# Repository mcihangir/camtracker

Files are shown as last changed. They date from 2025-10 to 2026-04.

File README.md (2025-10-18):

# SmartNFC

## Description
**SmartNFC** is an Android Virtual POS Application designed to operate on Android 13/14.

## Project Information
- **Project Name**: SmartNFC
- **Description**: Android Virtual POS Application
- **Start Date**: 2024-06-17
- **Firmware/SDK Version**: Android 13/14
- **Hardware Version**: v1.0

## Folder Structure
The project follows the directory structure outlined below:

```
SmartNFC/
│-- Block Diagrams/        # Product Block Diagram, PCB Connector Position
│-- Product Tree/          # Product Tree
│-- Documents/             # Design Documents, User Manuals, etc.
│-- Hardware/              # PCB Design Sources and libraries
│-- Software/              # Firmware and Applications
│-- Tools/                 # Software Tools
│-- Data/                  # Manufacturing data (PCB Gerber, Firmware Images, etc.)
```

## Folder Descriptions
- **Block Diagrams/**: Contains product-level block diagrams and PCB connector positioning.
- **Product Tree/**: Hierarchical structure of the product components.
- **Documents/**: Includes all necessary datasheets related to the hardware components and design documents.
- **Hardware/**: Contains PCB design source files and libraries.
- **Software/**: Includes firmware and application source code.
- **Tools/**: Collection of software tools required for development and debugging.
- **Data/**: Stores manufacturing data, including PCB Gerber files and firmware images.

## License
TBD

## Contact
For more details, reach out to the development team.

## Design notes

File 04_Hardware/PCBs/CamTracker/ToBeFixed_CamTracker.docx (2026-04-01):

1. D8 and D4 diodes should be replaced with a MOSFET-based solution or a proper power OR-ing design.

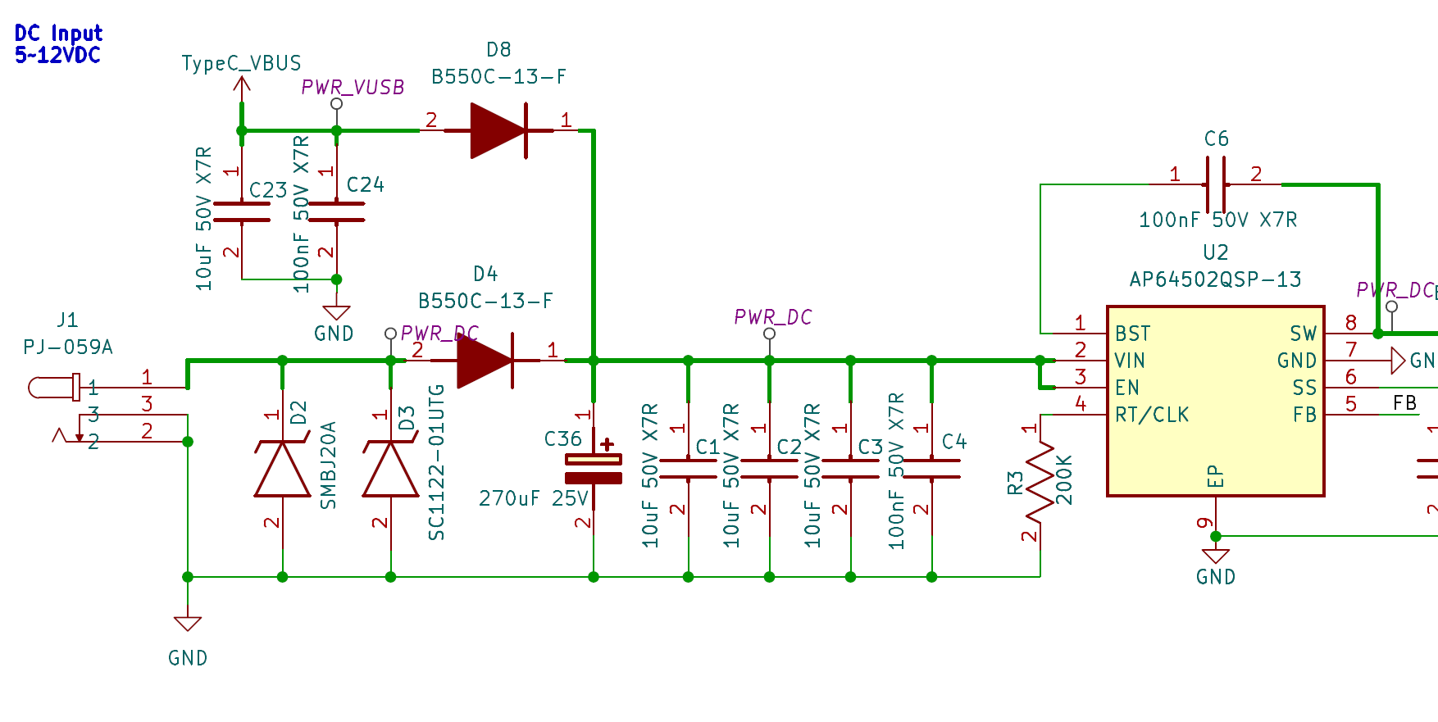
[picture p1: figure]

2. The R112 resistor should be set to 10K.

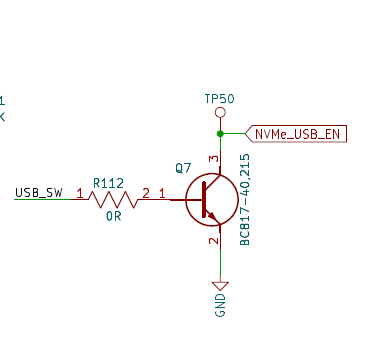
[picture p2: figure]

3. The D1 diode should be replaced with a MOSFET-based switching circuit.

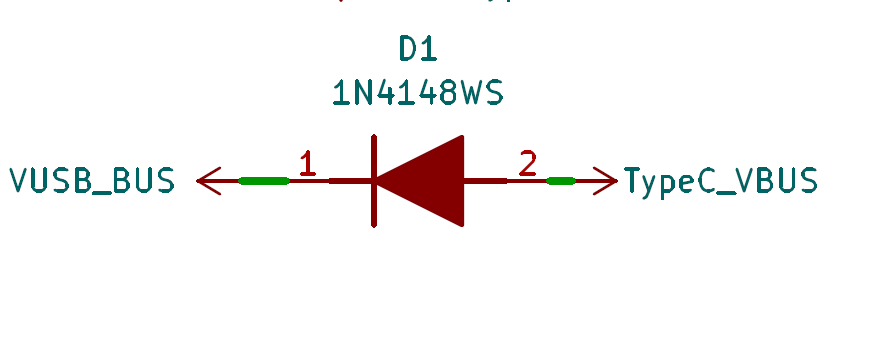
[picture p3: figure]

4. C149 should be used as 2.2 µF.

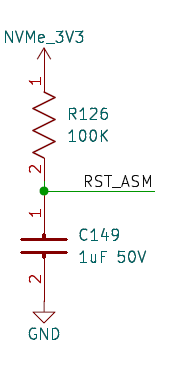
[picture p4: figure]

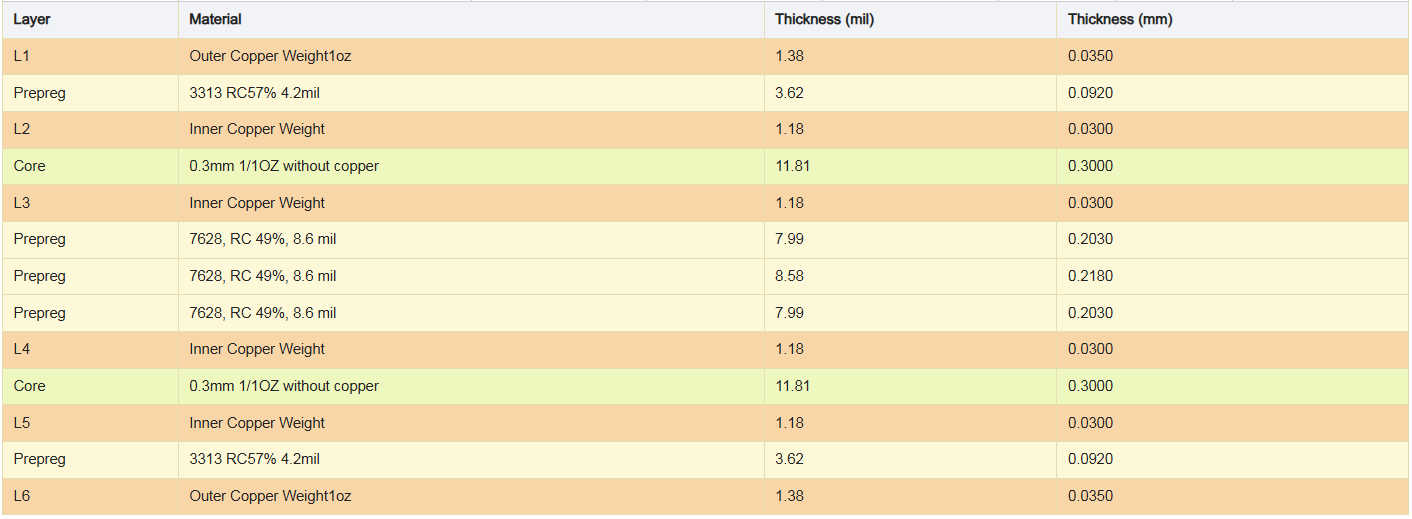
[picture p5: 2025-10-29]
04_Hardware/PCBs/CamTracker/Stackup.png

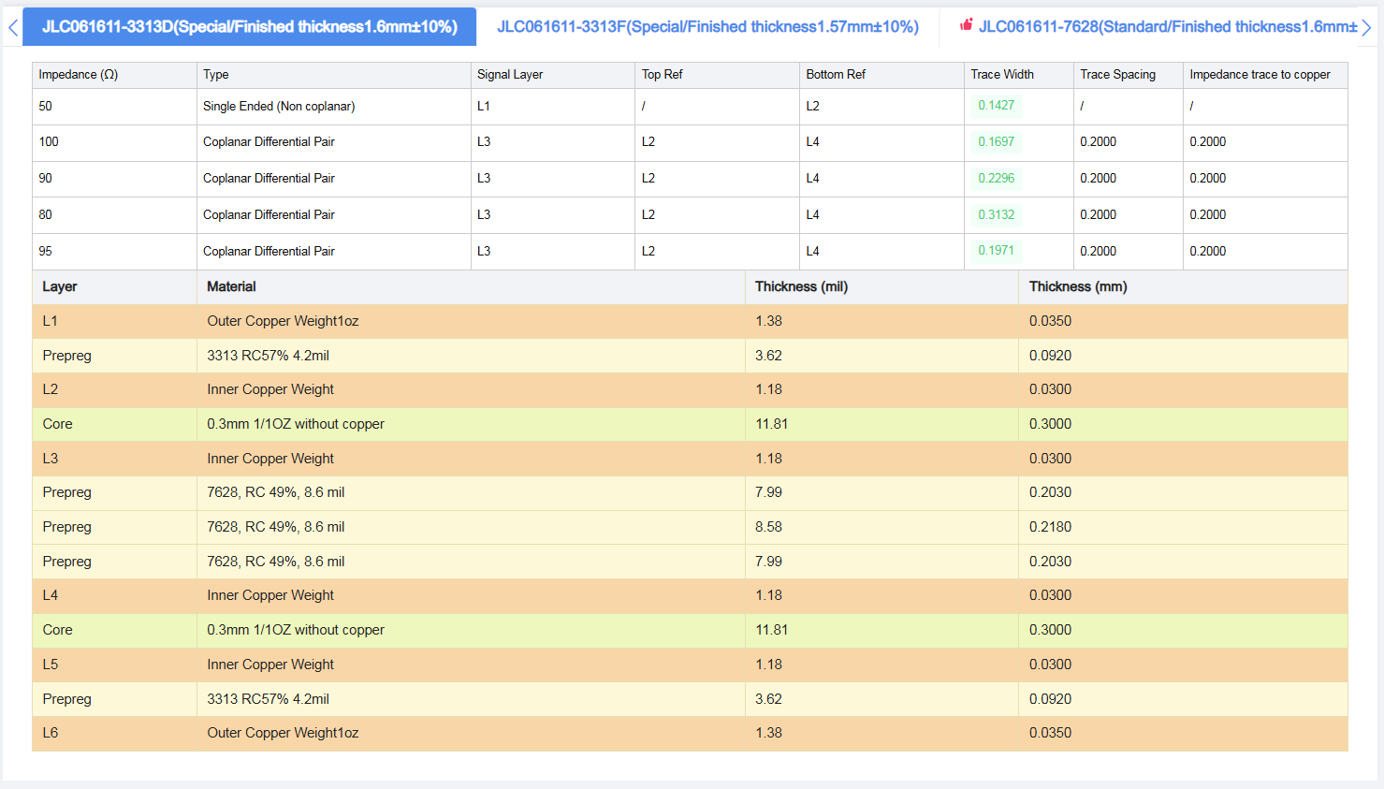
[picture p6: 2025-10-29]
04_Hardware/PCBs/CamTracker/Impedance.png

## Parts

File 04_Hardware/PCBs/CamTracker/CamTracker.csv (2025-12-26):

'#' | 'Reference' | 'Value' | 'Manufacturer' | 'Part Number' | 'Qty'
'1' | 'C1,C2,C3,C23,C25,C26,C27,C33,C34,C43,C122,C123,C124' | '10uF 50V X7R' | 'SAMSUNG' | 'CL31B106KBK6PJE' | '13'
'2' | 'C4,C6,C24' | '100nF 50V X7R' | 'TAIYO YUDEN' | 'UMK105B7104KVHF' | '3'
'3' | 'C5,C105' | '22uF 6.3V' | 'Murata Electronics' | 'GRM158R60J226ME01D' | '2'
'4' | 'C7,C11,C21,C29,C31,C35,C41,C45,C52,C57,C59,C73,C86,C87,C112,C113,C149' | '1uF 50V' | 'Murata Electronics' | 'GRM155R61H105KE05D' | '17'
'5' | 'C8,C10,C61,C68,C100,C106,C108,C109,C110' | '33pF 50V' | 'Murata Electronics' | 'GRM1555C1H330JA01D' | '9'
'6' | 'C9,C38' | '10nF 50V' | 'Murata Electronics' | 'GRM155R71H103KA88D' | '2'
'7' | 'C12,C13,C14,C22,C30,C32,C40,C46,C51,C53,C55,C65,C75,C84,C85,C88,C89,C90,C91,C92,C93,C94,C95,C101,C102,C104,C111,C125,C126,C127,C128,C129,C130,C131,C132,C133,C134,C135,C139,C140,C141,C142,C147' | '100nF 10V' | 'Murata Electronics' | 'GRM155R71A104KA01D' | '43'
'8' | 'C15' | '4.7uF 50V' | 'TAIYO YUDEN' | 'UMK325BJ475MM-T' | '1'
'9' | 'C16' | '100uF 10V' | 'KEMET' | 'T495D107K010ATE080' | '1'
'10' | 'C17,C18,C19,C20,C28,C66' | '47uF 10V X7S' | 'TDK' | 'CGA6P1X7S1A476M250AC' | '6'
'11' | 'C36' | '270uF 25V' | 'Panasonic' | '25SVPG270M' | '1'
'12' | 'C37,C103,C148' | '10pF 50V' | 'Murata Electronics' | 'GRM1555C1H100JA01D' | '3'
'13' | 'C42' | '4.7uF 10V' | 'TAIYO YUDEN' | 'LMK107BJ475KA-T' | '1'
'14' | 'C44,C98,C99' | '10uF 6.3V' | 'Murata Electronics' | 'GRM155R60J106ME15D' | '3'
'15' | 'C62,C63,C64,C67,C69,C70' | '22pF 50V' | 'Murata Electronics' | 'GRM1555C1H220JA01D' | '6'
'16' | 'C80,C107' | '100pF 50V' | 'Murata Electronics' | 'GRM1555C1H101JA01J' | '2'
'17' | 'C82,C83' | '15pF 50V' | 'Murata Electronics' | 'GRM1555C1H150JA01D' | '2'
'18' | 'C96,C97' | '1nF 50V' | 'Murata Electronics' | 'GRM1555C1H102JA01D' | '2'
'19' | 'C118,C119,C120,C121,C143,C144,C145,C146' | '220nF 10V' | 'Murata Electronics' | 'GRM155R61A224JE19D' | '8'
'20' | 'C136,C138' | '2.2uF 10V' | 'TAIYO YUDEN' | 'LMK107BJ225KA-T' | '2'
'21' | 'C137' | '22uF 25V' | 'Murata Electronics' | 'GRM21BR61E226ME44L' | '1'
'22' | 'D1' | '1N4148WS' | 'Onsemi' | '1N4148WS' | '1'
'23' | 'D2' | 'SMBJ20A' | 'Bourns' | 'SMBJ20A' | '1'
'24' | 'D3' | 'SC1122-01UTG' | 'LITTELFUSE' | 'SC1122-01UTG' | '1'
'25' | 'D4,D8' | 'B550C-13-F' | 'Diodes Incorporated' | 'B550C-13-F' | '2'
'26' | 'D5' | 'RB751S40' | 'ON Semiconductor' | 'RB751S40' | '1'
'27' | 'D6,D12' | 'SC1105-01UTG' | 'LITTELFUSE' | 'SC1105-01UTG' | '2'
'28' | 'D7' | 'ESD9B5.0ST5G' | 'ON Semiconductor' | 'ESD9B5.0ST5G' | '1'
'29' | 'D9,D19,D20,D21,D22,D23,D25,D26,D27,D28,D29,D30' | 'SC1205-01ETG' | 'Littelfuse' | 'SC1205-01ETG' | '12'
'30' | 'D11,D18' | 'SP0402U-ULC-02ETG' | 'LITTELFUSE' | 'SP0402U-ULC-02ETG' | '2'
'31' | 'D24' | 'SRV05-4.TCT' | 'SEMTECH' | 'SRV05-4.TCT' | '1'
'32' | 'FB1,FB2,FB3' | '110Ohm 1200mA' | 'Wurth Elektronik' | '74269242111' | '3'
'33' | 'FL1,FL2,FL3,FL4,FL5,FL6' | 'LCFE121002A900TG' | 'LITTELFUSE' | 'LCFE121002A900TG' | '6'
'34' | 'IC1' | 'W25Q128JVSIM' | 'Winbond' | 'W25Q128JVSIM' | '1'
'35' | 'IC2,IC3' | 'AP7361E-33FGE-7' | 'Diodes Incorporated' | 'AP7361E-33FGE-7' | '2'
'36' | 'J1' | 'PJ-059A' | 'CUI Devices' | 'PJ-059A' | '1'
'37' | 'J2,J3,J21' | '67996-100HLF' | 'Amphenol Communications Solutions' | '67996-100HLF' | '3'
'38' | 'J4' | '~' | 'SHOU HAN(首韩)' | '1.25-4P LT' | '1'
'39' | 'J5' | '22-28-4034' | 'Molex' | '22-28-4034' | '1'
'40' | 'J6' | '2345986-1' | 'TE Connectivity' | '2345986-1' | '1'
'41' | 'J8,J9' | 'HX JN1.27-2X10 TP H4.9' | 'hanxia(韩下)' | 'HX JN1.27-2x10 TP H4.9' | '2'
'42' | 'J10,J15,J16,J17' | '1909763-1' | 'TE Connectivity' | '1909763-1' | '4'
'43' | 'J13' | '2336582-1' | 'TE Connectivity' | '2336582-1' | '1'
'44' | 'J18' | '2201778-1' | 'TE Connectivity' | '2201778-1' | '1'
'45' | 'J19' | '2174507-2' | 'TE Connectivity' | '2174507-2' | '1'
'46' | 'J27' | '53047-0210' | 'Molex' | '53047-0210' | '1'
'47' | 'J28' | 'Bus_M.2_Socket_M' | 'TE Connectivity' | '1-2199230-4' | '1'
'48' | 'L1' | 'ETQ-P4M6R8KVC 6.8uH 6.9A' | 'Panasonic' | 'ETQ-P4M6R8KVC' | '1'
'49' | 'L2' | '1uH 4.2A' | 'TAIYO YUDEN' | 'LSEUC3225HKT1R0M' | '1'
'50' | 'L4,L6' | '600ohm 100MHz' | 'Wurth Elektronik' | '7427927291' | '2'
'51' | 'L8' | '56nH' | 'Wurth Elektronik' | '744784156A' | '1'
'52' | 'L10' | '1uH 2.2A' | 'Wurth Elektronik' | '74404024010' | '1'
'53' | 'LED1' | 'SML-P11YTT86R' | 'ROHM Semiconductor' | 'SML-P11YTT86R' | '1'
'54' | 'LED2,LED4,LED5' | 'SML-P11VTT86R' | 'ROHM Semiconductor' | 'SML-P11VTT86R' | '3'
'55' | 'LED3' | 'LTPL-C0676WPGB' | 'Lite-On Inc.' | 'LTPL-C0676WPGB' | '1'
'56' | 'LS1' | 'SPKM.15.8.A' | 'Taoglas' | 'SPKM.15.8.A' | '1'
'57' | 'MK1' | 'CMM-3729AT-42316-TR' | 'Same Sky' | 'CMM-3729AT-42316-TR' | '1'
'58' | 'Q1,Q2,Q3,Q4,Q5,Q6,Q7,Q8,Q9,Q10,Q11' | 'BC817-40,215' | 'Nexperia' | 'BC817-40,215' | '11'
'59' | 'R2,R10' | '47K' | 'YAGEO' | 'RC0402JR-0747KL' | '2'
'60' | 'R3,R107,R127' | '200K' | 'YAGEO' | 'RC0402FR-07200KL' | '3'
'61' | 'R4' | '38K3' | 'YAGEO' | 'AF0402FR-0738K3L' | '1'
'62' | 'R5,R7,R15,R17,R21,R24,R28,R29,R30,R40,R41,R42,R43,R44,R45,R46,R47,R48,R49,R52,R54,R74,R84,R97,R98,R100,R101,R103,R105,R114,R115,R116,R120,R121' | '10K' | 'YAGEO' | 'RC0402JR-0710KL' | '34'
'63' | 'R6,R12,R13,R31,R50,R55,R56,R57,R58,R87,R112' | '0R' | 'Vishay' | 'CRCW08050000Z0EA' | '11'
'64' | 'R9' | '147K' | 'YAGEO' | 'RC0402FR-07147KL' | '1'
'65' | 'R11,R25,R33,R96,R99' | '4K7' | 'YAGEO' | 'RC0402JR-074K7L' | '5'
'66' | 'R18,R51,R53,R85,R86,R88,R89,R90,R102,R106,R110,R111' | '0R' | 'YAGEO' | 'RC0402JR-070RL' | '12'
'67' | 'R22,R64,R75,R126' | '100K' | 'YAGEO' | 'RC0402JR-07100KL' | '4'
'68' | 'R27' | '270K' | 'YAGEO' | 'RC0402FR-07270KL' | '1'
'69' | 'R32,R36,R37,R38,R39,R63,R91,R95' | '1K' | 'YAGEO' | 'RC0402JR-071KL' | '8'
'70' | 'R34' | '20K' | 'YAGEO' | 'RC0402JR-0720KL' | '1'
'71' | 'R35' | '27K' | 'YAGEO' | 'RC0402JR-0727KL' | '1'
'72' | 'R59,R60,R61,R62' | '2K2' | 'YAGEO' | 'RC0402JR-072K2L' | '4'
'73' | 'R65,R66,R67,R81,R82,R83' | '22R' | 'YAGEO' | 'RC0402JR-0722RL' | '6'
'74' | 'R68,R69,R70,R71,R72,R73' | '33R' | 'YAGEO' | 'RC0402JR-0733RL' | '6'
'75' | 'R76,R77,R78,R79,R80' | '51K' | 'YAGEO' | 'RC0402JR-0751KL' | '5'
'76' | 'R93,R94' | '27.4R' | 'YAGEO' | 'RC0402FR-0727R4P' | '2'
'77' | 'R104' | '56K' | 'YAGEO' | 'RC0402JR-0756KL' | '1'
'78' | 'R108' | '44K2' | 'YAGEO' | 'RC0402FR-0744K2L' | '1'
'79' | 'R109' | '5K1' | 'YAGEO' | 'RC0402JR-075K1L' | '1'
'80' | 'R125' | '12K1' | 'YAGEO' | 'RC0402FR-0712K1P ' | '1'
'81' | 'S1,S2,S3' | '436333033816' | 'Wurth Elektronik' | '436333033816' | '3'
'82' | 'S4' | 'JS102011JCQN' | 'CK COMPONENTS' | 'JS102011JCQN' | '1'
83' | 'U1' | 'SC206EEMDA-G51-UGNDA' | 'Quectel' | 'SC200EEMNA-E53-UGNDA' | '1'
84' | 'U2' | 'AP64502QSP-13' | 'Diodes Incorporated' | 'AP64502QSP-13' | '1'
85' | 'U3' | 'AP7335-WG-7' | 'Diodes Incorporated' | 'AP7335-WG-7' | '1'
86' | 'U6,U15' | 'AP61100Z6-7,AP61300Z6-7' | 'Diodes Incorporated' | 'AP61100Z6-7' | '2'
87' | 'U7,U9' | 'PI3USB4000DZUAEX' | 'Diodes Incorporated' | 'PI3USB4000DZUAEX' | '2'
88' | 'U10' | 'SGM804' | 'SGMICRO(圣邦微)' | 'SGM804-2.93YN5G/TR' | '1'
89' | 'U12' | 'RP2040' | 'RASPBERRY-PI' | 'SC0914(7)' | '1'
90' | 'U13' | 'PAM8302AASCR' | 'Diodes Incorporated' | 'PAM8302AASCR' | '1'
91' | 'U14' | 'ASM2362' | 'ASMedia' | 'ASM2362' | '1'
92' | 'Y1' | 'ABM8-272-T3' | 'ABRACON' | 'ABM8-272-T3' | '1'
93' | 'Y2' | '25MHz' | 'Diodes Incorporated' | 'FL2500188' | '1'

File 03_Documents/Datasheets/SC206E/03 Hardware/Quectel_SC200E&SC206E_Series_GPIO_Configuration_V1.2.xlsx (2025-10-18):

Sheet: Title Page
SC200E&SC206E Series
GPIO Configuration
Smart Module Series
Version: 1.2
Date: 2023-01-17
Status: Released

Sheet: Foreword
At Quectel, our aim is to provide timely and comprehensive services to our customers. If you require any assistance, please contact our headquarters:
Quectel Wireless Solutions Co., Ltd.
Building 5, Shanghai Business Park Phase III (Area B), No.1016 Tianlin Road, Minhang District, Shanghai 200233, China
Tel: +86 21 5108 6236
Email: info@quectel.com
Or our local office. For more information, please visit:
http://www.quectel.com/support/sales.htm
For technical support, or to report documentation errors, please visit:
http://www.quectel.com/support/technical.htm
Or email to: support@quectel.com
Legal Notices
We offer information as a service to you. The provided information is based on your requirements and we make every effort to ensure its quality. You agree that you are responsible for using independent analysis and evaluation in designing intended products, and we provide reference designs for illustrative purposes only. Before using any hardware, software or service guided by this document, please read this notice carefully. Even though we employ commercially reasonable efforts to provide the best possible experience, you hereby acknowledge and agree that this document and related services hereunder are provided to you on an “as available” basis. We may revise or restate this document from time to time at our sole discretion without any prior notice to you.
Use and Disclosure Restrictions
License Agreements
Documents and information provided by us shall be kept confidential, unless specific permission is granted. They shall not be accessed or used for any purpose except as expressly provided herein.
Copyright
Our and third-party products hereunder may contain copyrighted material. Such copyrighted material shall not be copied, reproduced, distributed, merged, published, translated, or modified without prior written consent. We and the third party have exclusive rights over copyrighted material. No license shall be granted or conveyed under any patents, copyrights, trademarks, or service mark rights. To avoid ambiguities, purchasing in any form cannot be deemed as granting a license other than the normal non-exclusive, royalty-free license to use the material. We reserve the right to take legal action for noncompliance with abovementioned requirements, unauthorized use, or other illegal or malicious use of the material.
Trademarks
Except as otherwise set forth herein, nothing in this document shall be construed as conferring any rights to use any trademark, trade name or name, abbreviation, or counterfeit product thereof owned by Quectel or any third party in advertising, publicity, or other aspects.
Third-Party Rights
This document may refer to hardware, software and/or documentation owned by one or more third parties (“third-party materials”). Use of such third-party materials shall be governed by all restrictions and obligations applicable thereto.
We make no warranty or representation, either express or implied, regarding the third-party materials, including but not limited to any implied or statutory, warranties of merchantability or fitness for a particular purpose, quiet enjoyment, system integration, information accuracy, and non-infringement of any third-party intellectual property rights with regard to the licensed technology or use thereof. Nothing herein constitutes a representation or warranty by us to either develop, enhance, modify, distribute, market, sell, offer for sale, or otherwise maintain production of any our products or any other hardware, software, device, tool, information, or product. We moreover disclaim any and all warranties arising from the course of dealing or usage of trade.
Privacy Policy
To implement module functionality, certain device data are uploaded to Quectel’s or third-party’s servers, including carriers, chipset suppliers or customer-designated servers. Quectel, strictly abiding by the relevant laws and regulations, shall retain, use, disclose or otherwise process relevant data for the purpose of performing the service only or as permitted by applicable laws. Before data interaction with third parties, please be informed of their privacy and data security policy.
Disclaimer
a) We acknowledge no liability for any injury or damage arising from the reliance upon the information
b) We shall bear no liability resulting from any inaccuracies or omissions, or from the use of the information contained herein.
c) While we have made every effort to ensure that the functions and features under development are free from errors, it is possible that they could contain errors, inaccuracies, and omissions. Unless otherwise provided by valid agreement, we make no warranties of any kind, either implied or express, and exclude all liability for any loss or damage suffered in connection with the use of features and functions under development, to the maximum extent permitted by law, regardless of whether such loss or damage may have been foreseeable.
d) We are not responsible for the accessibility, safety, accuracy, availability, legality, or completeness of information, advertising, commercial offers, products, services, and materials on third-party websites and third-party resources.
Copyright © Quectel Wireless Solutions Co., Ltd. 2023. All rights reserved.

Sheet: Revision History
Version | Date | Author | Description
- | 2021-08-05 | Dorian MENG | Creation of the document
1.0 | 2022-01-19 | Dorian MENG | First official release
1.1 | 2022-07-19 | Dorian MENG | Added applicable module: SC206E series.
1.2 | 2023-01-17 | Dorian MENG | Deleted the VBAT power domain of PMU_GPIO03 and PMU_GPIO04.

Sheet: GPIO Configuration
Interface | Pin No. | Pin Name | Pin Description (Default Function) | Power Domain | Wakeup | Status After Reset | Alternate Function 0 (GPIO No.) | Alternate Function 1 | Alternate Function 2 | Alternate Function 3 | Alternate Function 4 | Comment
GPIO | 33 | GPIO_28 | General-purpose input/output | 1.8 V | √ | B-PD:nppukp | GPIO_28 | CAM_MCLK3 | CCI_TIMER2 | - | -
 | 97 | GPIO_31 | General-purpose input/output | 1.8 V | √ | B-PD:nppukp | GPIO_31 | - | - | - | -
 | 99 | GPIO_32 | General-purpose input/output | 1.8 V | √ | B-PD:nppukp | GPIO_32 | - | CCI_TIMER3 | - | -
 | 107 | GPIO_35 | General-purpose input/output | 1.8 V | √ | B-PD:nppukp | GPIO_35 | ALPS_INT | - | - | -
 | 108 | GPIO_33 | General-purpose input/output | 1.8 V | √ | B-PD:nppukp | GPIO_33 | GYRO_INT | - | - | -
 | 109 | GPIO_34 | General-purpose input/output | 1.8 V | √ | B-PD:nppukp | GPIO_34 | MAG_INT | - | - | -
 | 110 | GPIO_36 | General-purpose input/output | 1.8 V | √ | B-PD:nppukp | GPIO_36 | ACCL_INT | - | - | -
 | 100 | GPIO_55 | General-purpose input/output | 1.8 V | - | B-PD:nppukp | GPIO_55 | - | - | - | -
 | 106 | GPIO_56 | General-purpose input/output | 1.8 V | - | B-PD:nppukp | GPIO_56 | - | - | - | -
 | 112 | GPIO_57 | General-purpose input/output | 1.8 V | - | B-PD:nppukp | GPIO_57 | - | - | - | - | Cannot be pulled up during startup.
 | 113 | GPIO_58 | General-purpose input/output | 1.8 V | - | B-PD:nppukp | GPIO_58 | - | - | - | -
 | 123 | GPIO_60 | General-purpose input/output | 1.8 V | - | B-PD:nppukp | GPIO_60 | - | - | - | -
 | 182 | GPIO_86 | General-purpose input/output | 1.8 V | √ | B-PD:nppukp | GPIO_86 | NFC_CLK_REQ | - | - | -
 | 177 | GPIO_112 | General-purpose input/output | 1.8 V | √ | B-PD:nppukp | GPIO_112 | - | LPI_I2C5_SCL | LPI_UART5_RX | -
 | 267 | GPIO_111 | General-purpose input/output | 1.8 V | - | B-PD:nppukp | GPIO_111 | - | LPI_I2C5_SDA | LPI_UART5_TX | -
 | 265 | GPIO_98 | General-purpose input/output | 1.8 V | - | B-PD:nppukp | GPIO_98 | LPI_MI2S0_CLK | LPI_DMIC1_CLK | - | -
 | 105 | GPIO_99 | General-purpose input/output | 1.8 V | √ | B-PD:nppukp | GPIO_99 | LPI_MI2S0_WS | LPI_DMIC1_DATA | - | -
 | 264 | GPIO_100 | General-purpose input/output | 1.8 V | - | B-PD:nppukp | GPIO_100 | LPI_MI2S0_DATA0 | LPI_DMIC2_CLK | - | -
 | 239 | GPIO_101 | General-purpose input/output | 1.8 V | √ | B-PD:nppukp | GPIO_101 | LPI_MI2S0_DATA1 | LPI_DMIC2_DATA | - | -
 | 104 | GPIO_102 | General-purpose input/output | 1.8 V | √ | B-PD:nppukp | GPIO_102 | LPI_MI2S1_CLK | - | - | -
 | 103 | GPIO_103 | General-purpose input/output | 1.8 V | √ | B-PD:nppukp | GPIO_103 | LPI_MI2S1_WS | - | - | -
 | 101 | GPIO_104 | General-purpose input/output | 1.8 V | √ | B-PD:nppukp | GPIO_104 | LPI_MI2S1_DATA0 | - | - | -
 | 102 | GPIO_105 | General-purpose input/output | 1.8 V | √ | B-PD:nppukp | GPIO_105 | LPI_MI2S1_DATA1 | - | - | -
 | 90 | GPIO_106 | General-purpose input/output | 1.8 V | √ | B-PD:nppukp | GPIO_106 | - | - | - | -
 | 98 | GPIO_107 | General-purpose input/output | 1.8 V | √ | B-PD:nppukp | GPIO_107 | - | - | - | -
 | 118 | GPIO_14 | General-purpose input/output | 1.8 V | √ | B-PD:nppukp | GPIO_14 | SPI_MISO | UART_CTS | I2C_SDA | - | QUP SE5.
 | 119 | GPIO_15 | General-purpose input/output | 1.8 V | - | B-PD:nppukp | GPIO_15 | SPI_MOSI | UART_RTS | I2C_SCL | -
 | 116 | GPIO_16 | General-purpose input/output | 1.8 V | - | B-PD:nppukp | GPIO_16 | SPI_SCLK | UART_TX | - | -
 | 117 | GPIO_17 | General-purpose input/output | 1.8 V | √ | B-PD:nppukp | GPIO_17 | SPI_CS_N | UART_RX | - | -
 | 124 | PMU_GPIO03 | General-purpose input/output | 1.8 V | - | IN/PD | PMU_GPIO03 | - | - | - | -
 | 115 | PMU_GPIO04 | General-purpose input/output | 1.8 V | - | IN/PD | PMU_GPIO04 | - | - | - | -
 | 127 | PMU_GPIO08 | General-purpose input/output | 1.8 V | - | IN/PD | PMU_GPIO08 | - | - | - | -
 | 201 | PMU_GPIO07 | General-purpose input/output | 1.8 V | - | IN/PD | PMU_GPIO07 | - | - | - | -
SD Card | 45 | SD_DET | SD card hot-plug detect | 1.8 V | √ | B-PD:nppukp | GPIO_88 | - | - | - | -
(U)SIM | 22 | USIM1_DET | (U)SIM1 card hot-plug detect | 1.8 V | √ | B-PD:nppukp | GPIO_79 | - | - | - | -
 | 17 | USIM2_DET | (U)SIM2 card hot-plug detect | 1.8 V | √ | B-PD:nppukp | GPIO_75 | - | - | - | -
TP | 30 | TP_INT | TP interrupt | 1.8 V | √ | B-PD:nppukp | GPIO_80 | SPI_CS_N | UART_RX | - | - | QUP SE2.
 | 31 | TP_RST | TP reset | 1.8 V | - | B-PD:nppukp | GPIO_71 | SPI_SCLK | UART_TX | - | -
 | 47 | TP_I2C_SCL | TP I2C clock | 1.8 V | - | B-PD:nppukp | GPIO_7 | SPI_MOSI | UART_RTS | I2C_SCL | - | 1. Need to be pulled up to 1.8 V externally. 2. Can be used for other I2C devices. 3. QUP SE2.
 | 48 | TP_I2C_SDA | TP I2C data | 1.8 V | √ | B-PD:nppukp | GPIO_6 | SPI_MISO | UART_CTS | I2C_SDA | -
LCM | 49 | LCD_RST | LCD reset | 1.8 V | - | B-PD:nppukp | GPIO_82 | - | - | - | -
 | 50 | LCD_TE | LCD tearing effect | 1.8 V | √ | B-PD:nppukp | GPIO_81 | - | - | - | -
Camera | 74 | CAM0_MCLK | Master clock of camera 0 | 1.8 V | - | B-PD:nppukp | GPIO_20 | - | - | - | -
 | 75 | CAM1_MCLK | Master clock of camera 1 | 1.8 V | - | B-PD:nppukp | GPIO_21 | - | - | - | -
 | 165 | CAM2_MCLK | Master clock of camera 2 | 1.8 V | √ | B-PD:nppukp | GPIO_27 | - | - | - | -
 | 79 | CAM0_RST | Reset of camera 0 | 1.8 V | √ | B-PD:nppukp | GPIO_18 | - | - | - | -
 | 81 | CAM1_RST | Reset of camera 1 | 1.8 V | √ | B-PD:nppukp | GPIO_19 | - | - | - | -
 | 164 | CAM2_RST | Reset of camera 2 | 1.8 V | √ | B-PD:nppukp | GPIO_24 | CCI_TIMER1 | - | - | -
 | 80 | CAM0_PWDN | Power down of camera 0 | 1.8 V | √ | B-PD:nppukp | GPIO_4 | SPI_MISO | UART_CTS | I2C_SDA | - | QUP SE1.
 | 82 | CAM1_PWDN | Power down of camera 1 | 1.8 V | - | B-PD:nppukp | GPIO_5 | SPI_MOSI | UART_RTS | I2C_SCL | -
 | 163 | CAM2_PWDN | Power down of camera 2 | 1.8 V | - | B-PD:nppukp | GPIO_108 | - | - | - | -
 | 83 | CAM0_I2C_SCL | I2C clock of camera 0 | 1.8 V | - | B-PD:nppukp | GPIO_23 | CCI_I2C_SCL0 | - | - | - | 1. Need to be pulled up to 1.8 V externally. 2. For I2C application, these pins can only be used for camera I2C and can not be connected to other I2C devices.
 | 84 | CAM0_I2C_SDA | I2C data of camera 0 | 1.8 V | - | B-PD:nppukp | GPIO_22 | CCI_I2C_SDA0 | - | - | -
 | 166 | CAM1_I2C_SCL | I2C clock of camera 1 | 1.8 V | - | B-PD:nppukp | GPIO_30 | CCI_I2C_SCL1 | - | - | -
 | 205 | CAM1_I2C_SDA | I2C data of camera 1 | 1.8 V | - | B-PD:nppukp | GPIO_29 | CCI_I2C_SDA1 | - | - | -
Keypad | 95 | VOL_UP | Volume up | 1.8 V | √ | B-PD:nppukp | GPIO_96 | SPI_MISO | UART_CTS | I2C_SDA | - | QUP SE4.
 | 96 | VOL_DOWN | Volume down | 1.8 V | √ | B-PD:nppukp | GPIO_97 | SPI_MOSI | UART_RTS | I2C_SCL | -
UART | 93 | DBG_RXD | Debug UART receive | 1.8 V | √ | B-PD:nppukp | GPIO_13 | SPI_CS_N | UART_RX | - | - | QUP SE4.
 | 94 | DBG_TXD | Debug UART transmit | 1.8 V | - | B-PD:nppukp | GPIO_12 | SPI_SCLK | UART_TX | - | -
 | 34 | UART0_TXD | UART0 transmit | 1.8 V | - | B-PD:nppukp | GPIO_2 | SPI_SCLK | UART_TX | - | - | QUP SE0.
 | 35 | UART0_RXD | UART0 receive | 1.8 V | √ | B-PD:nppukp | GPIO_3 | SPI_CS_N | UART_RX | - | -
 | 36 | UART0_CTS | DCE clear to send signal from DTE | 1.8 V | √ | B-PD:nppukp | GPIO_0 | SPI_MISO | UART_CTS | I2C_SDA | I3C_SDA
 | 37 | UART0_RTS | DCE request to send signal to DTE | 1.8 V | - | B-PD:nppukp | GPIO_1 | SPI_MOSI | UART_RTS | I2C_SCL | I3C_SCL
 | 154 | UART1_TXD | UART1 transmit | 1.8 V | √ | B-PU:nppukp | GPIO_69 | SPI_SCLK | UART_TX | - | - | QUP SE1.
 | 153 | UART1_RXD | UART1 receive | 1.8 V | √ | B-PD:nppukp | GPIO_70 | SPI_CS_N | UART_RX | - | -
Sensor | 91 | SENSOR_I2C_SCL | I2C clock for external sensor | 1.8 V | - | B-PD:nppukp | GPIO_110 | LPI_I3C0_SCL | - | - | - | 1. Need to be pulled up to 1.8 V externally. 2. For I2C application, these pins can only be used for sensor I2C and can not be connected to other I2C devices.
 | 92 | SENSOR_I2C_SDA | I2C data for external sensor | 1.8 V | √ | B-PD:nppukp | GPIO_109 | LPI_I3C0_SDA | - | - | -
ADC | 128 | ADC | General-purpose ADC interface | 1.8 V | - | IN/PD | PMU_GPIO06 | - | - | - | -
PWM | 29 | PWM | PWM output | 1.8 V | - | IN/PD | PMU_GPIO02 | - | - | - | -
NOTE: |  |  | 1 | Functional description of pins marked with "√": general-purpose interrupt, support wakeup function.
 |  |  | 2 | For more details about QUP SE, see sheet QUP Ports.
 |  |  | 3 | “B”: bidirectional digital with CMOS input.
 |  |  | 4 | "PD": pull-down.
 |  |  | 5 | "PU": pull-up.
 |  |  | 6 | "PD:nppukp": default pulldown with programmable options following the colon (:)
 |  |  | 7 | "PU:nppdkp": default pullup with programmable options following the colon (:)
 |  |  | 8 | "IN": input.
 |  |  | 9 | Example:"IN/PD" represents input and pull-down.
 |  |  | 10 | Please note that pins not shown in the table above cannot be multiplexed into GPIOs.

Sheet: QUP Ports
QUP Serial Engine | Lane | Pin No. | Pin Name | Alternate Function (GPIO No.) | Alternate Functions |  |  |  | Comment
QUP SE0 | Lane0 | 36 | UART0_CTS | GPIO_0 | SPI_MISO | UART_CTS | I2C_SDA | I3C_SDA | The QUP is flexible and programmable to support a wide range of serial interfaces (I2C, I3C, SPI, and UART). Please note that only one protocol can be selected in one QUP engine at a time. For example, function of UART and I2C can not be supported simultaneously. If the interface defined by one protocol occupies only part of lanes of one QUP engine, the spare lanes can only be used for GPIOs. For example, for QUP SE0, when pin 36 and pin 37 are used for I2C function, pin 34 and pin 35 can only be used as GPIOs. For I3C, IBI (In Band Interrupt) is not supported and separate interrupt line needs to be provisioned for I3C. For details, please contact Quectel technical support.
 | Lane1 | 37 | UART0_RTS | GPIO_1 | SPI_MOSI | UART_RTS | I2C_SCL | I3C_SCL
 | Lane2 | 34 | UART0_TXD | GPIO_2 | SPI_SCLK | UART_TX | - | -
 | Lane3 | 35 | UART0_RXD | GPIO_3 | SPI_CS_N | UART_RX | - | -
QUP SE1 | Lane0 | 80 | CAM0_PWDN | GPIO_4 | SPI_MISO | UART_CTS | I2C_SDA | -
 | Lane1 | 82 | CAM1_PWDN | GPIO_5 | SPI_MOSI | UART_RTS | I2C_SCL | -
 | Lane2 | 154 | UART1_TXD | GPIO_69 | SPI_SCLK | UART_TX | - | -
 | Lane3 | 153 | UART1_RXD | GPIO_70 | SPI_CS_N | UART_RX | - | -
QUP SE2 | Lane0 | 48 | TP_I2C_SDA | GPIO_6 | SPI_MISO | UART_CTS | I2C_SDA | -
 | Lane1 | 47 | TP_I2C_SCL | GPIO_7 | SPI_MOSI | UART_RTS | I2C_SCL | -
 | Lane2 | 31 | TP_RST | GPIO_71 | SPI_SCLK | UART_TX | - | -
 | Lane3 | 30 | TP_INT | GPIO_80 | SPI_CS_N | UART_RX | - | -
QUP SE4 | Lane0 | 95 | VOL_UP | GPIO_96 | SPI_MISO | UART_CTS | I2C_SDA | -
 | Lane1 | 96 | VOL_DOWN | GPIO_97 | SPI_MOSI | UART_RTS | I2C_SCL | -
 | Lane2 | 94 | DBG_TXD | GPIO_12 | SPI_SCLK | UART_TX | - | -
 | Lane3 | 93 | DBG_RXD | GPIO_13 | SPI_CS_N | UART_RX | - | -
QUP SE5 | Lane0 | 118 | GPIO_14 | GPIO_14 | SPI_MISO | UART_CTS | I2C_SDA | -
 | Lane1 | 119 | GPIO_15 | GPIO_15 | SPI_MOSI | UART_RTS | I2C_SCL | -
 | Lane2 | 116 | GPIO_16 | GPIO_16 | SPI_SCLK | UART_TX | - | -
 | Lane3 | 117 | GPIO_17 | GPIO_17 | SPI_CS_N | UART_RX | - | -

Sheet: I2S Application
No | Pin No. | Pin Name | Pin Multiplexing | Comment
1 | 265 | GPIO_98 | LPI_MI2S0_CLK
 | 105 | GPIO_99 | LPI_MI2S0_WS
 | 264 | GPIO_100 | LPI_MI2S0_DATA0
 | 239 | GPIO_101 | LPI_MI2S0_DATA1
2 | 104 | GPIO_102 | LPI_MI2S1_CLK
 | 103 | GPIO_103 | LPI_MI2S1_WS
 | 101 | GPIO_104 | LPI_MI2S1_DATA0
 | 102 | GPIO_105 | LPI_MI2S1_DATA1

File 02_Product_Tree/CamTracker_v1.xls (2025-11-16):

No | Ref | Component | Manufacturer | Manufacturer Part Number | Description | Qty | e
 |  | SOM
1 |  | Smart Module | Quectel | SC206E |  | 1
 |  | Power |  |  |  | 1
 |  | PMIC Switching Voltage Regulators 5A, 500kHz Step-Down Converter | Diodes Incorporated | AP64502QSP-13 | 3.8V for VBAT | 1
 |  | PMIC LDO 3.3V 1A | Diodes Incorporated | AP7361E-33FGE-7 | 3V3 For Cams
 |  | PMIC Switching Voltage Regulators 3A, DCDC | Diodes Incorporated | AP61300Z6-7 | 3V3 for NVMe
 |  | PMIC Switching Voltage Regulators 1A, DCDC | Diodes Incorporated | AP61100Z6-7 | 1.05V for NVMe | 1
 |  | PMIC LDO 300mA REG 35uA 2 to 6 Vin | Diodes Incorporated | AP7335-WG-7 | 3V3 for MCU | 1
 |  | MOSFET, Pch, -30V(Vdss), -10.0A(Id), (4.5V, 6.0V Drive) | ROHM Semiconductor | RQ7E100ATTCR
 |  | Connector Pluggable Terminal Blocks 2 Pos 5mm pitch Through Hole Header | Phoenix Contact | 1754436
 |  | MCU |  |  |  | 1
 |  | LDO 3A | Raspberry Pi | SC0914(7)
 |  | IC NOR Flash spiFlash, 3V, 128M-bit, 4Kb | Winbond | W25Q128JVSIM
 |  | Crystal 12MHz Ultra Miniature Ceramic SMD | ABRACON | ABM8-272-T3
 |  | Transistors BJT 0.2A 40V 1.5W NPN | onsemi | PZT3904T1G |  | 2
 |  | NVMe |  |  |  | 1
 |  | IC PCI Express(downstream port) to USB3.1(UFP) Bridge | AS Media | ASM2362
 |  | IC Power Distribution USB Power Switch EN Avtive Low | Diodes Incorporated | AP22654QWU-7
 |  | IC USB2 Switch | Diodes Incorporated | PI3USB4000DZUAEX
 |  | Crystal Ceramic 25Mhz 16pF | Diodes Incorporated | FL2500188
 |  | CON PCI Express/PCI Connectors M.2 0.5PITCH 4.2H KEY M 10U AU | TE Connectivity | 1-2199230-4
 |  | Standoffs & Spacers WA-SMSI SMT Steel M2 Intrnl NonStop | Wurth Elektronik | 9774050243R
 |  | Camera |  |  |  | 1
 |  | Connector 16P 2x8 1.27mm, Surface Mount | Amphenol ICC (FCI) | 20021521-00016T1LF
 |  | Auido |  |  |  | 1
 |  | IC Audio Amplifiers 2.5W MONO FILTERLESS | Diodes Incorporated | PAM8302AASCR |  | 1
 |  | Miniature Speaker, 8 Ohm, 1W, 0Hz to 20kHz, 89dB | MULTICOMP PRO | MP000291
 |  | Speakers 15mm Mini 8 Ohm | Taoglas | SPKM.15.8.A |  | 1
 |  | SIM & SD |  |  |  | 1
 |  | Nano SIM Conn 1.44mm w/Peg and Switch | GCT (https://www.mouser.com.tr/manufacturer/gct/) | SIM8066-6-1-14-01-A |  | 1
 |  | ESD Suppressors / TVS Diodes | Nexperia (https://www.mouser.com.tr/manufacturer/nexperia/) | PESD3V3L5UF,115 |  | 1
 |  | IC eSIM V-QFN8 MFF2 | ST | ST4SI2M0020TPIFW |  | 1
 |  | Memory Card Connectors Micro SD Hinged, SMT | GCT (https://www.mouser.com.tr/manufacturer/gct/) | MEM2061-01-188-00-A |  | 1
 |  | Connectors
 |  | CON Type-C USB | GCT | USB4080-03-A |  | 1
 |  | CON Micro-B USB | GCT | USB3076-30-A |  | 1
 |  | CON uFL RF | Wurth Elektronik | 636101112001 | u.FL/IPEX-1/MHF1 | 3
 |  |  |  | 1.25-4PLTDK
 |  | CON Headers & Wire Housings 2P WTB VERT | Molex | 78171-0002 | 2P For NFC Antenna | 1
 |  | CON DIP PIN HEADER 1x2PIN 2.54mm, 3A | Amphenol FCI (https://www.mouser.com.tr/manufacturer/fci/) | 67996-100HLF | Jumper | 1
 |  | CON DC Power Jack | CUI Devices | PJ-059A | Main Power Jack | 1
 |  | CON 3P 1.25mm Male | Molex | 53047-0310 | For Battery | 1
 |  | CON 2P 1.25mm Male | Molex | 53047-0210 | Audio | 1
 |  | CON 3P 2.54mm Male Header | Molex | 22-28-4034 | UARTs | 3
 |  | CON 12P 2.54mm Headers 2X11P | Molex | 10-89-7121 | GPIO+I2C+SPI | 1
 |  | Passive Components
 |  | Tact Switch Push | Wurth Elektronik | 436333033816 |  | 3
 |  | Diodes & TVS
 |  | TVS ESD Protection Diodes / TVS Diodes 20volts 5uA 18.6 Amps | Bourns | SMBJ20A |  | 2
 |  | TVS ESD Suppressors 12V 80A | Littelfuse | SC1122-01UTG | For VBAT & Jack | 2
 |  | TVS ESD Suppressors 5V 80A | Littelfuse | SC1105-01UTG | For VBAT & Jack | 2
 |  | TVS ESD Suppressors 5V 7A 7pF | Littelfuse | SC1205-01ETG | For Swtiches | 3
 |  | TVS ESD Suppressors RAILCLAMP 4-LINE 5V | Semtech (https://www.mouser.com.tr/manufacturer/semtech/) | SRV05-4.TCT | For TP 4 Channel | 1
 |  | TVS ESD Suppressors / TVS Diodes 5V .2pF 20kV 2CH | Littelfuse (https://www.mouser.com.tr/manufacturer/littelfuse/) | SP0402U-ULC-02ETG | For USB | 1
 |  | TVS Bi Vrwm=12V 100pF SOD-323 RO | Semtech (https://www.mouser.com.tr/manufacturer/semtech/) | SD12C.TCT | For DC Jack | 1
 |  | TVS Bi Vrwm=24V 100pF SOD-323 RO | Semtech (https://www.mouser.com.tr/manufacturer/semtech/) | SD24C.TCT | For DC Jack | 1
 |  | TVS Diodes ESD BiDirectional Vrwm=5V | Onsemi | ESD9B5.0ST5G | For battery | 1
 |  | Diode Schottky 20V 5A | Diodes Incorporated (https://www.mouser.com.tr/manufacturer/diodes-inc/) | B520C-13-F
 |  | Diode Schottky 50V 5A | Diodes Incorporated (https://www.mouser.com.tr/manufacturer/diodes-inc/) | B550C-13-F | For Jack | 1
 |  | Diode Schottky 40V 1A | Diodes Incorporated (https://www.mouser.com.tr/manufacturer/diodes-inc/) | B140WS-7 |  | 3
 |  | Diode Schottky 150mA | Nexperia | RB751S40,115 | For CTP | 1
 |  | Diode Small Signal Switching | Onsemi | 1N4148WS |  | 1
 |  | Driver
 |  | Ideal Diode Controller | TI | LM74700QDBVRQ1 | DCDC | 1
 |  | Transistors & MOSFETs
 |  | MOSFET 30V N-Channel | Alpha & Omega | AO3400A | DCDC | 1
 |  | Transistors - BJT 100 mA NPN /SOT23/TO-236AB | Nexperia | BC847C,215 | LED driver | 5
 |  | Transistors - BJT 500 mA NPN /SOT23/TO-236AB | Nexperia | BC817-40,215
 |  | LEDs
 |  | LED Red SMD Vf=1.8V If=1mA 0402 | ROHM Semiconductor | SML-P11VTT86R | IN/OUT | 2
 |  | LED Orange SMD Vf=1.8V If=1mA 0402 | ROHM Semiconductor | SML-P11DTT86R | IN/OUT | 1
 |  | LED Yellow SMD Vf=1.8V If=1mA 0402 | ROHM Semiconductor | SML-P11YTT86R | IN/OUT | 2
 |  | LED Yellow-Green SMD Vf=1.9V If=5mA 0603 | Lite-On | LTST-C193KGKT-5A | Charging LED | 1
 |  | LED RGB 2.2V 3.3V 3.3V | Wurth Elektronik (https://www.mouser.com.tr/manufacturer/wurth-elektronik/) | 150141M173100 | 4 Pin | NA
 |  | LED High Power White Vf=3.7V | Lite-On Inc. (https://www.mouser.com.tr/manufacturer/cree/) | LTPL-C034UVH405 | For Camera Flashing | 1
 |  | LED High Power White Vf=3.3V | Lite-On Inc. (https://www.mouser.com.tr/manufacturer/cree/) | LTPL-C0676WPGB | For Camera Flashing
 |  | Inductors & Ferrite Beads
 |  | IND Power Inductors - 6.8uH 20.35mOhms 6.9A | Panasonic (https://www.mouser.com.tr/manufacturer/panasonicec/) | ETQ-P4M6R8KVK
 |  | IND Power Inductors - 1uH 20.35mOhms 5A | TAIYO YUDEN | LSEUC3225HKT1R0M
 |  | IND 56nH 1.6ohm 200mA | Wurth Elektronik | 744784156A | For GNSS | 1
 |  | IND 160nH 100mohm 1A | Murata | LQW18CNR16J00D
 |  | IND Power Inductors -1uH 2.2A DCR=37mOhms | Wurth Elektronik (https://www.mouser.com.tr/manufacturer/wurth-elektronik/) | 74404024010 | For Camera 1V1 | 1
 |  | IND Power Inductors - 15uH 34.1mOhms 20% 3650mA | TAIYO YUDEN (https://www.mouser.com.tr/manufacturer/taiyo-yuden/) | NS10155T150MNA | For RT8279GSP | 1
 |  | IND 22uH 1.364ohm 0.46A 2.5x2.0mm | TDK | VLS252010CX-220M-1 | For LCD Backlight | 1
 |  | Ferrite Bead 600Ohm 100MHz 300mA DCR=0.6ohm 0402 | Wurth Elektronik (https://www.mouser.com.tr/manufacturer/wurth-elektronik/) | 7427927291 | For LCD | 3
 |  | Ferrite Bead 70Ohm 100MHz 1200mA 0402 | Wurth Elektronik (https://www.mouser.com.tr/manufacturer/wurth-elektronik/) | 7427927370 | For Camera | 1
 |  | Ferrite Bead 110Ohm 1200mA DCR=0.09Ohms 0402 | Wurth Elektronik (https://www.mouser.com.tr/manufacturer/wurth-elektronik/) | 74269242111 | Audio | 1
 |  | Common Mode Chokes / Filters 90ohms | Littelfuse (https://www.mouser.com.tr/manufacturer/littelfuse/) | LCFE121002A900TG | For LCD and Cam | 8
 |  | Capacitors
 |  | CAP C0G 0.3pF +/-5% 50V CH0402 H0.55mm RO | Murata Electronics | GCM1555C1HR30BA16D
 |  | CAP C0G 10pF +/-5% 50V CH0402 H0.55mm RO | Murata Electronics | GRM1555C1H100JA01D
 |  | CAP C0G 15pF +/-5% 50V CH0402 H0.55mm RO | Murata Electronics | GRM1555C1H150JA01D
 |  | CAP C0G 22pF +/-5% 50V CH0402 H0.55mm RO | Murata Electronics | GRM1555C1H220JA01D
 |  | CAP C0G 33pF +/-5% 50V CH0402 H0.55mm RO | Murata Electronics | GRM1555C1H330JA01D
 |  | CAP C0G 39pF +/-5% 50V 0603 | Samsung Electro-Mechanics | CL10C390FB81PNC
 |  | CAP C0G 47pF +/-5% 50V 0603 | KYOCERA AVX | 06035A470FAT2A
 |  | CAP C0G 68pF +/-5% 50V 0603 | KYOCERA AVX | 06035A560FAT2A
 |  | CAP C0G 68pF +/-5% 50V 0603 | KYOCERA AVX | 06035A680FAT2A
 |  | CAP C0G 82pF +/-5% 50V CH0402 H0.55mm RO | Murata Electronics | GRM1555C1H820JA01D
 |  | CAP C0G 100pF +/-5% 50V CH0402 H0.55mm RO | Murata Electronics | GRM1555C1H101JA01D
 |  | CAP C0G 120pF +/-5% 50V CH0402 H0.55mm RO | Murata Electronics | GRM1555C1H121JA01D
 |  | CAP 200pF +/-5% 50V 0603 | KEMET | C0603C201F5GACTU
 |  | CAP 750pF +/-5% 50V 0603 | KEMET | C0603C751F5GACTU
 |  | CAP C0G 1000pF +/-5% 50V CH0402 H0.55mm RO | Murata Electronics | GRM1555C1H102JA01D
 |  | CAP 1000pF +/-5% 50V 0603 | TDK | C1608C0G1H102F080AA
 |  | CAP 10nF 50V CH0402 | Murata Electronics | GRM155R71H103KA88D
 |  | CAP X7R 100nF +/-10% 10V CH0402 H0.55mm RO | Murata Electronics | GRM155R71A104KA01D
 |  | CAP X7R 100nF +/-10% 50V CH0402 | TAIYO YUDEN (https://www.mouser.com.tr/manufacturer/taiyo-yuden/) | UMK105B7104KVHF | For Jack | 1
 |  | CAP 220nF +/-10% 10V CH0402 | Murata Electronics | GRM155R61A224JE19D | For USB
 |  | CAP 330nF +/-10% 10V CH0402 | Murata Electronics | GRM155R61A334KE15D | For USB
 |  | CAP X5R 1uF +/-20% 50V CH0402 | Murata Electronics | GRM155R61H105KE05D
 |  | CAP 2.2uF +/-10% 10V CH0402 | Murata Electronics | GRT155R61A225KE01D
 |  | CAP X5R 4.7uF 6.3V CH0402 +/-20% | Murata Electronics | GRM155R60J475ME47D
 |  | CAP X5R 4.7uF 10V CH0603 +/-10% | TAIYO YUDEN (https://www.mouser.com.tr/manufacturer/taiyo-yuden/) | LMK107BJ475KA-T | For VBAT
 |  | CAP X5R 4.7uF 50V Multilayer Ceramic Capacitors MLCC 20% | TAIYO YUDEN (https://www.mouser.com.tr/manufacturer/taiyo-yuden/) | UMK325BJ475MM-T | For Jack | 1
 |  | CAP 10uF 50V X7R 1206/3216 | Samsung Electro-Mechanics (https://www.mouser.com.tr/manufacturer/samsung-electro-mechanics/) | CL31B106KBK6PJE
 |  | CAP X5R 10uF 6.3V MLCC 20% 0402 | Murata Electronics | GRM155R60J106ME15D
 |  | CAP X5R 22uF 6.3V MLCC 20% 0402 | Murata Electronics | GRM158R60J226ME01D
 |  | CAP X5R 47uF 6.3V Multilayer Ceramic Capacitors MLCC 20% | Murata Electronics | GRM31CR60J476ME19L | For Jack | 1
 |  | CAP 47uF 10V MLCC X7S | TDK (https://www.mouser.com.tr/manufacturer/tdk/) | CGA6P1X7S1A476M250AC
 |  | CAP 100uF 10V Tantalum Capacitors ESR=80mOhms 10% | KEMET (https://www.mouser.com.tr/manufacturer/kemet-electronics/) | T495D107K010ATE080 | For VBAT and Jack
 |  | CAP 100uF 16V Tantalum Capacitors ESR=100mOhms +/-20% | KEMET (https://www.mouser.com.tr/manufacturer/kemet-electronics/) | T495X107M016ATE1007280 | For Jack | 1
 |  | Resistors
 |  | RES MF 0R +/-5% 1/16W CH0402 RO | YAGEO (https://www.mouser.com.tr/manufacturer/yageo/) | RC0402JR-070RL
 |  | RES MF 0R 1/18W 0805 | Vishay / Dale | CRCW08050000Z0EA
 |  | RES 0.02R 1/2W 2010 Current Sense Resistors | Vishay / Dale | WSL2010R0200FEA
 |  | RES 0.02R 1/4W 0805 Current Sense Resistors | Vishay / Dale | RCWE080520L0FMEA
 |  | RES MF 2.4R +/-5% 1/16W CH0402 RO | YAGEO (https://www.mouser.com.tr/manufacturer/yageo/) | RC0402JR-072R4L
 |  | RES MF 2.7R 1/18W 0805 | Vishay / Dale | CRCW08052R70FKEA
 |  | RES MF 10R +/-5% 1/16W CH0402 RO | YAGEO (https://www.mouser.com.tr/manufacturer/yageo/) | RC0402JR-0710RL
 |  | RES MF 22R +/-5% 1/16W CH0402 RO | YAGEO (https://www.mouser.com.tr/manufacturer/yageo/) | RC0402JR-0722RL
 |  | RES MF 27.4R +/-5% 1/16W CH0402 RO | YAGEO (https://www.mouser.com.tr/manufacturer/yageo/) | RC0402FR-0727R4P |  | 2
 |  | RES MF 33R +/-5% 1/16W CH0402 RO | YAGEO (https://www.mouser.com.tr/manufacturer/yageo/) | RC0402JR-0733RL
 |  | RES MF 1K +/-5% 1/16W CH0402 RO | YAGEO (https://www.mouser.com.tr/manufacturer/yageo/) | RC0402JR-071KL
 |  | RES MF 2.2K +/-5% 1/16W CH0402 RO | YAGEO (https://www.mouser.com.tr/manufacturer/yageo/) | RC0402JR-072K2L
 |  | RES MF 2.2K +/-5% 0603 | Panasonic | ERJ-3GEYJ222V
 |  | RES MF 4.7K +/-5% 1/16W CH0402 RO | YAGEO (https://www.mouser.com.tr/manufacturer/yageo/) | RC0402JR-074K7L
 |  | RES MF 10K +/-5% 1/16W CH0402 RO | YAGEO | RC0402JR-0710KL
 |  | RES MF 20K +/-5% 1/16W CH0402 RO | YAGEO (https://www.mouser.com.tr/manufacturer/yageo/) | RC0402JR-0720KL
 |  | RES MF 27K +/-5% 1/16W CH0402 RO | YAGEO (https://www.mouser.com.tr/manufacturer/yageo/) | RC0402JR-0727KL
 |  | RES MF 37.4K +/-5% 1/16W CH0402 RO | YAGEO (https://www.mouser.com.tr/manufacturer/yageo/) | RT1206FRE0737K4L
 |  | RES MF 38.3K +/-5% 1/16W CH0402 RO | YAGEO (https://www.mouser.com.tr/manufacturer/yageo/) | AF0402FR-0738K3L
 |  | RES MF 43K +/-5% 1/16W CH0402 RO | YAGEO (https://www.mouser.com.tr/manufacturer/yageo/) | RC0402JR-0743KL
 |  | RES MF 44K2 +/-5% 1/16W CH0402 RO | YAGEO (https://www.mouser.com.tr/manufacturer/yageo/) | RC0402FR-0744K2L
 |  | RES MF 47K +/-5% 1/16W CH0402 RO | YAGEO (https://www.mouser.com.tr/manufacturer/yageo/) | RC0402JR-0747KL
 |  | RES MF 51K +/-5% 1/16W CH0402 RO | YAGEO (https://www.mouser.com.tr/manufacturer/yageo/) | RC0402JR-0751KL
 |  | RES MF 52.3K +/-5% 1/16W CH0402 RO | YAGEO (https://www.mouser.com.tr/manufacturer/yageo/) | RT0402BRD0752K3L
 |  | RES MF 100K +/-5% 1/16W CH0402 RO | YAGEO | RC0402JR-07100KL
 |  | RES MF 120K +/-1% 1/16W CH0402 RO | YAGEO | RC0402FR-07120KL
 |  | RES MF 147K +/-1% 1/16W CH0402 RO | YAGEO | RC0402FR-07147KL
 |  | RES MF 160K +/-1% 1/16W CH0402 RO | YAGEO | RC0402FR-07160KL
 |  | RES MF 200K +/-1% 1/16W CH0402 RO | YAGEO | RC0402FR-07200KL
 |  | RES MF 220K +/-1% 1/16W CH0402 RO | YAGEO | RC0402FR-07220KL
 |  | RES MF 240K +/-1% 1/16W CH0402 RO | YAGEO (https://www.mouser.com.tr/manufacturer/yageo/) | RC0402FR-07240KL
 |  | Antennas
 |  | Main & Div | Quectel | YF0028AA
 |  | WiFi & Bluetooth | Quectel | YF0023AA
 |  | GNSS | Quectel | YFGA006AA
 |  | Battery
 |  | Batttery Li-Polymer 3.7V 5000 mAh Devreli-3.0A Rechargeable | Power-Xtra | PX105080
 |  | Batttery Li-Polymer 3.7V 3000 mAh - Devreli - 3.0A - Rechargeable | Power-Xtra | PX964161

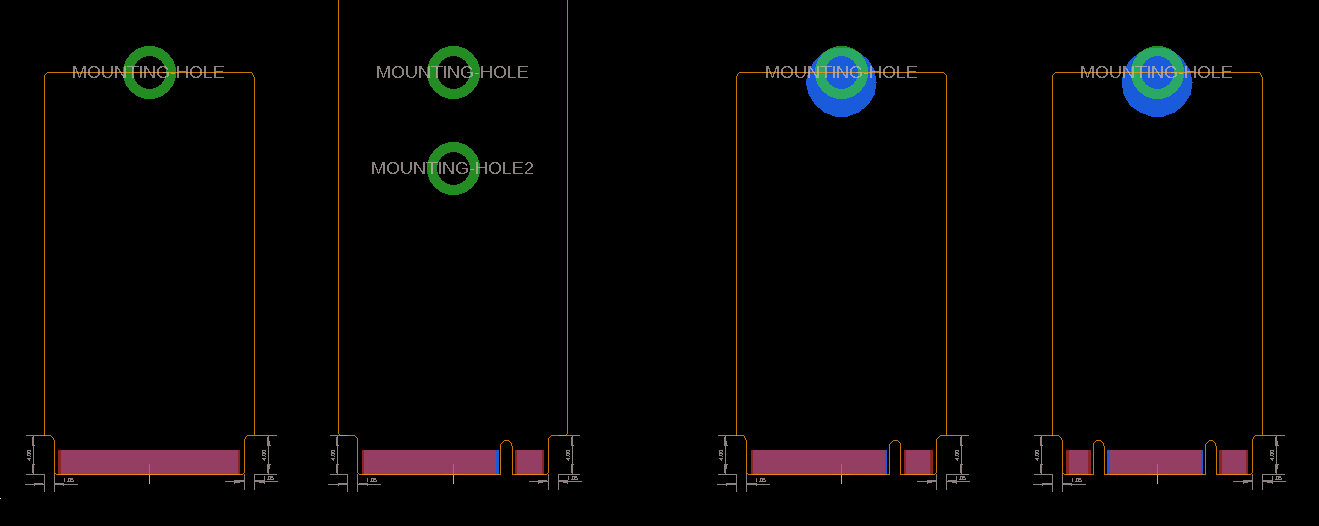
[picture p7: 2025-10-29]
04_Hardware/PCBs/CamTracker/KiCad_Libs/Components/nvme_ssd/M.2-Card-Footprints-main/preview.png

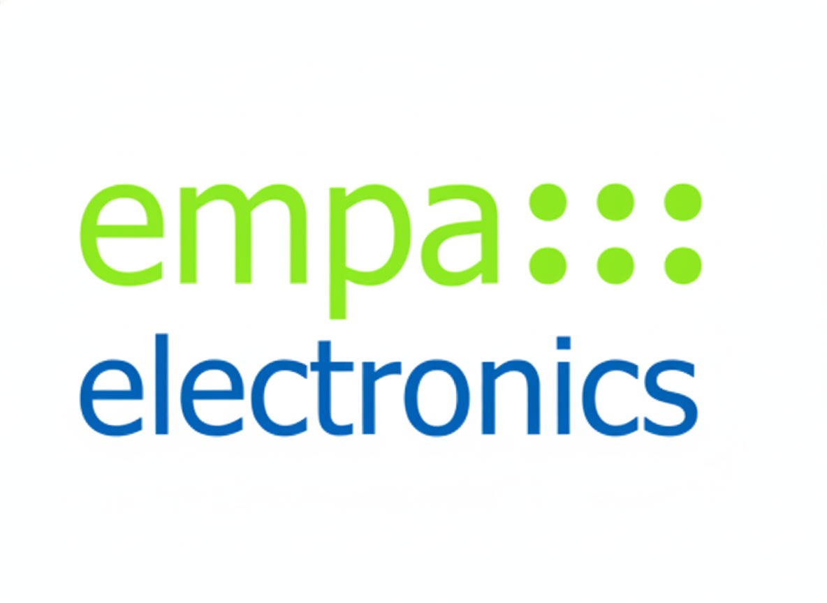
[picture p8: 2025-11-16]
04_Hardware/PCBs/CamTracker/KiCad_Libs/Components/EMPA/empa.png

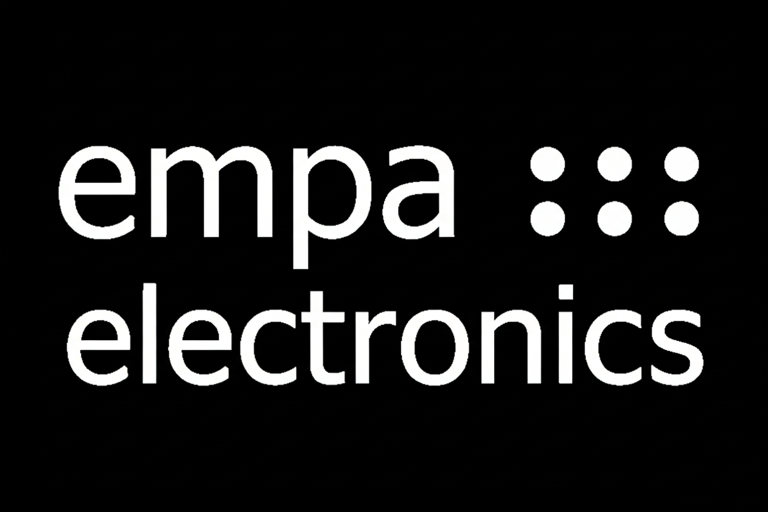
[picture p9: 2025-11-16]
04_Hardware/PCBs/CamTracker/KiCad_Libs/Components/EMPA/empa_5.png

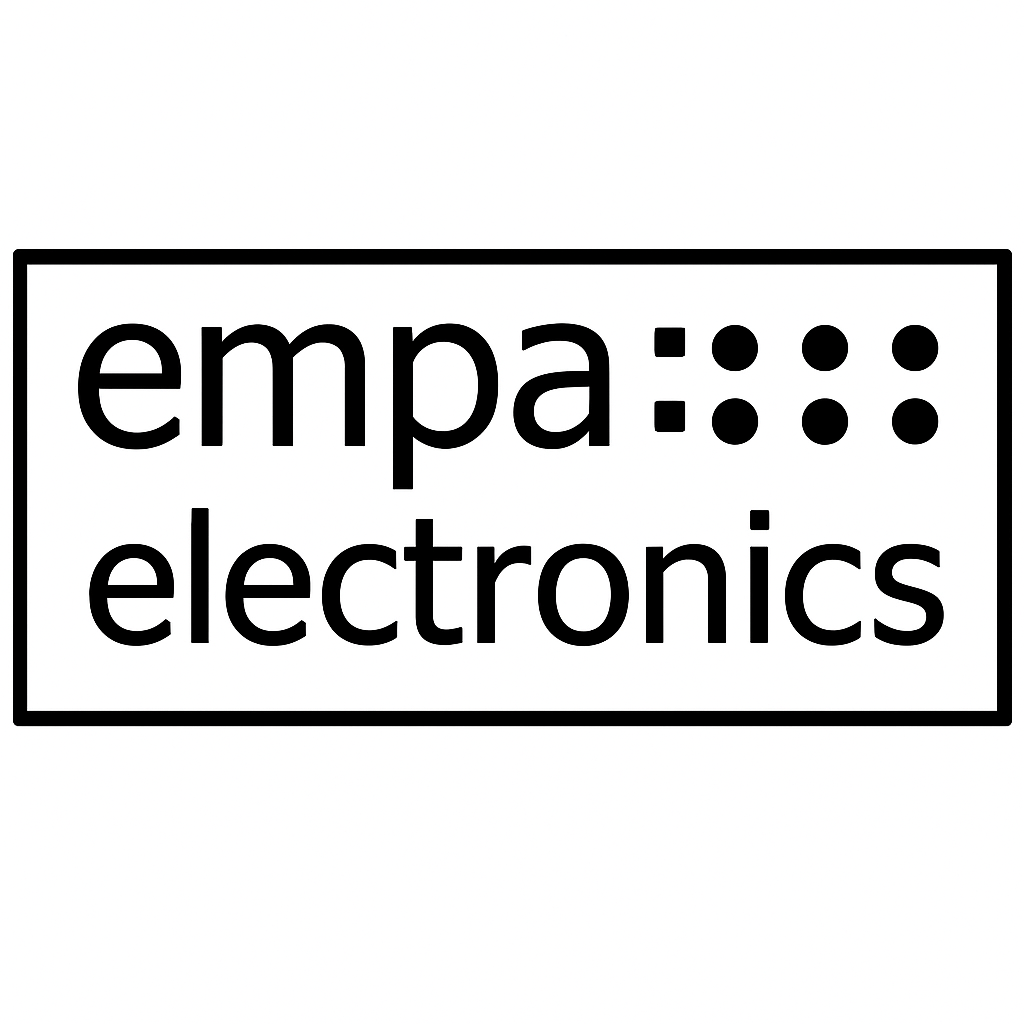
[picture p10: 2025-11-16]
04_Hardware/PCBs/CamTracker/KiCad_Libs/Components/EMPA/empa_1.png

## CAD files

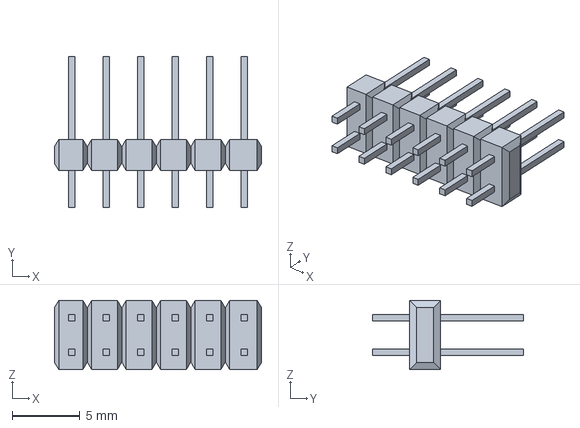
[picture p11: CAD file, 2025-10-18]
04_Hardware/PCBs/CamTracker/KiCad_Libs/Components/10-89-7121/3D/10-89-7121.stp
15.2 x 11.1 x 5.08 mm

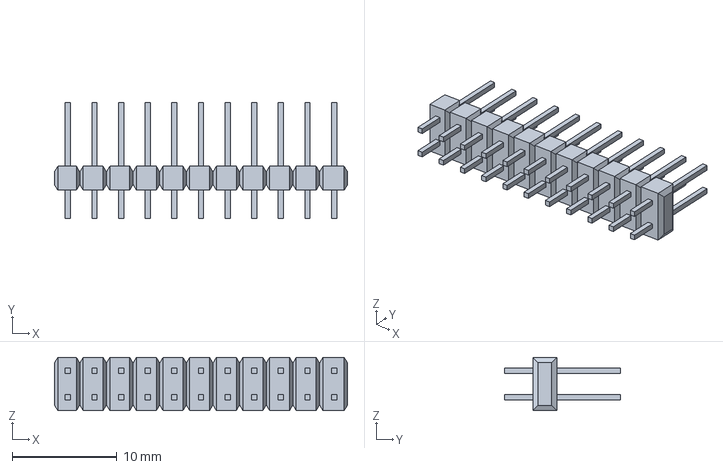
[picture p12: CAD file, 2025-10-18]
04_Hardware/PCBs/CamTracker/KiCad_Libs/Components/10-89-7221/3D/10-89-7221.stp
27.9 x 11.1 x 5.08 mm

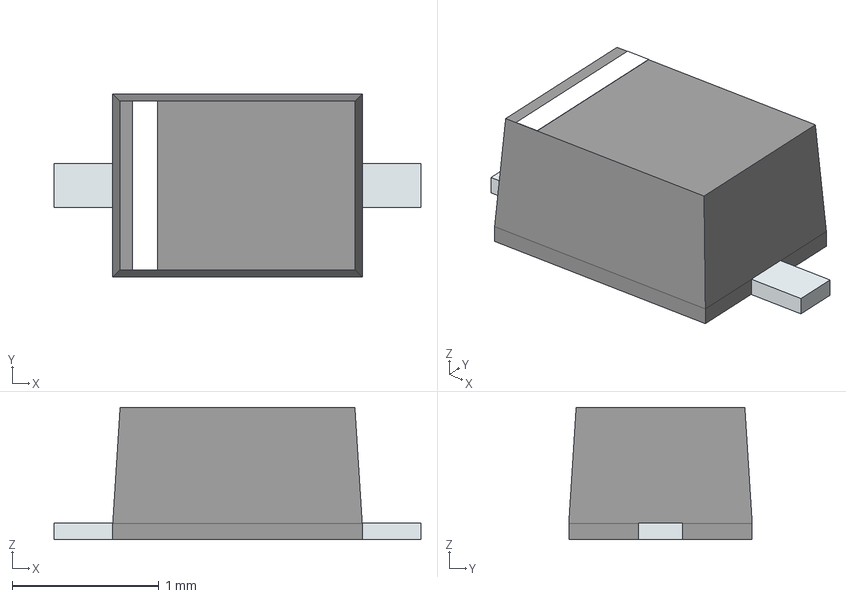
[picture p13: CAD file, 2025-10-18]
04_Hardware/PCBs/CamTracker/KiCad_Libs/Components/1N4148WS/3D/1N4148WS.stp
2.50 x 1.25 x 0.9 mm
PinKIdent
PinK
PinA

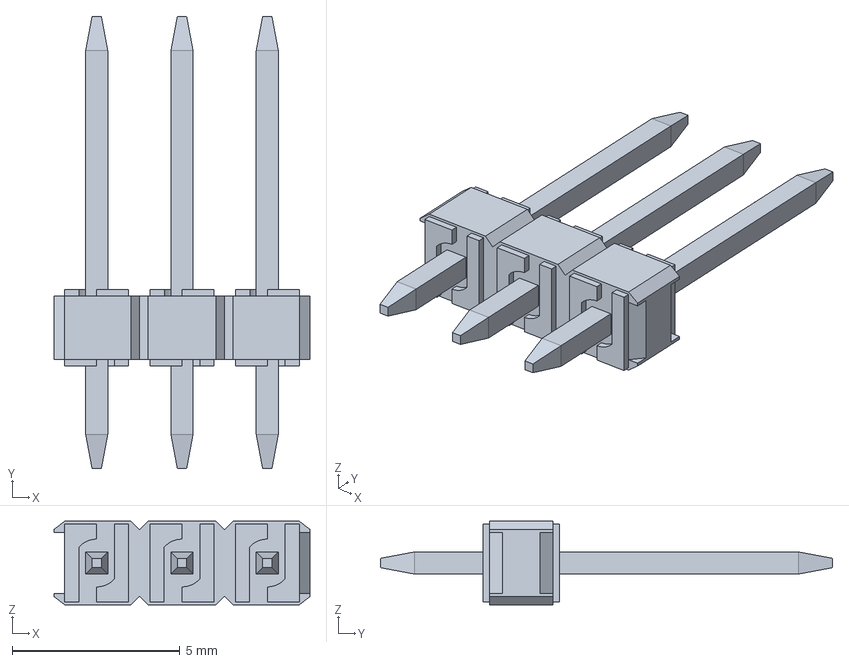
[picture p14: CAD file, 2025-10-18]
04_Hardware/PCBs/CamTracker/KiCad_Libs/Components/22-28-4034/3D/22-28-4034.stp
7.62 x 13.5 x 2.49 mm

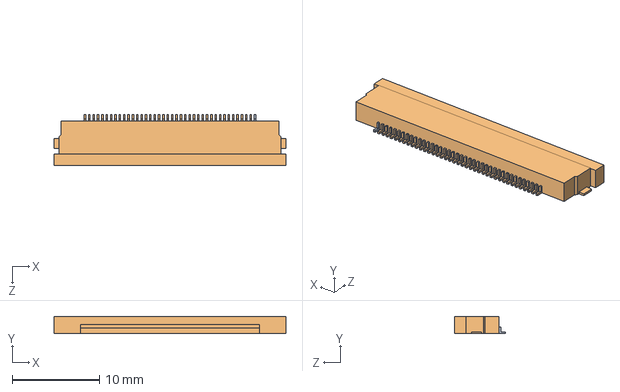
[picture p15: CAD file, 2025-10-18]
04_Hardware/PCBs/CamTracker/KiCad_Libs/Components/40FLZ-RSM2-R-TB/40FLZ-RSM2-R-TB.STEP
26.6 x 2.00 x 5.80 mm

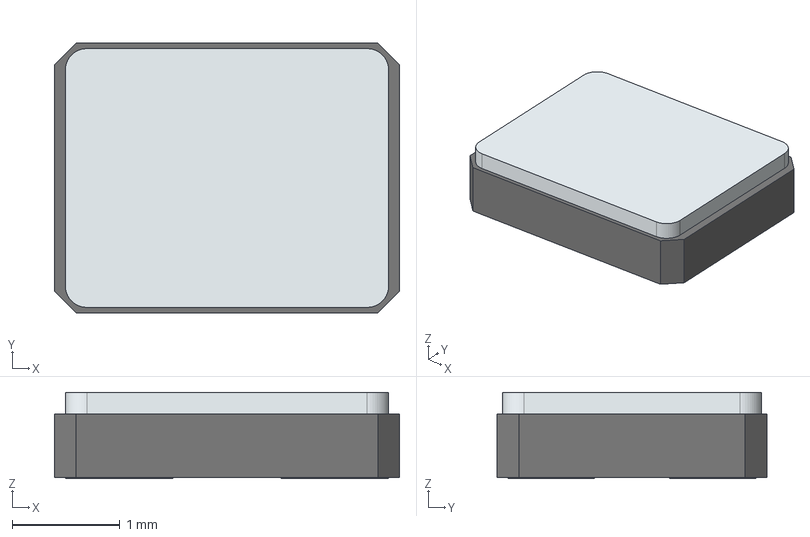
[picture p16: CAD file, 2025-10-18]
04_Hardware/PCBs/CamTracker/KiCad_Libs/Components/ABM8-27.120MHZ-10-D1G-T/3D/ABM8-27.120MHZ-10-D1G-T.stp
3.20 x 2.50 x 0.8 mm
solidBody
solidLid
solidTerminal

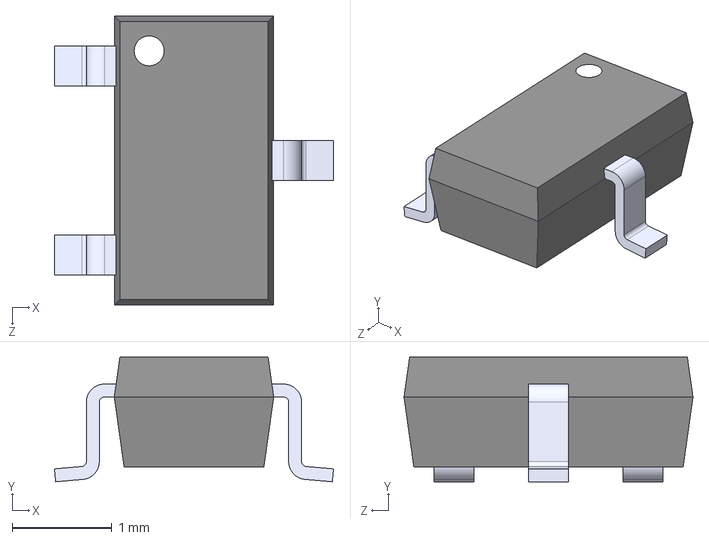
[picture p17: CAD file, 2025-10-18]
04_Hardware/PCBs/CamTracker/KiCad_Libs/Components/AO3400A/AO3400A.step
2.80 x 1.25 x 2.90 mm

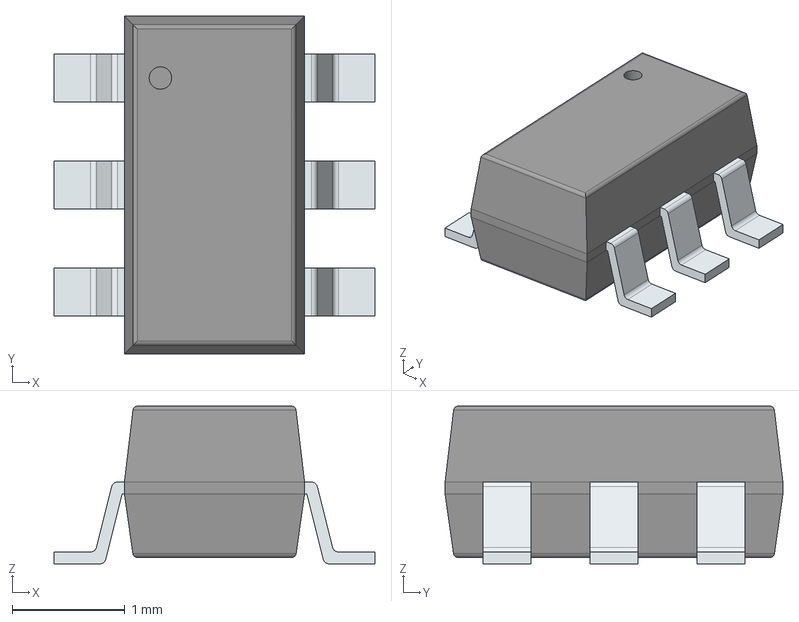
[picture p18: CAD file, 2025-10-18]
04_Hardware/PCBs/CamTracker/KiCad_Libs/Components/AP5724WG-7/3D/AP5724WG-7.stp
2.85 x 3.00 x 1.40 mm
PinsArrayLR

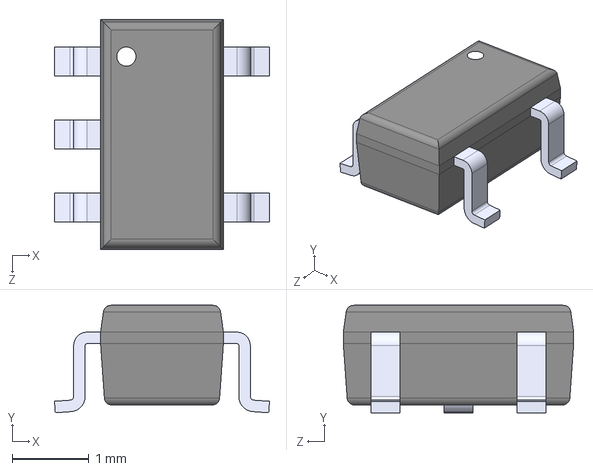
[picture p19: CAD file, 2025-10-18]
04_Hardware/PCBs/CamTracker/KiCad_Libs/Components/AP7335-WG-7/AP7335-WG-7.step
2.80 x 1.40 x 3.00 mm

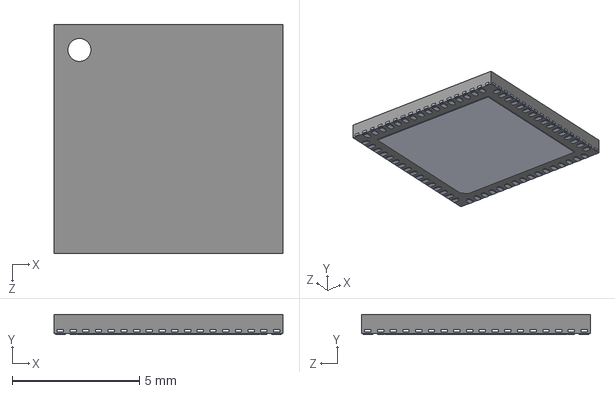
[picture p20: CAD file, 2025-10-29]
04_Hardware/PCBs/CamTracker/KiCad_Libs/Components/ASM2362_KiCad_Library/QFN50P905X905X75-65N.step
9.00 x 0.8 x 9.00 mm

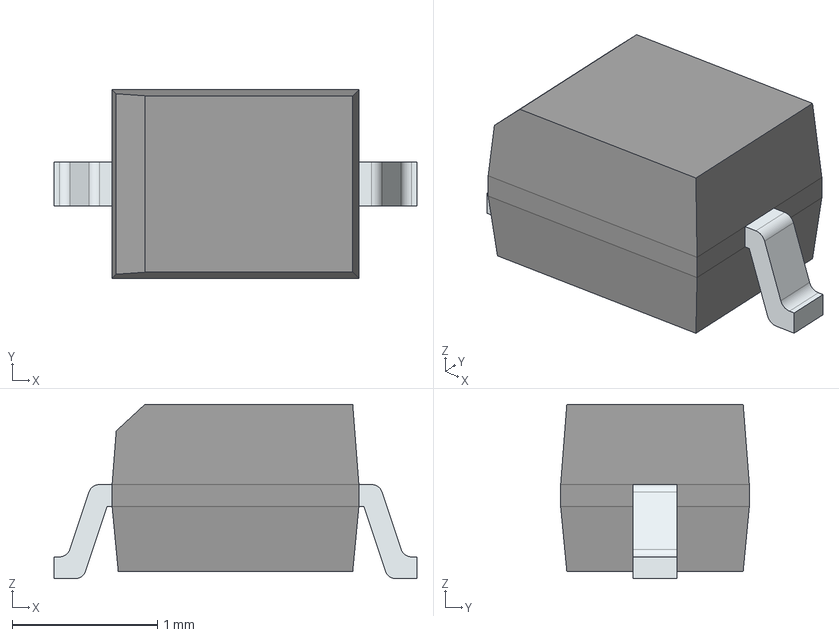
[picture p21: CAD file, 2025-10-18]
04_Hardware/PCBs/CamTracker/KiCad_Libs/Components/B140WS-7/3D/B140WS-7.stp
2.50 x 1.30 x 1.20 mm
FilletPinL
FilletPinR

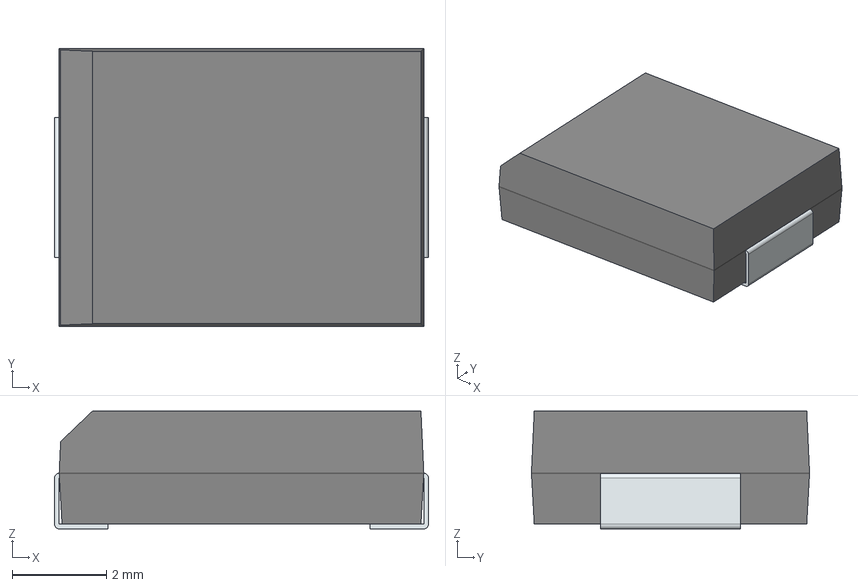
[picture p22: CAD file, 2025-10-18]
04_Hardware/PCBs/CamTracker/KiCad_Libs/Components/B550C-13-F/3D/B550C-13-F.stp
7.94 x 5.91 x 2.50 mm
FilletPin1
FilletPin2

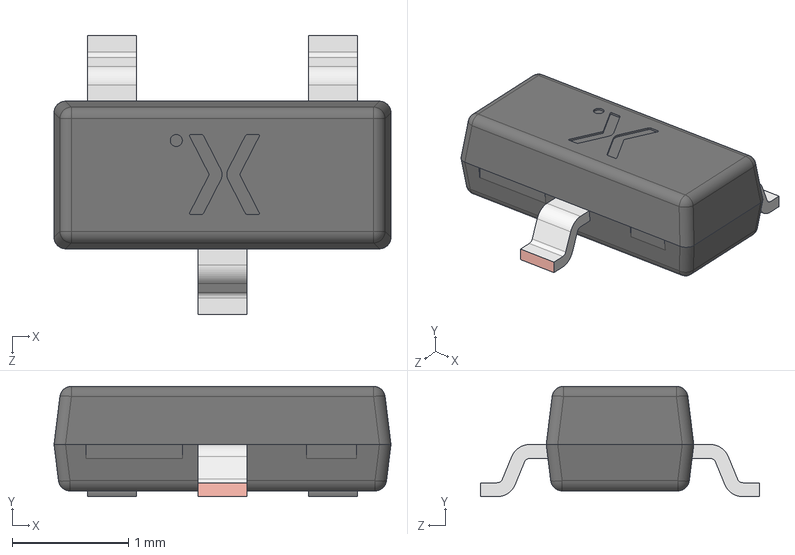
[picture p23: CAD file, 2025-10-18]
04_Hardware/PCBs/CamTracker/KiCad_Libs/Components/BC817-40,215/3D/BC817-40,215.stp
2.90 x 0.95 x 2.40 mm
SOT23 lower body
SOT23 Lead x 3
SOT23 Upper body

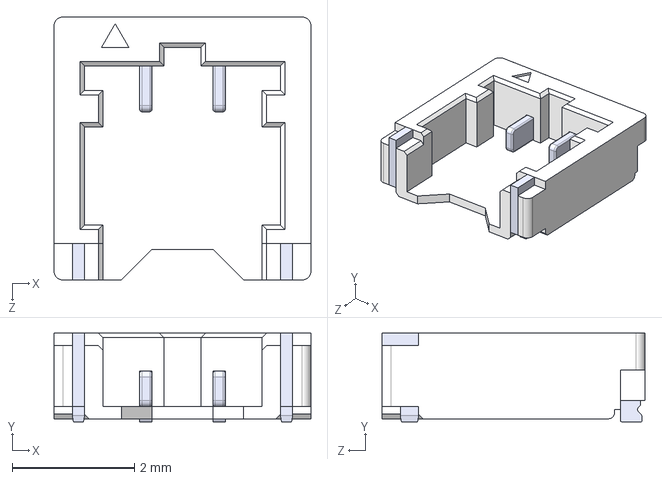
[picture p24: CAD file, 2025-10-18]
04_Hardware/PCBs/CamTracker/KiCad_Libs/Components/BM02B-ACHSS-GAN-ETF/BM02B-ACHSS-GAN-TF_LF__SN_.step
4.20 x 1.45 x 4.30 mm

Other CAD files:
04_Hardware/PCBs/CamTracker/KiCad_Libs/Components/C0603C751F5GACTU/3D/C0603C751F5GACTU.stp
04_Hardware/PCBs/CamTracker/KiCad_Libs/Components/046841027100846+/3D/006841027000.STEP
04_Hardware/PCBs/CamTracker/KiCad_Libs/Components/046841027100846+/3D/046841027100846+.stp
04_Hardware/PCBs/CamTracker/KiCad_Libs/Components/0781710002/0781710002.step
04_Hardware/PCBs/CamTracker/KiCad_Libs/Components/150141M173100/3D/150141M173100.stp
04_Hardware/PCBs/CamTracker/KiCad_Libs/Components/20021521_00016T1LF/3D/20021521-00016T1LF.stp
04_Hardware/PCBs/CamTracker/KiCad_Libs/Components/436333033816/436333033816.step
04_Hardware/PCBs/CamTracker/KiCad_Libs/Components/53047-0210/3D/53047-0210.stp
04_Hardware/PCBs/CamTracker/KiCad_Libs/Components/53047-0310/3D/53047-0310.stp
04_Hardware/PCBs/CamTracker/KiCad_Libs/Components/636101112001/636101112001.stp
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

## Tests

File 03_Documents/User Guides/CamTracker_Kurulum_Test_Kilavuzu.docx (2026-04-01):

# CamTracker Bring-up ve Test Dokümanı

# İÇİNDEKİLER 1. Bring-up (Kart Başlatma) 1.1 USB Modes 1.2 Debug UART 2. Test 2.1 WiFi Testi 2.2 SIM Testi 2.3 Network Testi 2.4 GNSS Testi 3. Referans Dokümanlar

# 1. Bring-up (Kart Başlatma)

Kart DC jack veya Type-C USB konnektörü üzerinden beslenebilir. Besleme girişi 5~12VDC aralığındadır.

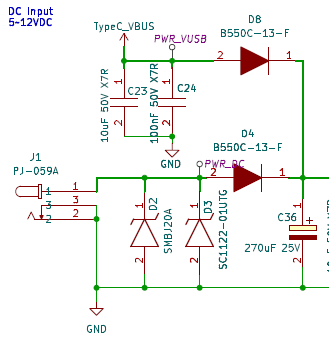
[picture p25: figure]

## 1.1 USB Modes

SC206E modülünün tek USB portu kart üzerindeki S4 switch ile Type-C konnektörüne veya NVMe SSD diske manuel olarak anahtarlanır.

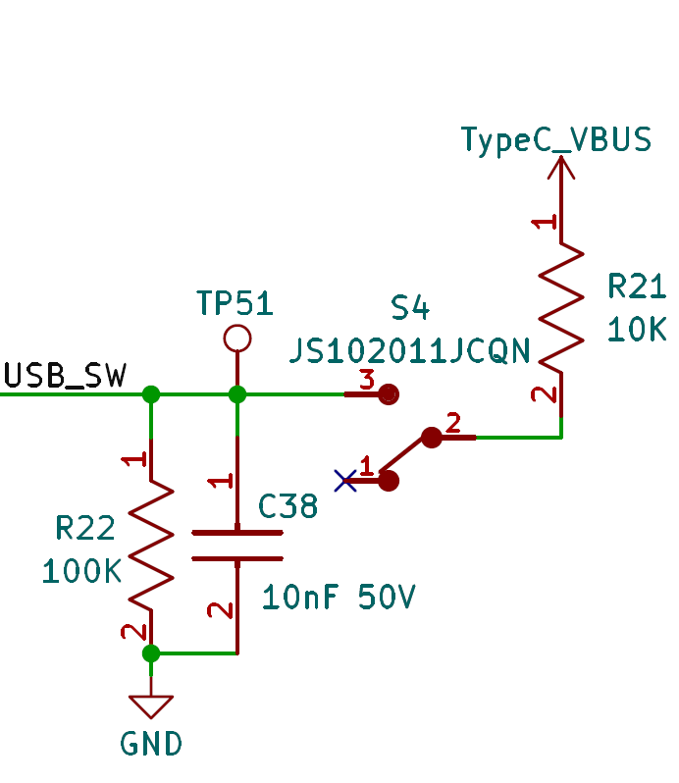
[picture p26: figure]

S4 switch 1 konumuna anahtarlanırsa NVMe disk kullanılır. Bu durumda TypeC_VBUS sinyali jumper ile kesilmelidir.

S4 switch 3 konumuna anahtarlanırsa USB Type-C konnektörüne yönlendirilir. Bu durumda TypeC_VBUS sinyali jumper ile sağlanmalıdır. Bu durumda modül PC tarafından algılanır ve QFIL ile imaj yükleme işlemi yapılabilir.

## 1.2 Debug UART

Modülün Linux shell'ine ulaşmak için Debug UART portu kullanılır. Debug UART voltaj seviyesi 1.8V'dur ve uygun dönüştürücü ile bilgisayara bağlanmalıdır.

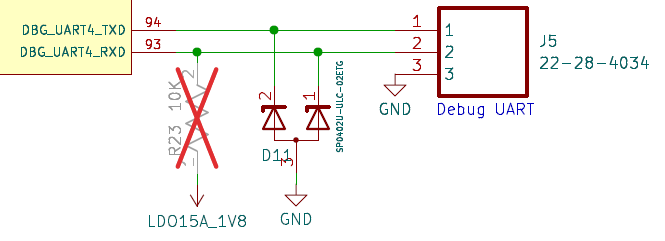
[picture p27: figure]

# 2. Test

## 2.1 WiFi Testi

ifconfig wlan0
ps | grep wpa
wpa_cli -i wlan0 status
wpa_cli -i wlan0 scan
sleep 2
wpa_cli -i wlan0 scan_results

wpa_cli -i wlan0 add_network
wpa_cli -i wlan0 set_network 0 ssid "EMPA_Arge"
wpa_cli -i wlan0 set_network 0 psk "Emp@Arg2024!"
wpa_cli -i wlan0 enable_network 0
wpa_cli -i wlan0 select_network 0
udhcpc -i wlan0
ifconfig wlan0
ping www.google.com

## 2.2 SIM Testi

qlril-api-test
20 → operatör bilgisi
21 → SIM kart status
24 → PIN unlock
30 → ICCID oku

## 2.3 Network Testi

qlril-api-test
70 → Data registration state kontrol edilir.

## 2.4 GNSS Testi

qlril-api-test
90 → GNSS client aç
92 → GNSS başlat
95 → Lokasyon al

3. Referans Dokümanlar

Quectel SC206E Linux User Guide
Quectel SC206E QLRIL API Reference Manual

SC206E Hardware Design Document
Schematic Design od CamTracker

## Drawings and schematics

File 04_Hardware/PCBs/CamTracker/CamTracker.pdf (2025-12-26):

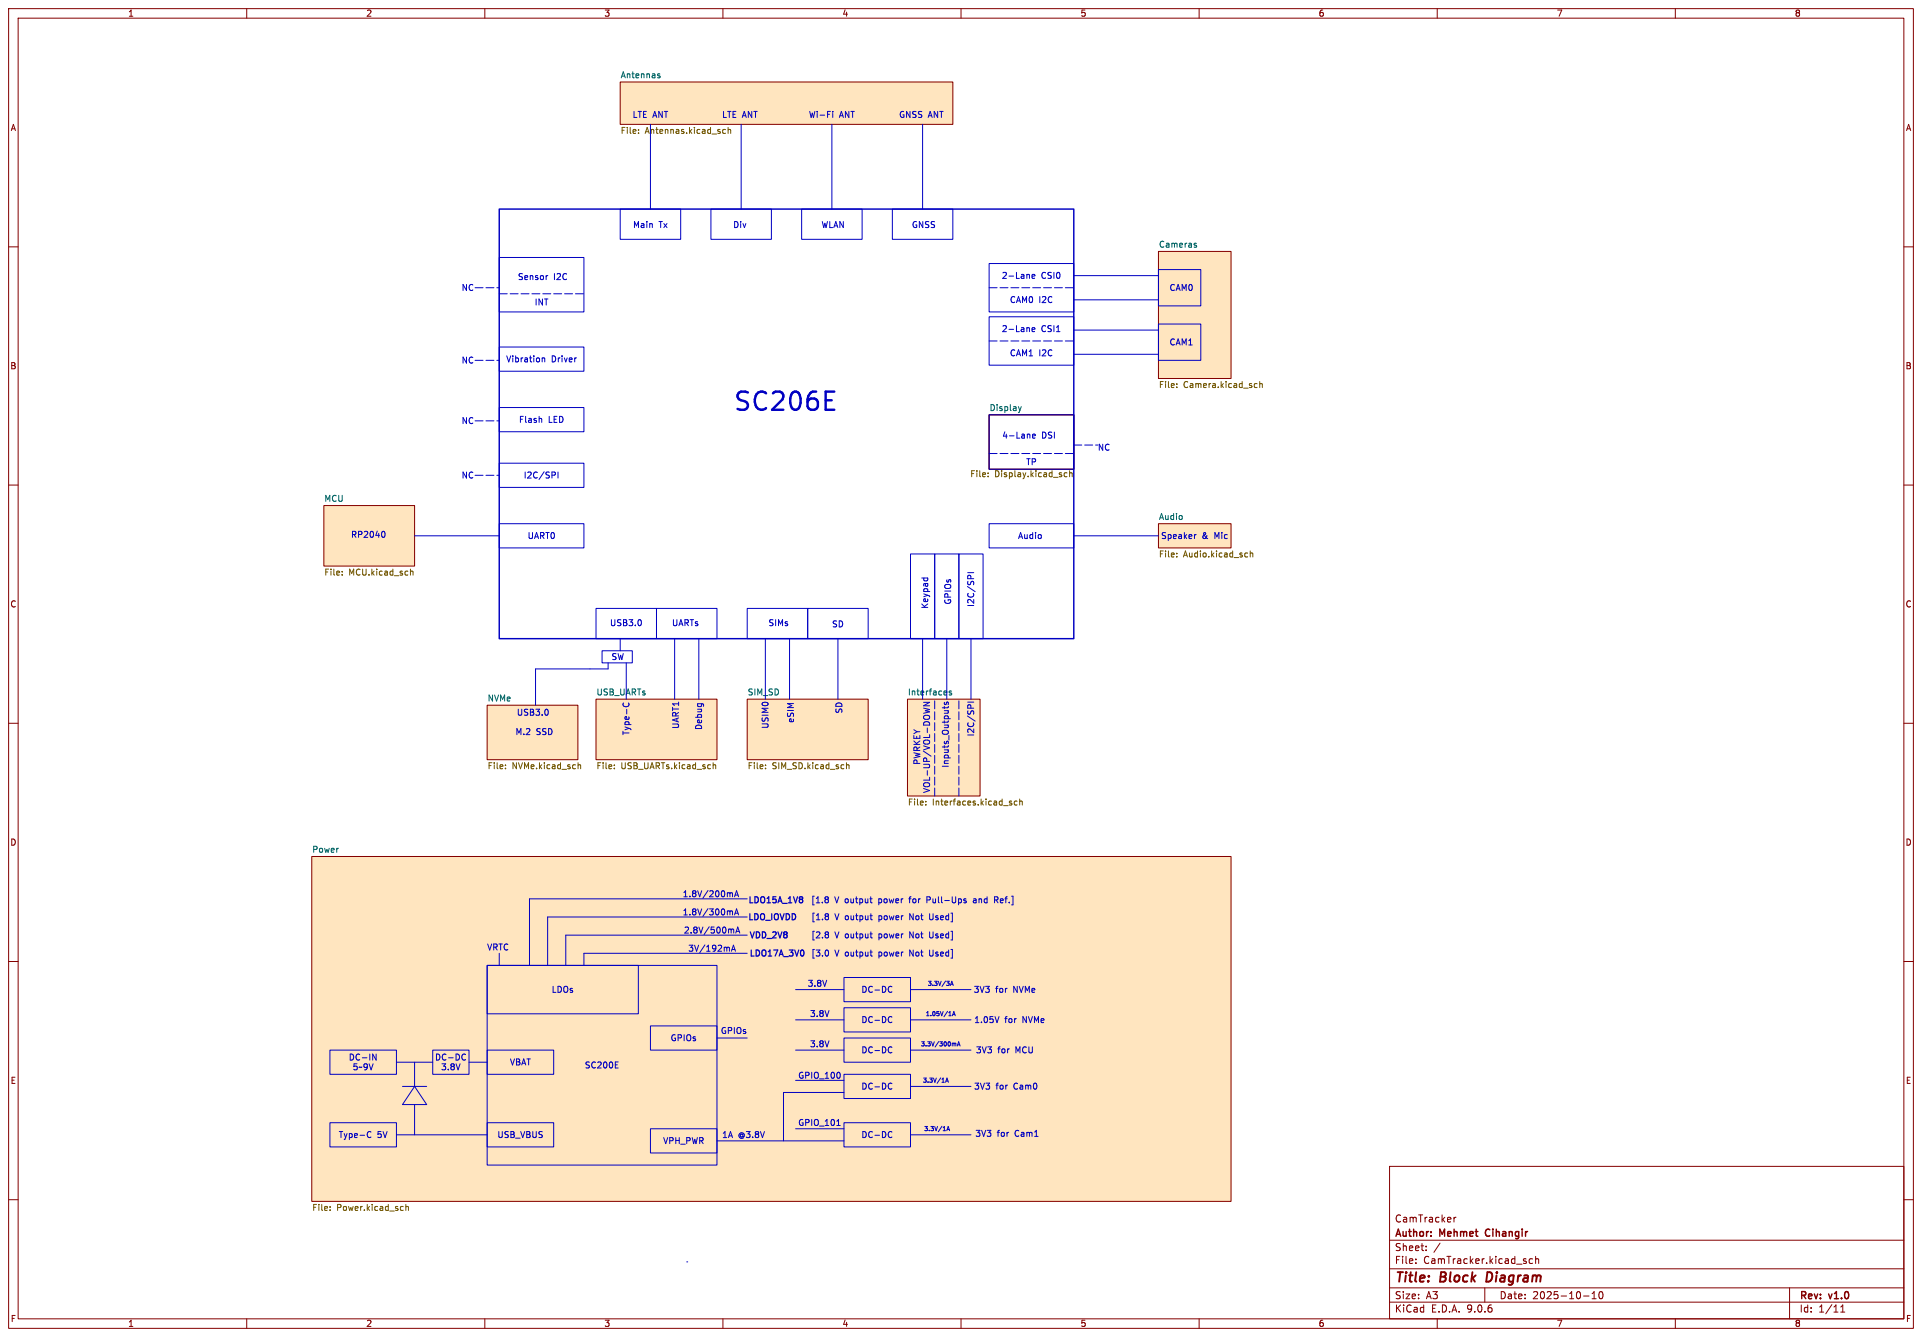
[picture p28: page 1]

Interfaces File: Interfaces.kicad_sch MCU

3V3 for Cam0 PWRKEY VOL-UP/VOL-DOWNSD

[2.8 V output power Not Used] USB3.0

[1.8 V output power Not Used]

[3.0 V output power Not Used] 3.8V

Id: 1/11 Title: Block Diagram

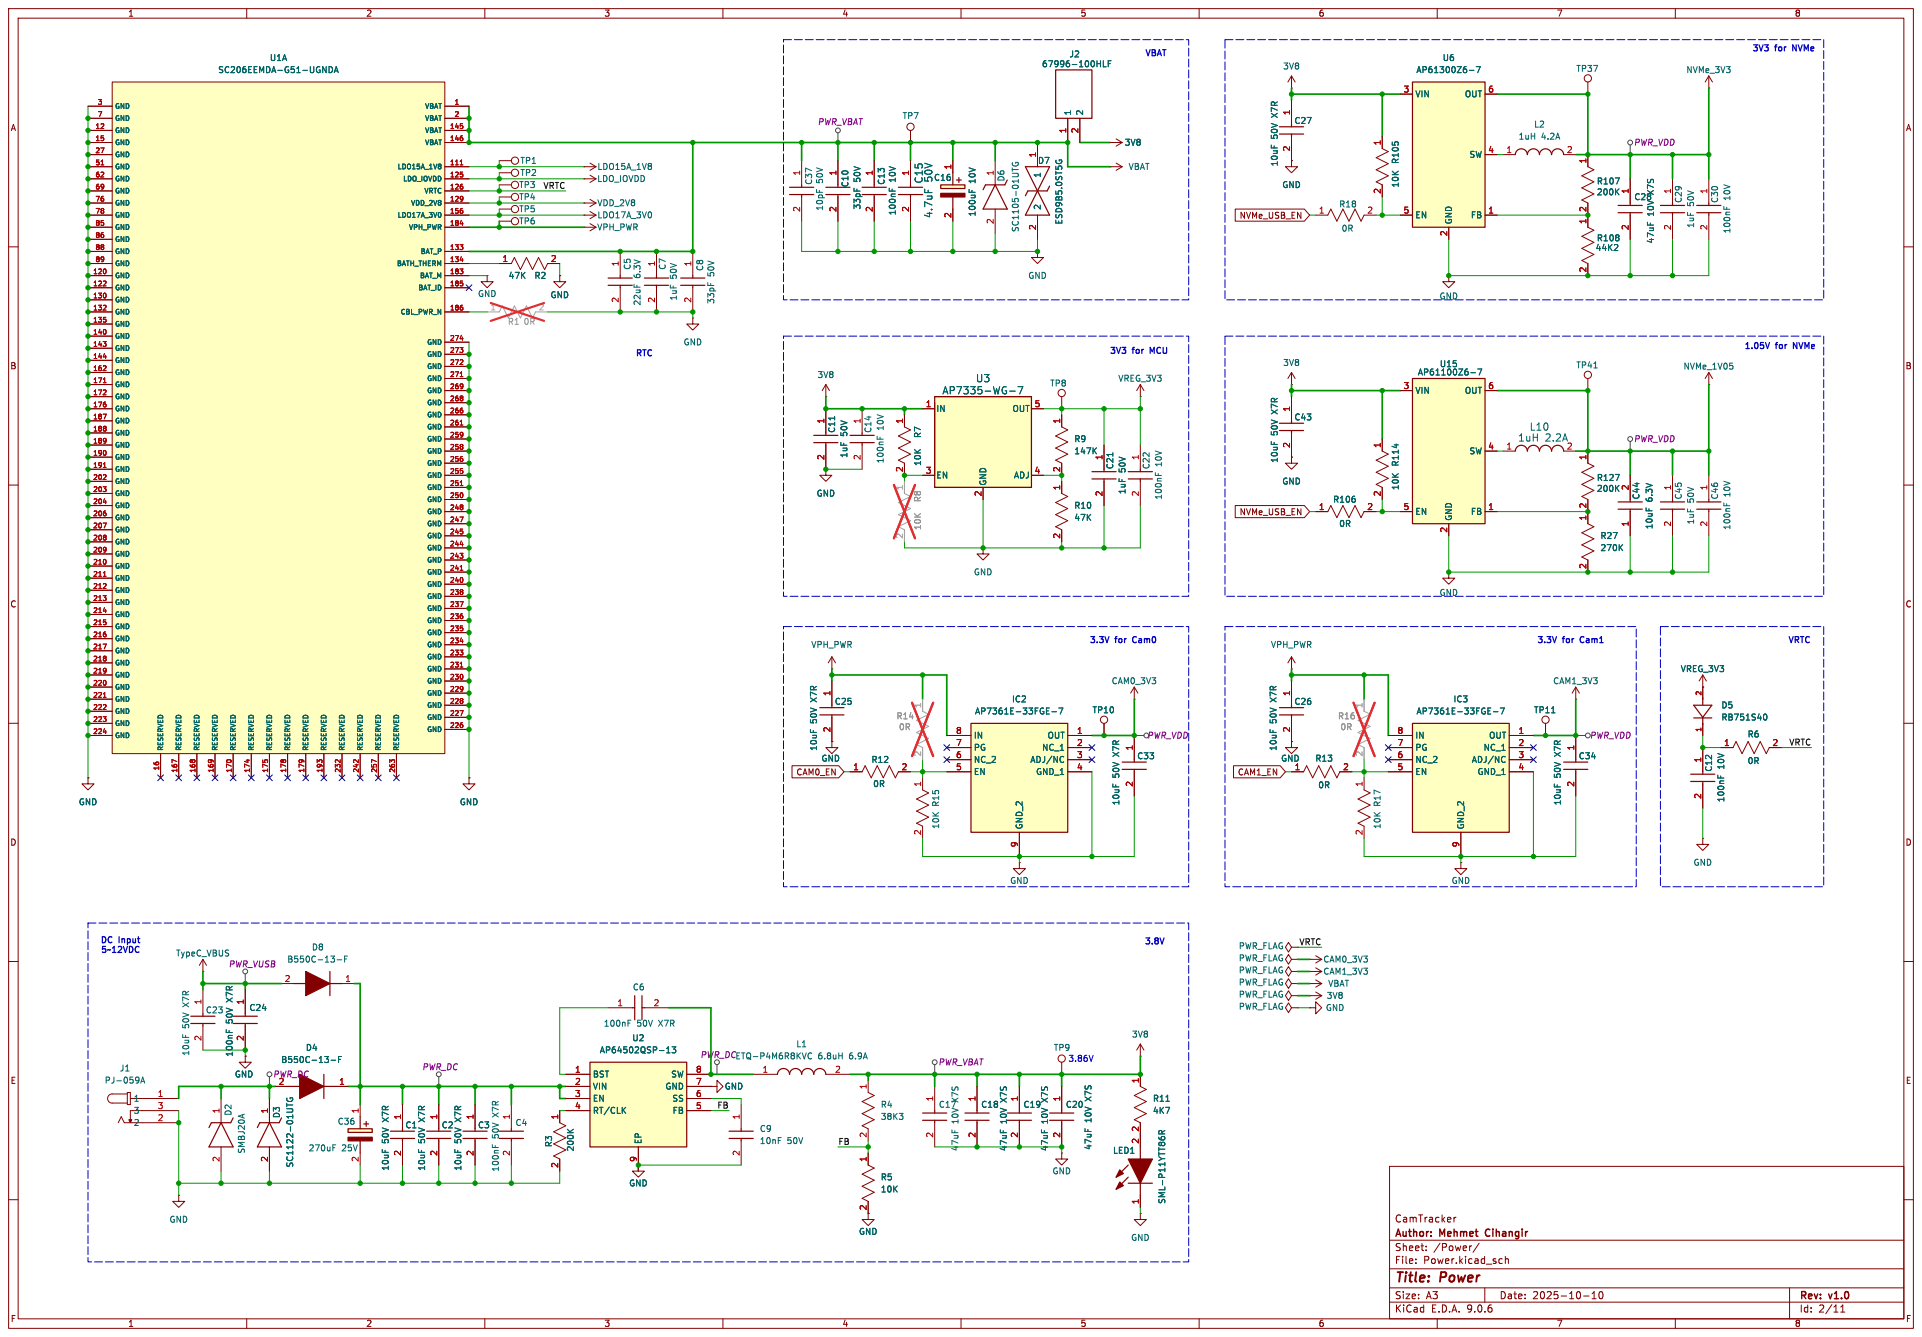
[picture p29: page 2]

2 OUT 6 SW 4 FB 1 U6 AP61300Z6-7 3V8 GND

2 OUT 6 SW 4 FB 1 GND

9 SW 8 GND 7 SS 6 FB 5 U2 AP64502QSP-13

9 SW 8 GND 7 SS 6 FB 5 R5

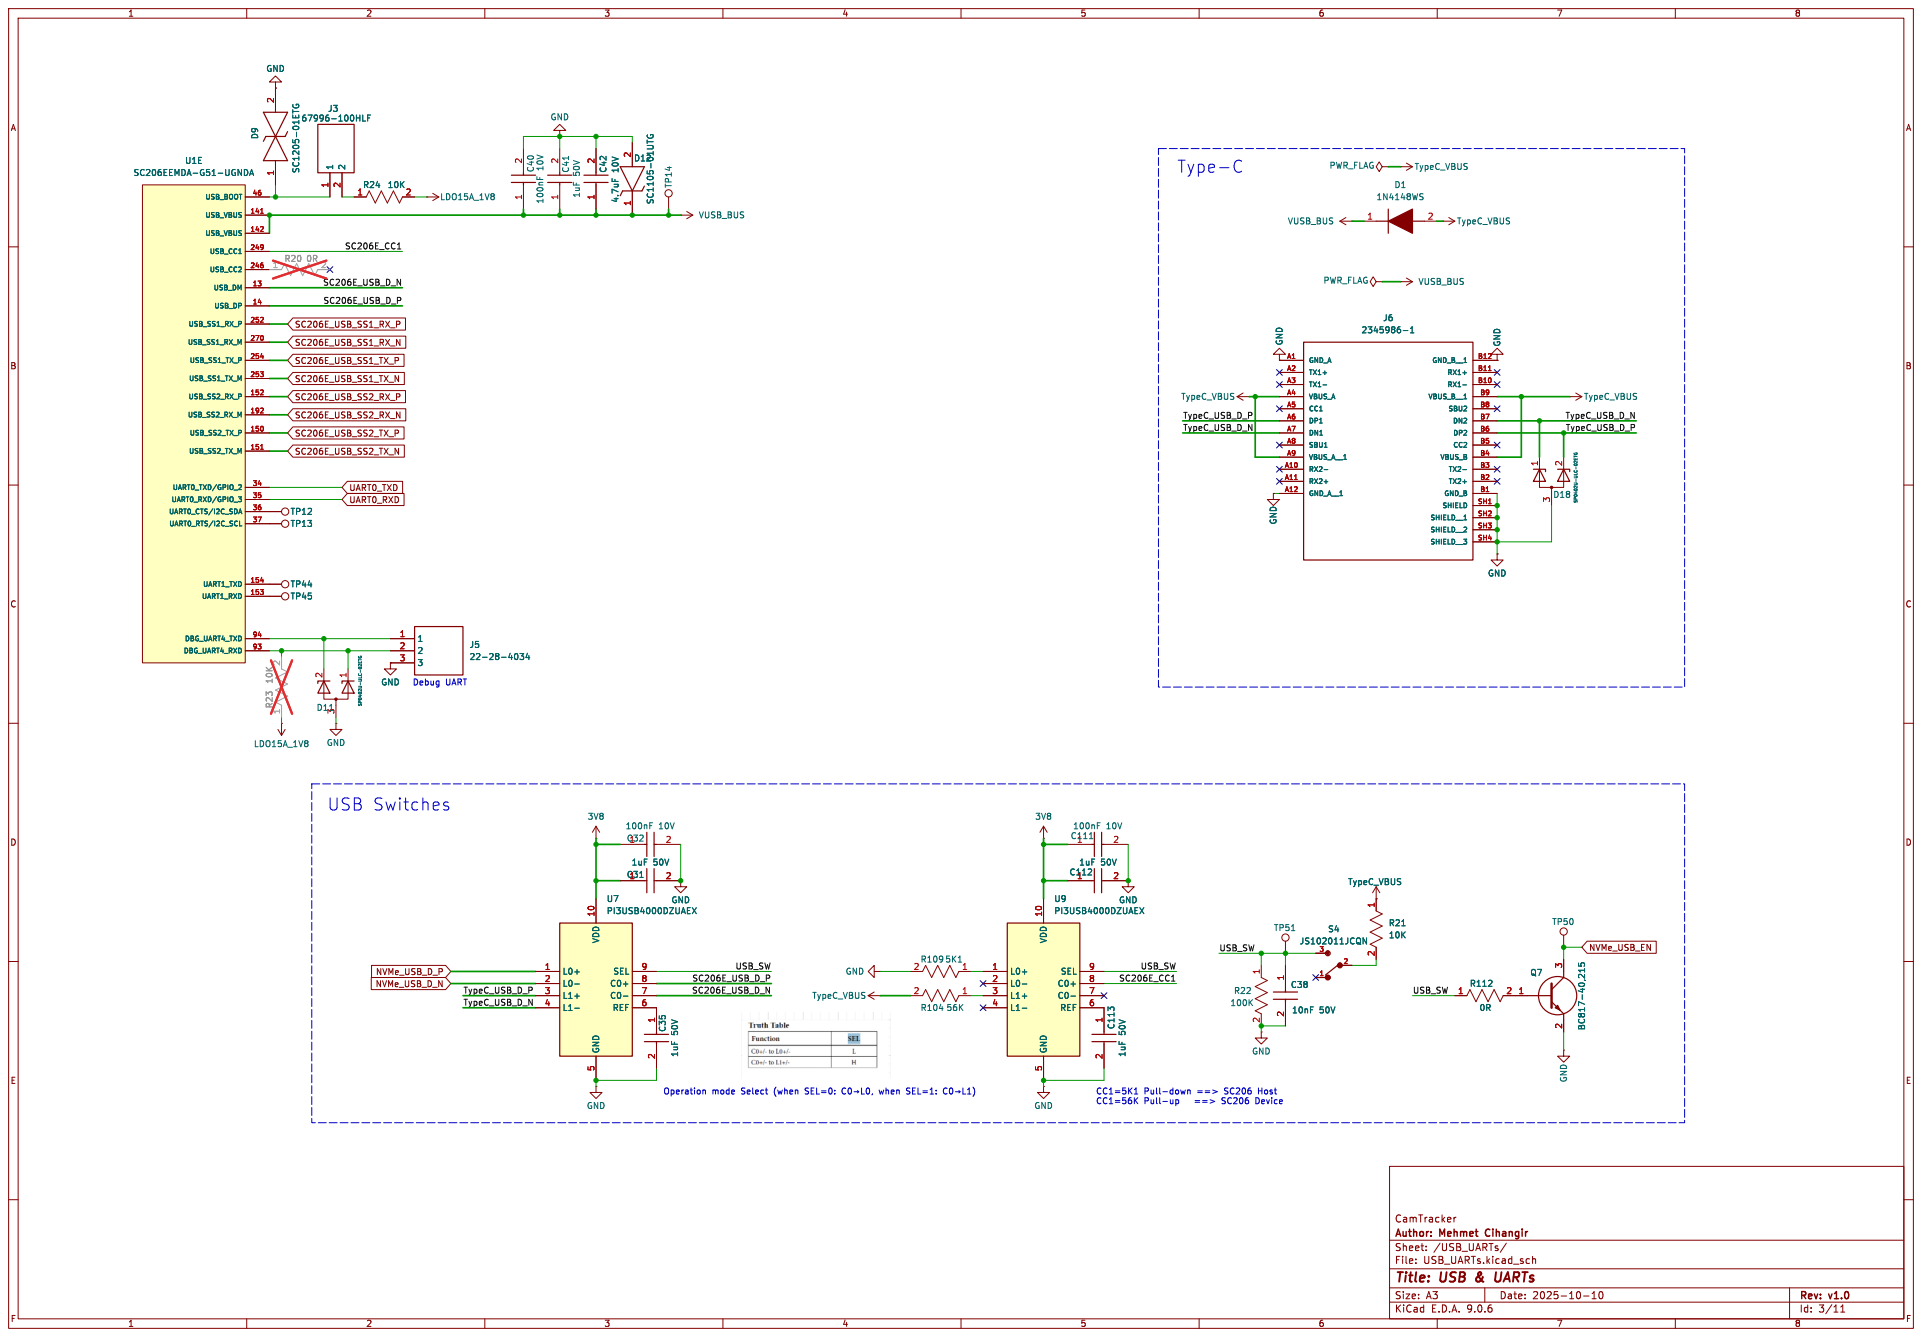
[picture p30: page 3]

Debug UART USB Switches

Id: 3/11 Title: USB & UARTs

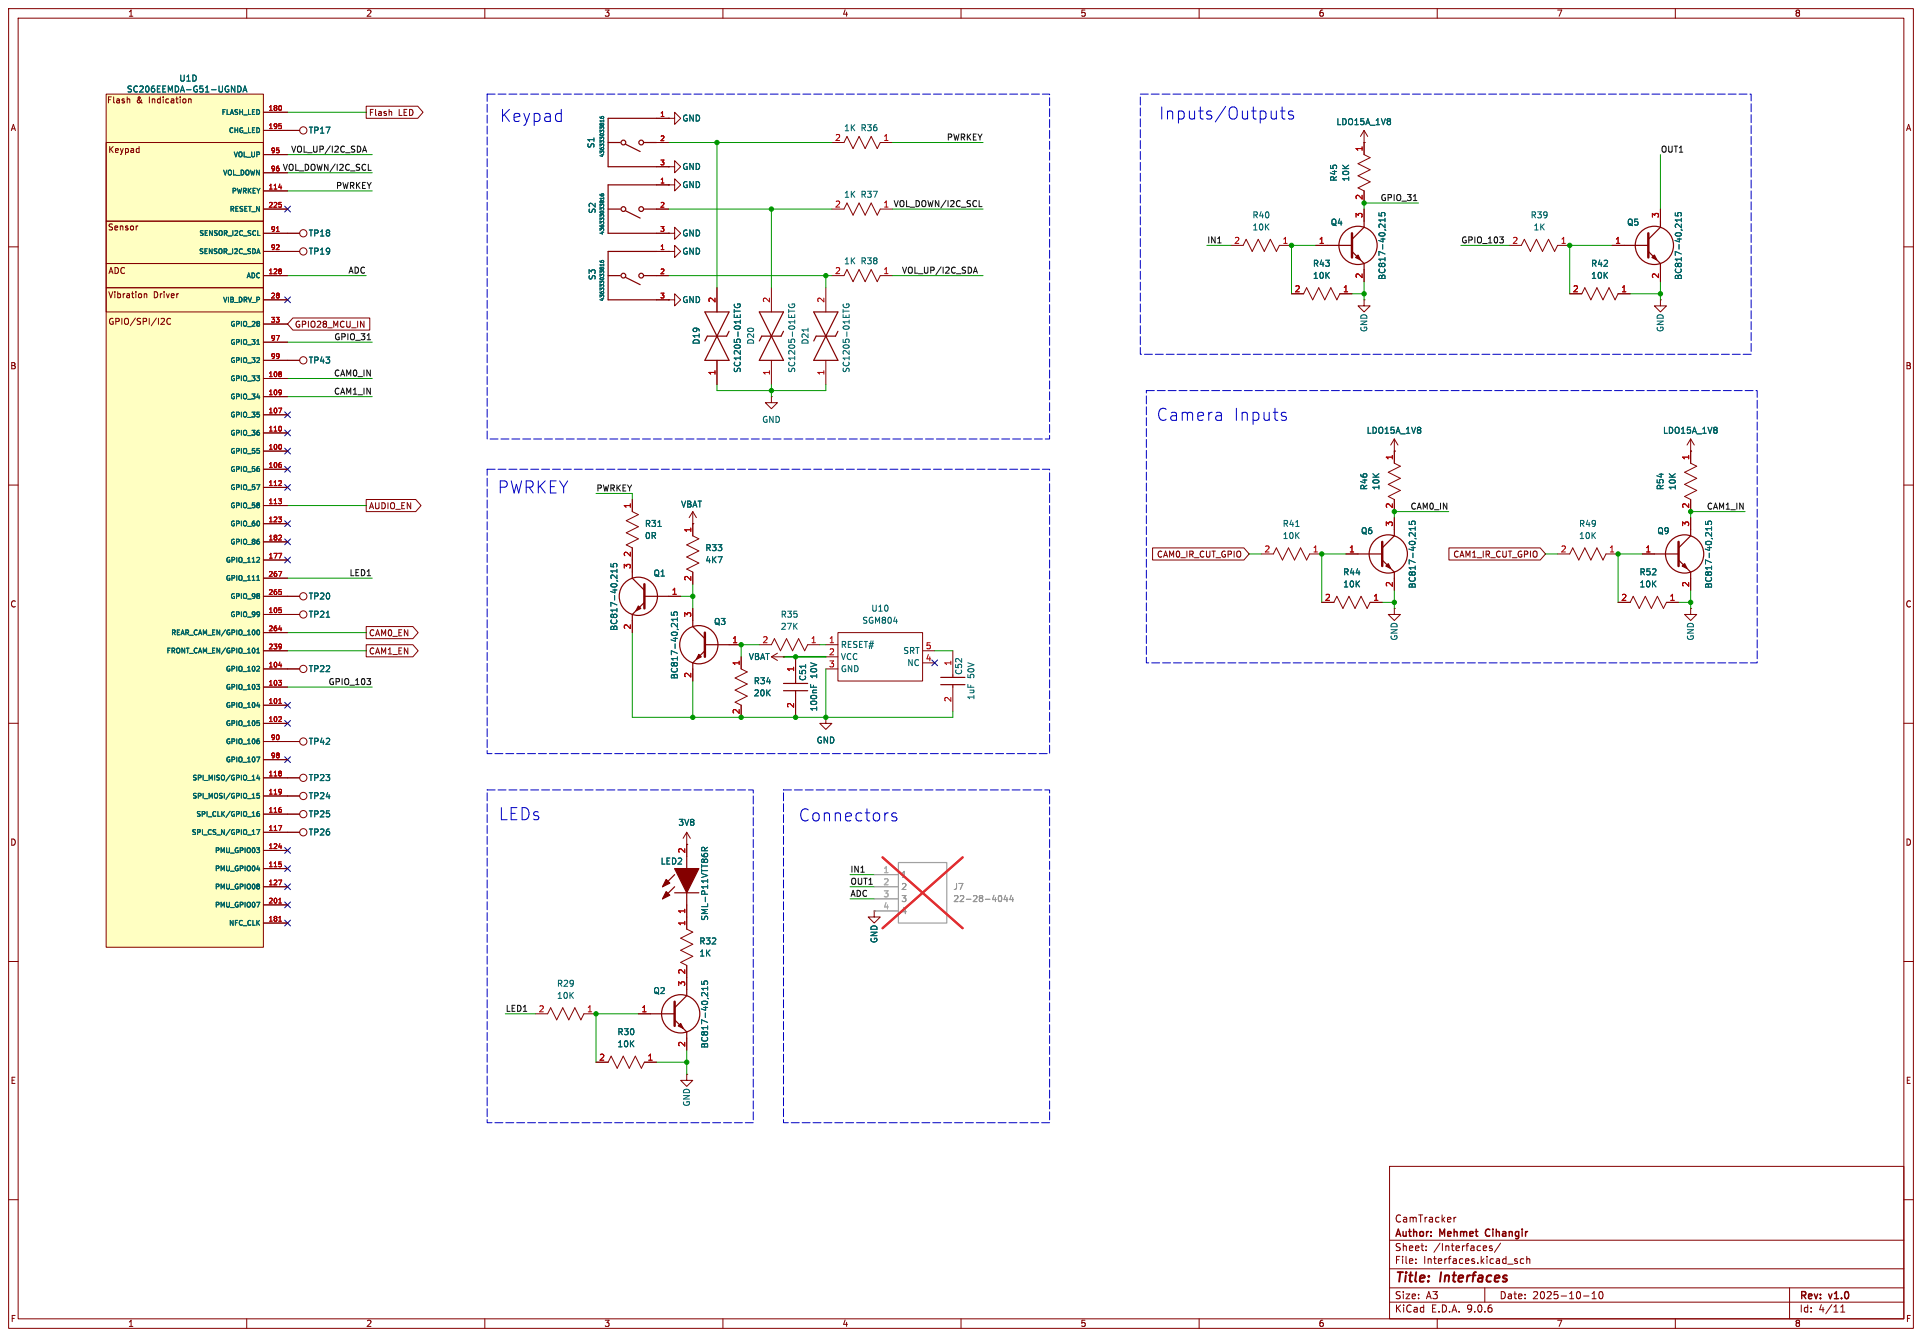
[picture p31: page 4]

Sensor Keypad GPIO/SPI/I2C
GND

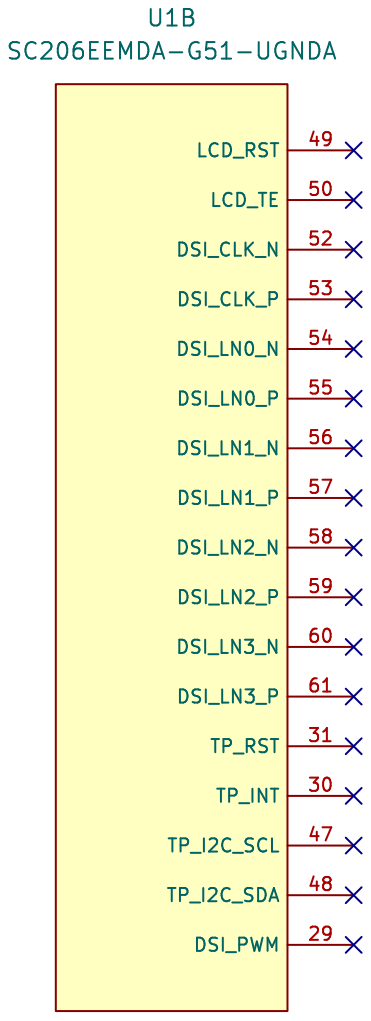
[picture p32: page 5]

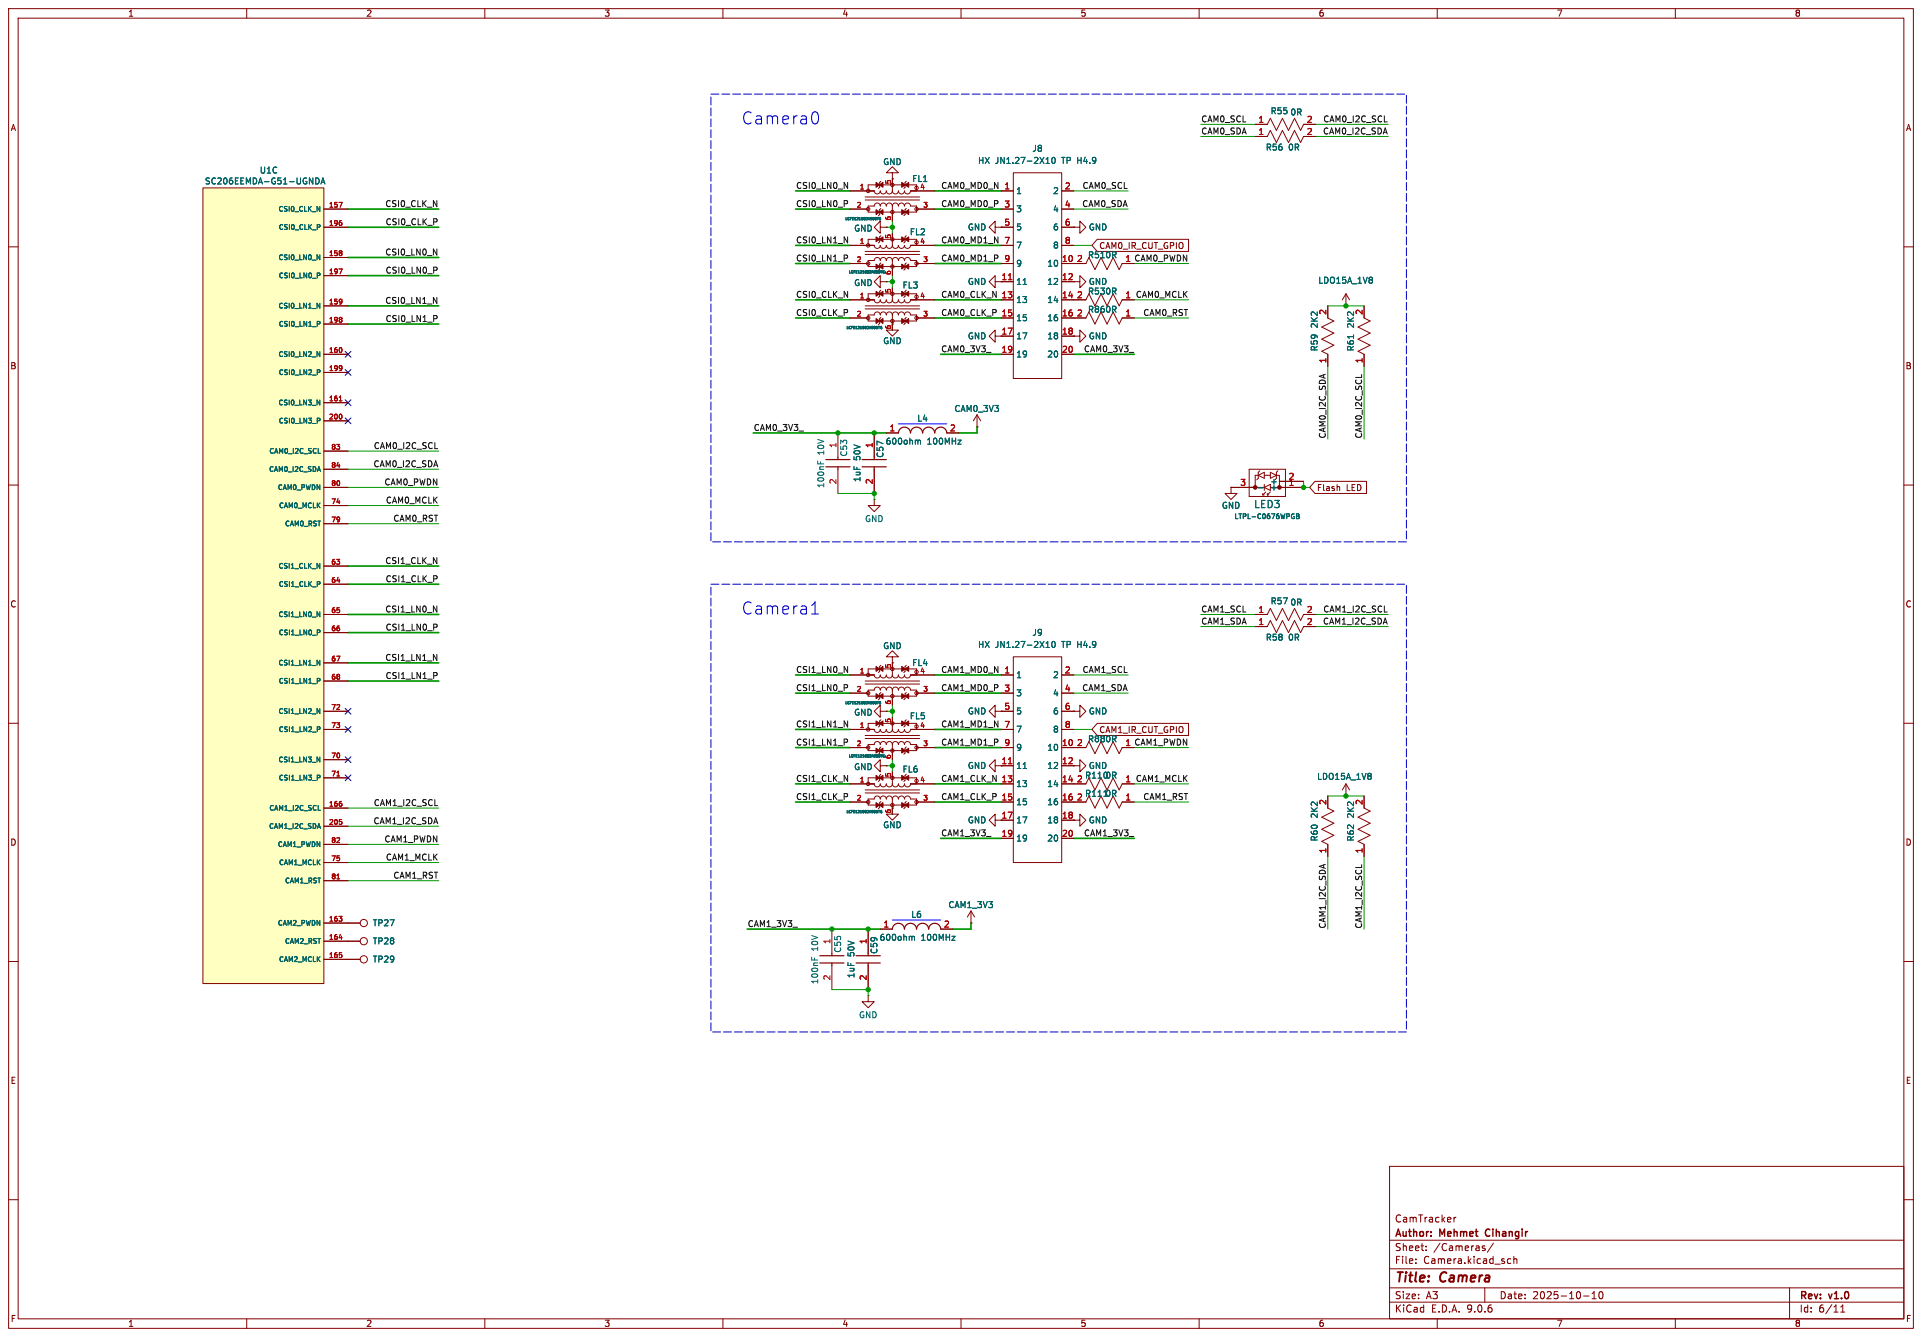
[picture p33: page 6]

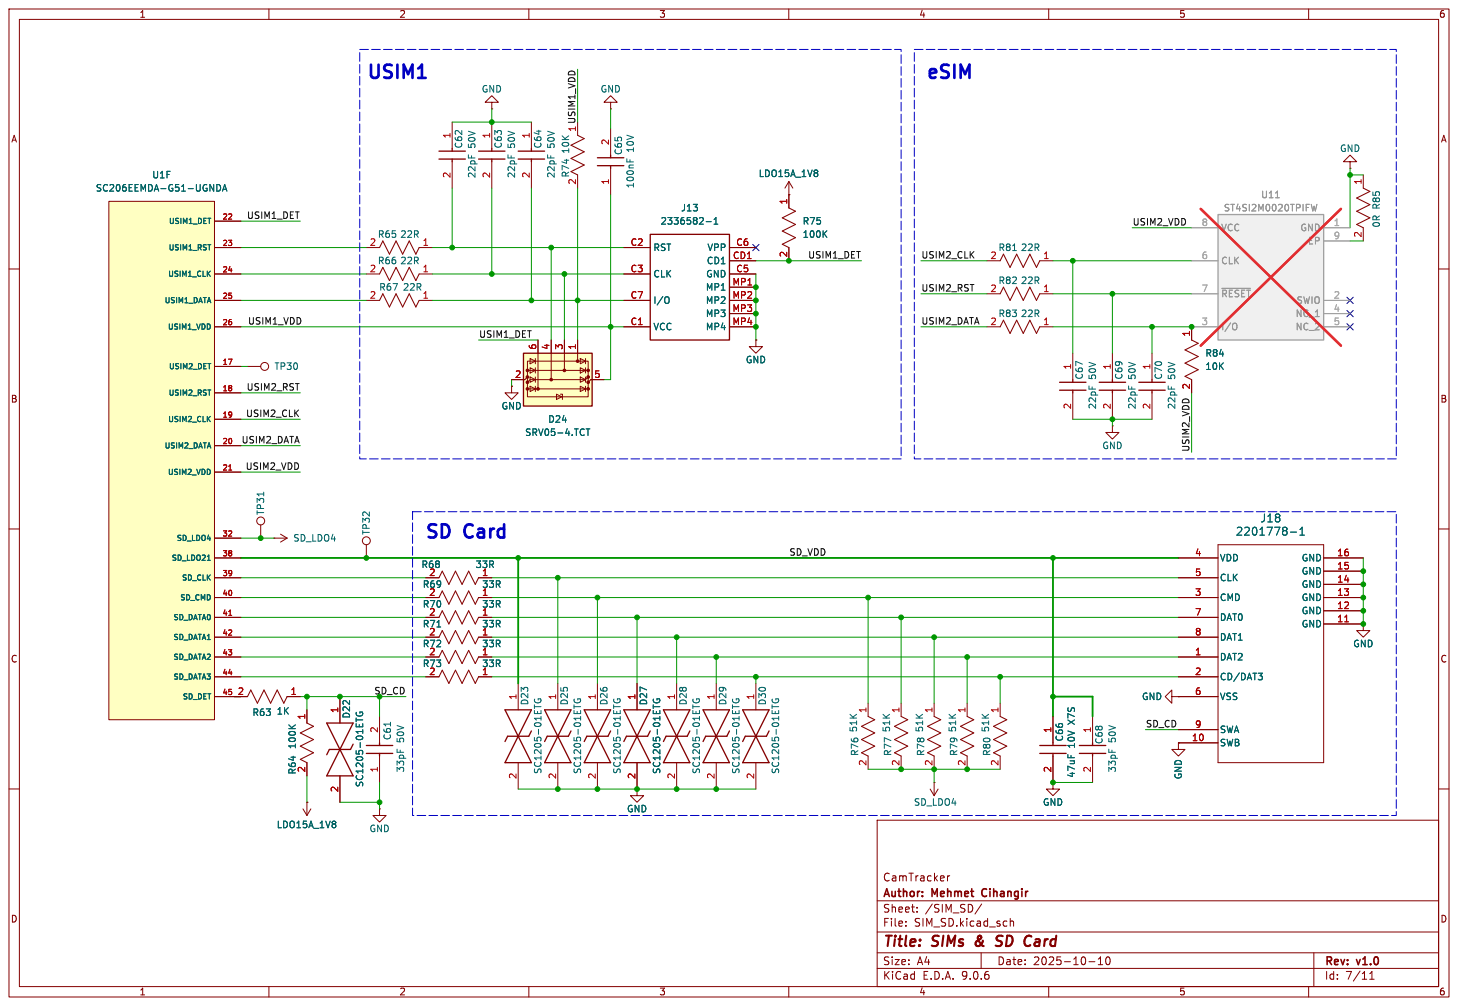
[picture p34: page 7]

1 2 C68 33pF 50V GND GND GND GND

Id: 7/11 Title: SIMs & SD Card

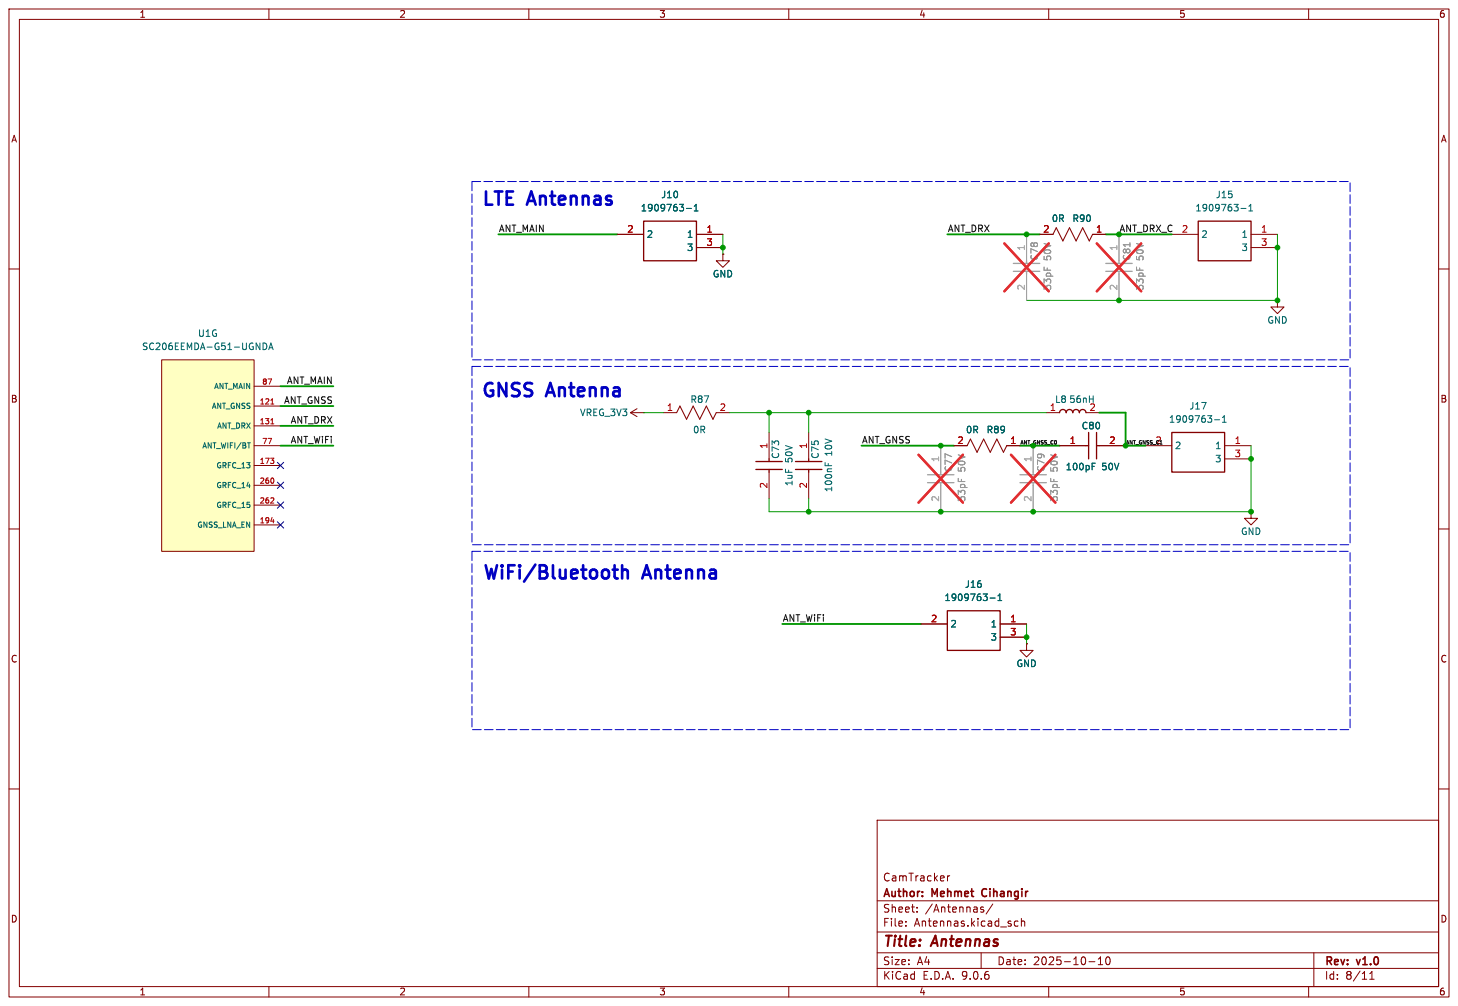
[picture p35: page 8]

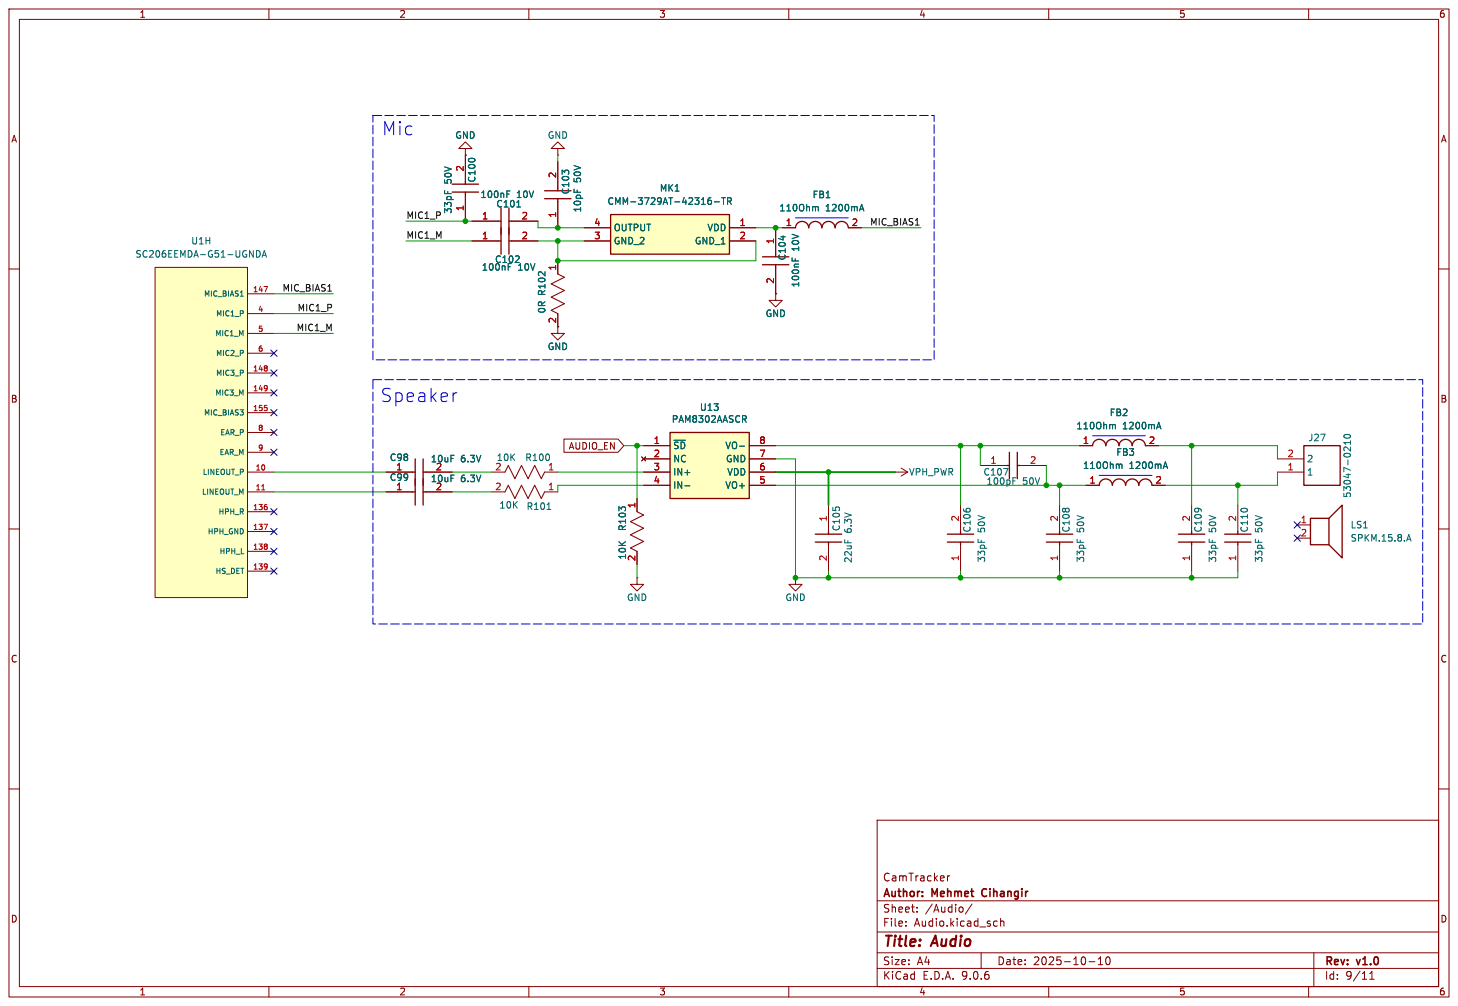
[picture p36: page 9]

1 2 C103 10pF 50V GND GND OUTPUT 4 GND_2 3 VDD 1 GND_1 2 MK1 CMM-3729AT-42316-TR GND

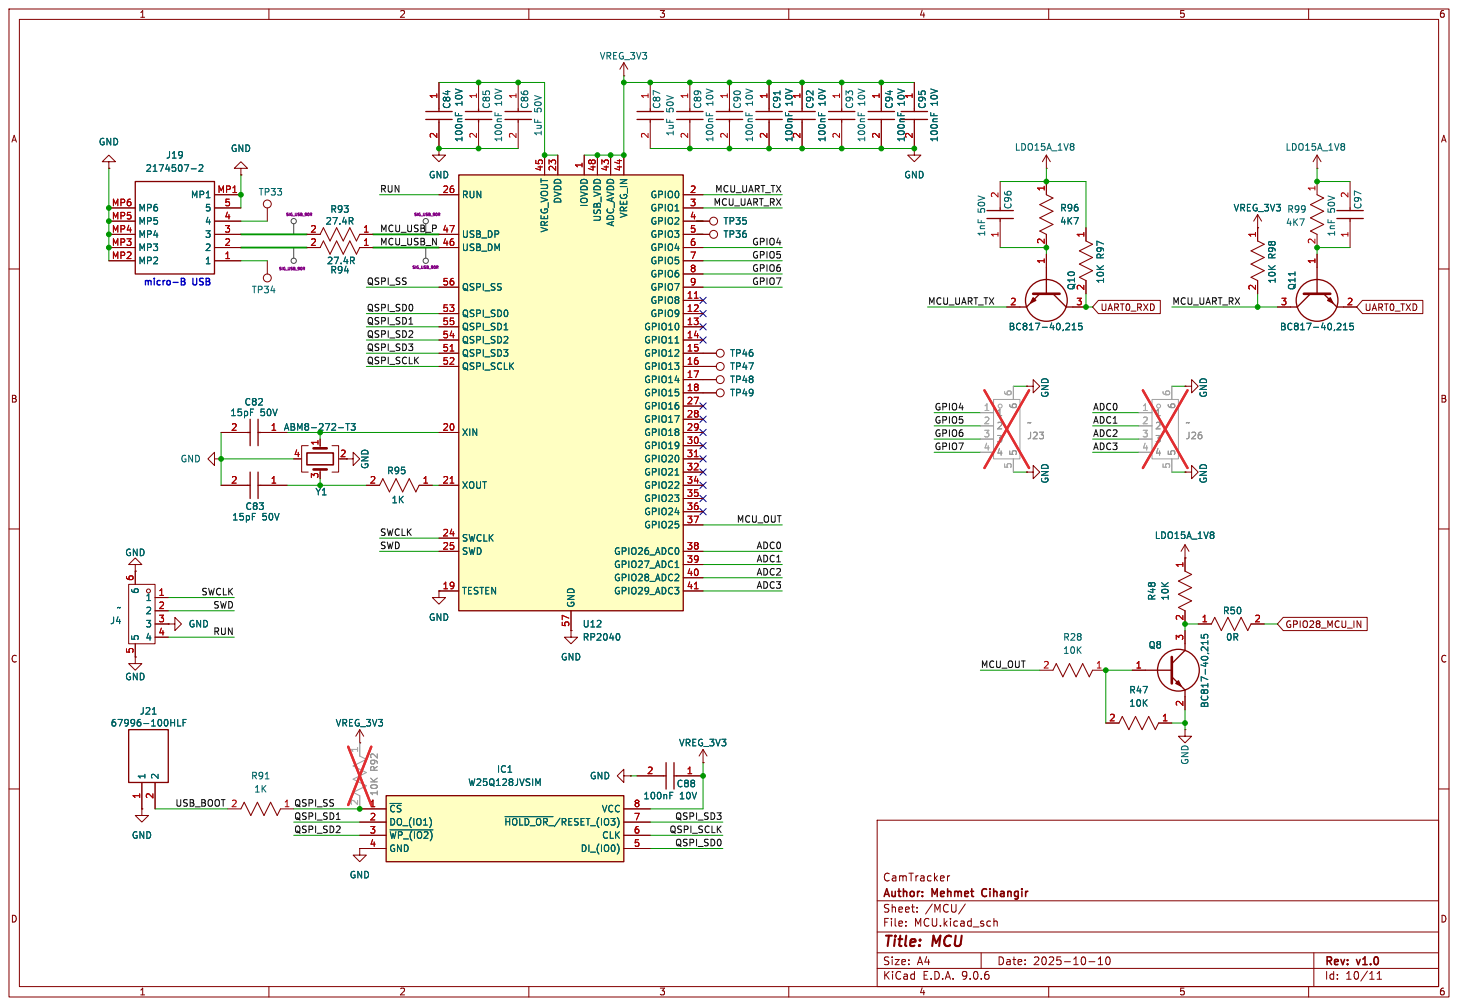
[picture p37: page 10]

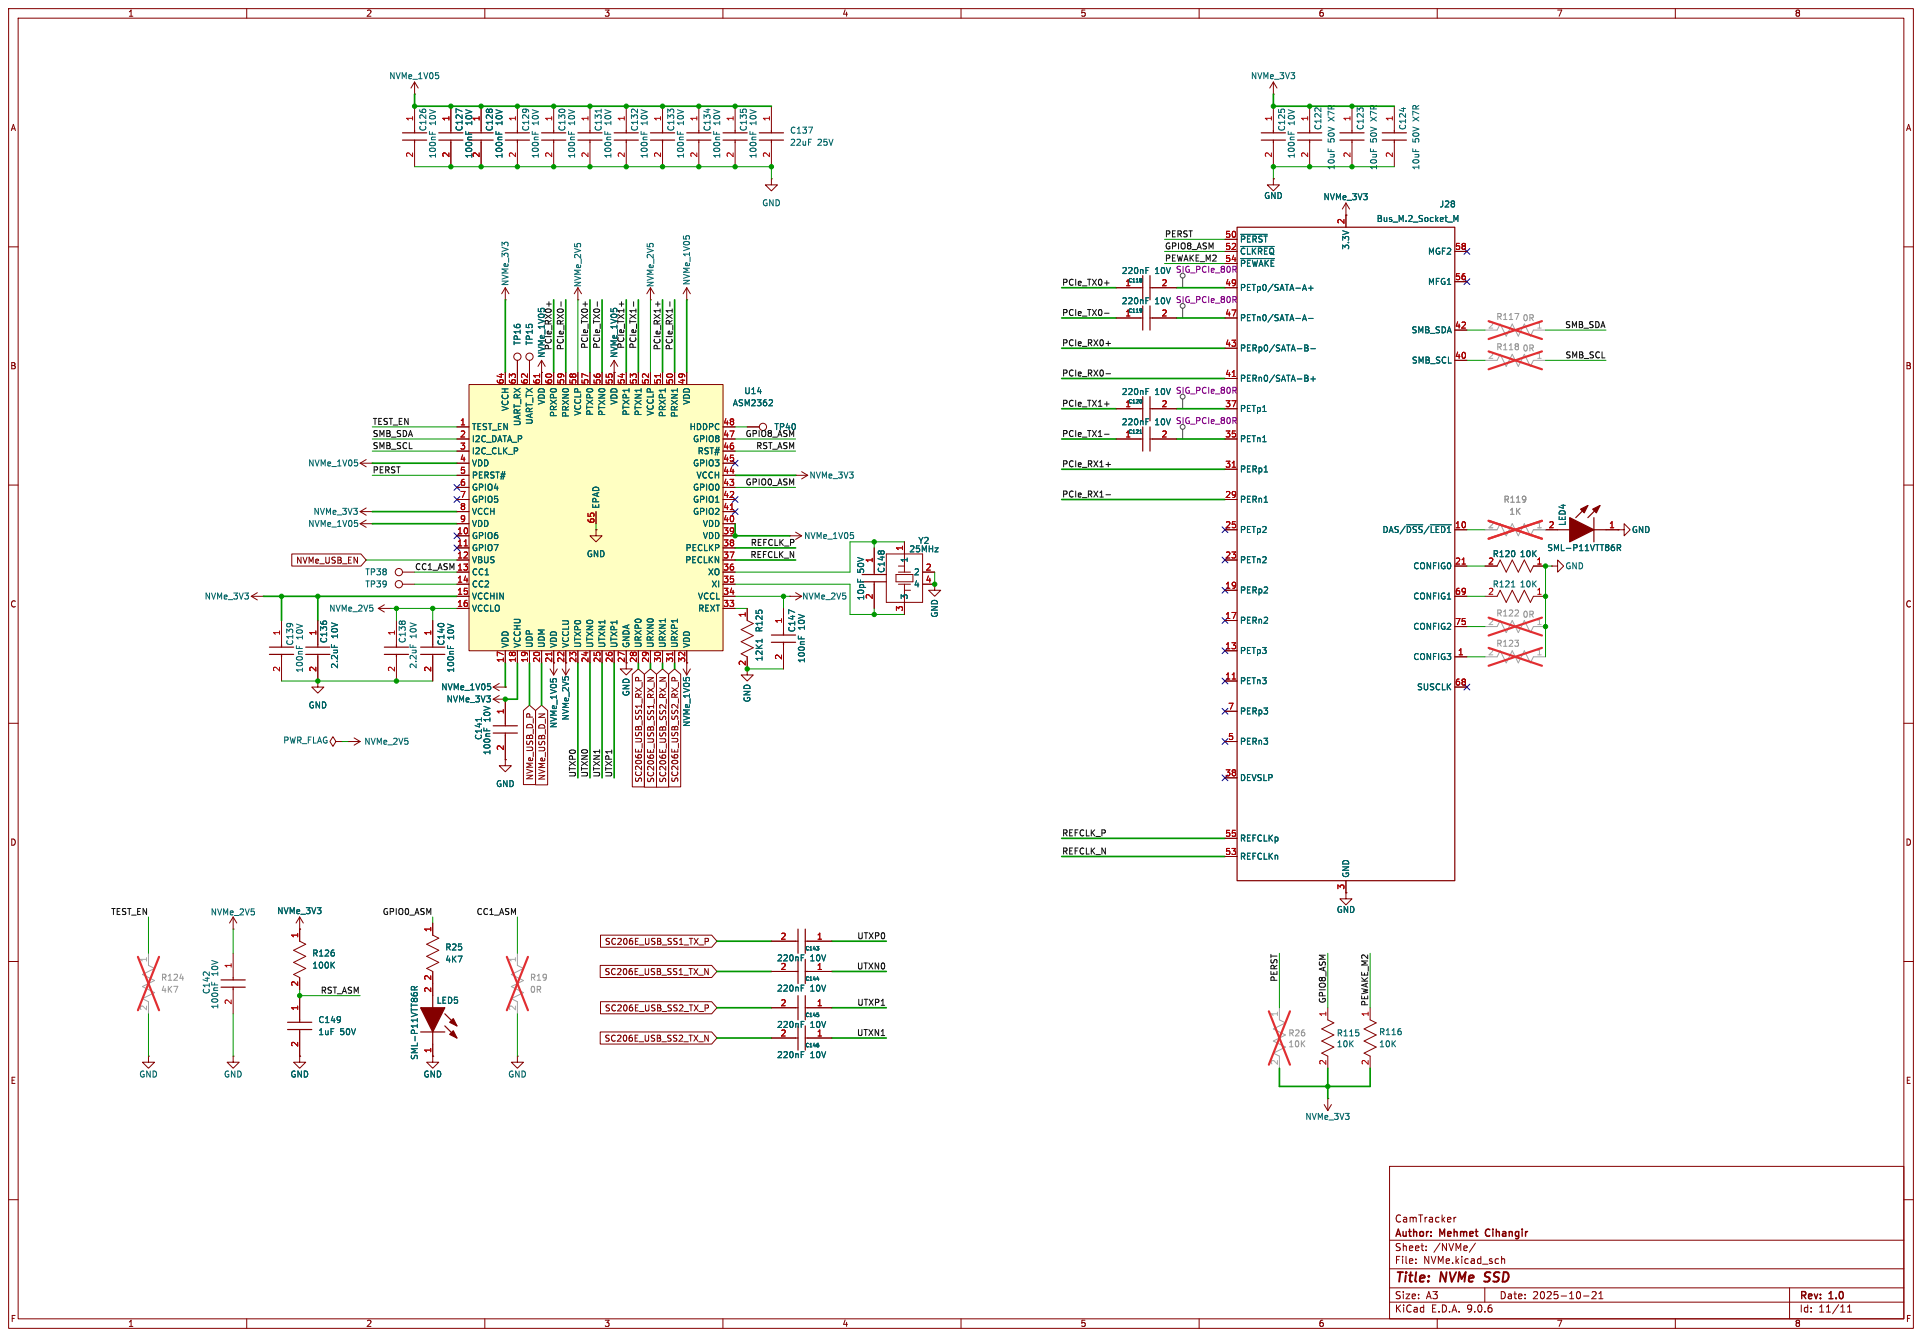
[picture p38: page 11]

3 MGF2 58 MFG1 56 SMB_SDA 42 SMB_SCL 40 DAS/~{DSS}/~{LED1} 10 CONFIG0 21 CONFIG1 69 CONFIG2 75 CONFIG3 1 SUSCLK 68 C148 10pF 50V1 2 GND

Id: 11/11 Title: NVMe SSD

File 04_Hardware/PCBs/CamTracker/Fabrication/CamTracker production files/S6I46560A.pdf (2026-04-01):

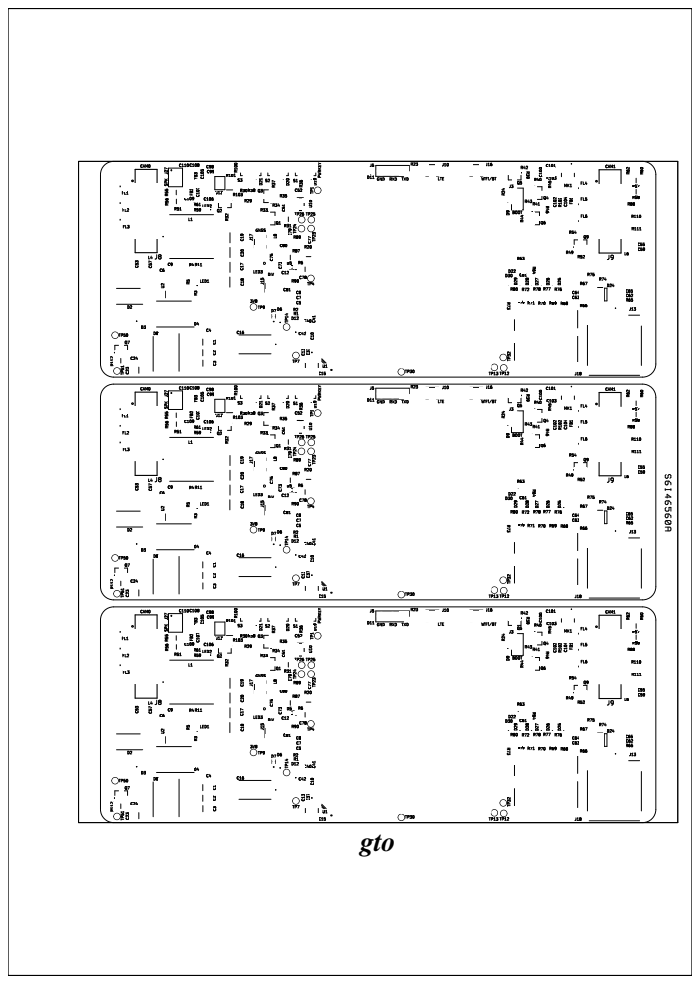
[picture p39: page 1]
gto

gts

gtl





gbl

gbs

gbo

drl

gko

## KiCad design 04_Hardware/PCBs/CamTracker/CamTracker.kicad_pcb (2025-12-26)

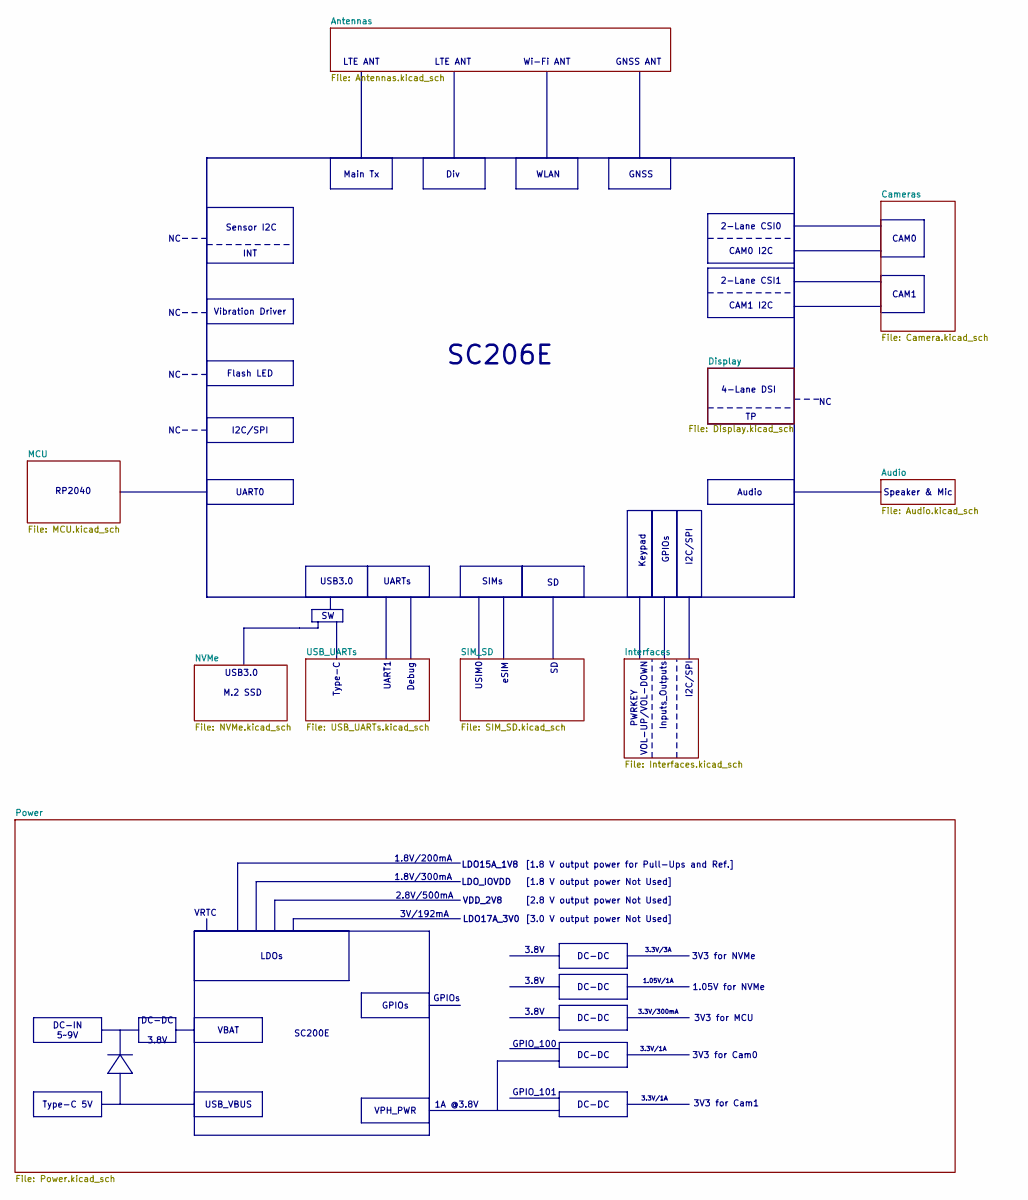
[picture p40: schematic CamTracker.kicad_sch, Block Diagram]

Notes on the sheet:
PWRKEY VOL-UP/VOL-DOWN
3V3 for MCU
LDO17A_3V0
UARTs
1.05V for NVMe
Debug
GPIOs
I2C/SPI
Inputs_Outputs
USIM0
3.8V
CAM1
[1.8 V output power Not Used]
[3.0 V output power Not Used]
RP2040
1.8V/300mA
1.05V/1A
4-Lane DSI
VRTC
3.3V/1A
3V3 for NVMe
3.8V
USB3.0
SC206E
1A @3.8V
Type-C
CAM0
eSIM
2.8V/500mA
Vibration Driver
3.3V/300mA
2-Lane CSI1
Main Tx
Speaker & Mic
3V3 for Cam0
M.2 SSD
GNSS
VDD_2V8
2-Lane CSI0
CAM1 I2C

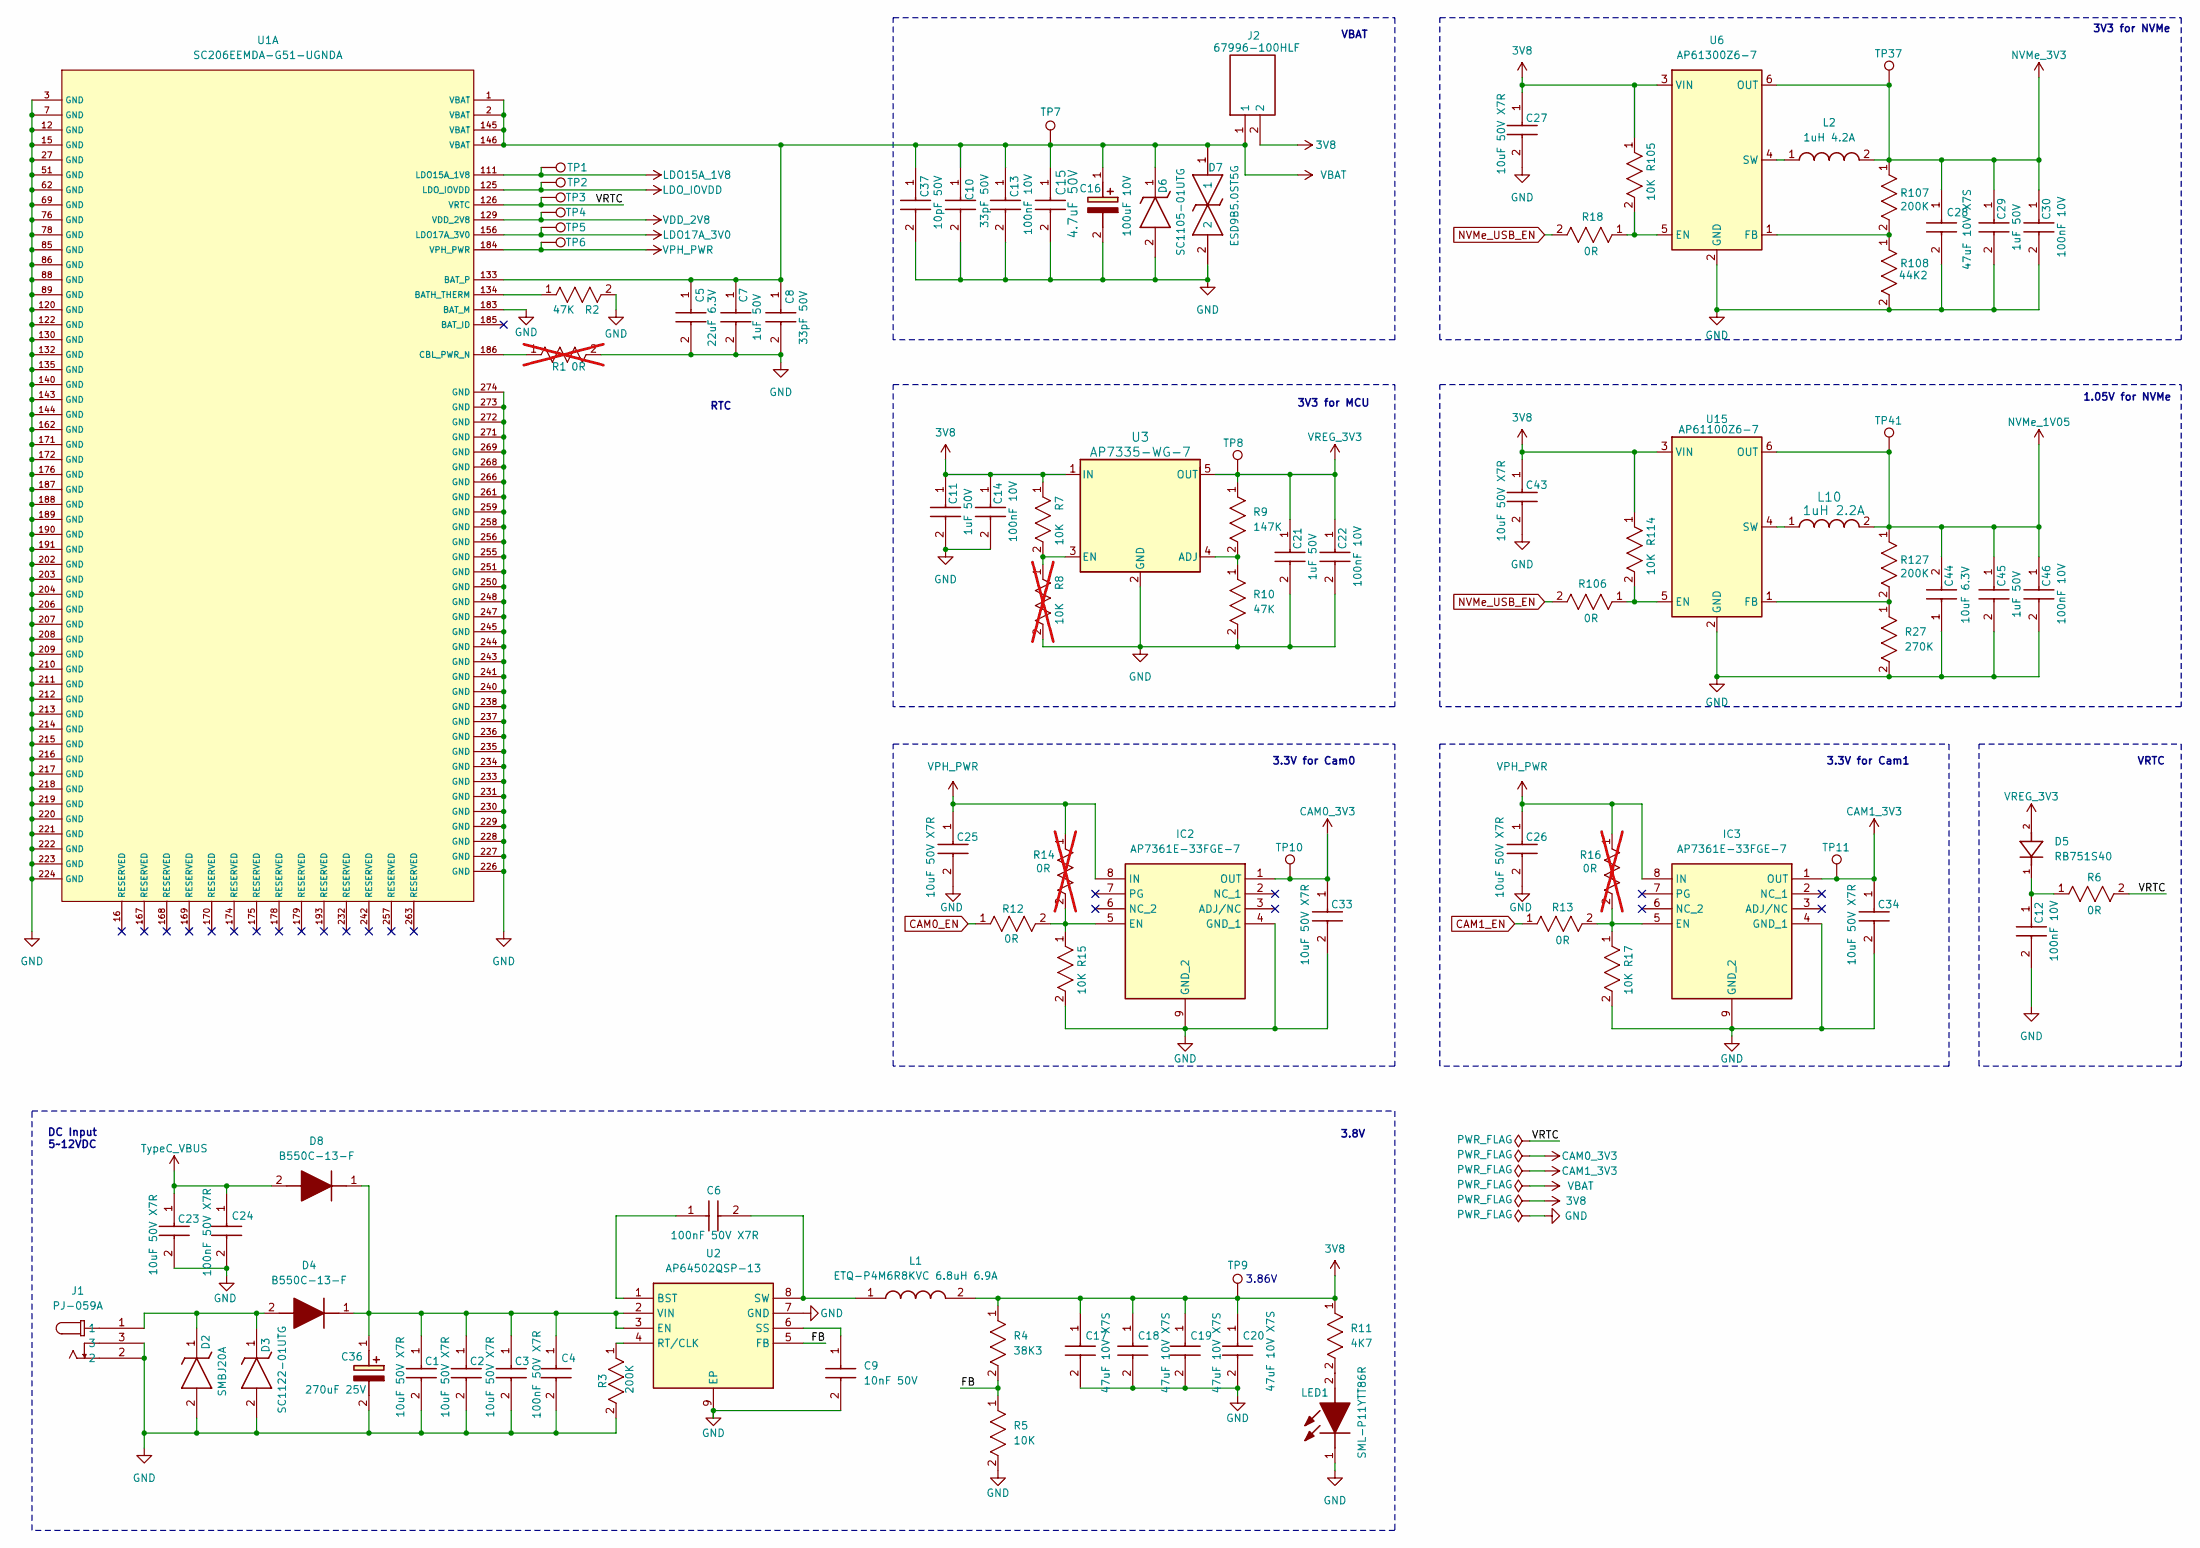
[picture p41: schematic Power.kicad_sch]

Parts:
C1, C2, C3, C23, C25, C26, C27, C33, C34, C43: 10uF 50V X7R; CAPC3216X190N; Part Number CL31B106KBK6PJE
C4, C6, C24: 100nF 50V X7R; CAPC1005X55N; Part Number UMK105B7104KVHF
C5: 22uF 6.3V; CAPC1005X55N; Part Number GRM158R60J226ME01D
C7, C11, C21, C29, C45: 1uF 50V; CAPC1005X55N; Part Number GRM155R61H105KE05D
C8, C10: 33pF 50V; CAPC1005X55N; Part Number GRM1555C1H330JA01D
C9: 10nF 50V; CAPC1005X55N; Part Number GRM155R71H103KA88D
C12, C13, C14, C22, C30, C46: 100nF 10V; CAPC1005X55N; Part Number GRM155R71A104KA01D
C15: 4.7uF 50V; CAP_UMK325B7475MM-T_TAY; Part Number UMK325BJ475MM-T
C16: 100uF 10V; T495D; Part Number T495D107K010ATE080
C17, C18, C19, C20, C28: 47uF 10V X7S; CAPC3225X280N; Part Number CGA6P1X7S1A476M250AC
C36: 270uF 25V; 16SVPT560M; Part Number 25SVPG270M
C37: 10pF 50V; CAPC1005X55N; Part Number GRM1555C1H100JA01D
C44: 10uF 6.3V; CAPC1005X55N; Part Number GRM155R60J106ME15D
D2: SMBJ20A; DIOM5436X244N; Part Number SMBJ20A
D3: SC1122-01UTG; SC110501UTG; Part Number SC1122-01UTG
D4, D8: B550C-13-F; DIOM7959X250N; Part Number B550C-13-F
D5: RB751S40; SOD1608X70; Part Number RB751S40
D6: SC1105-01UTG; SC110501UTG; Part Number SC1105-01UTG
D7: ESD9B5.0ST5G; SODFL1006X40N; Part Number ESD9B5.0ST5G
IC2, IC3: AP7361E-33FGE-7; SON65P300X300X63-9N; Part Number AP7361E-33FGE-7
J1: PJ-059A; PJ059A; Part Number PJ-059A
J2: 67996-100HLF; HDRV2W67P254_2X1_254X483X858P; Part Number 67996-100HLF
L1: ETQ-P4M6R8KVC 6.8uH 6.9A; ETQ-P4M_KVC; Part Number ETQ-P4M6R8KVC
L2: 1uH 4.2A; LSEUC3225HKT1R0M; Part Number LSEUC3225HKT1R0M
L10: 1uH 2.2A; IND_WE-LQS_2512_WRE; Part Number 74404024010
LED1: SML-P11YTT86R; SMLP11VTT86R; Part Number SML-P11YTT86R
R1: 0R; RC0402N_YAG; Part Number RC0402JR-070RL; not fitted
R2, R10: 47K; RC0402N_YAG; Part Number RC0402JR-0747KL
R3, R107, R127: 200K; RC0402N_YAG; Part Number RC0402FR-07200KL
R4: 38K3; RC0402N_YAG; Part Number AF0402FR-0738K3L
R5, R7, R15, R17, R105, R114: 10K; RC0402N_YAG; Part Number RC0402JR-0710KL
R6, R12, R13: 0R; RESC2012X50N; Part Number CRCW08050000Z0EA
R8: 10K; RC0402N_YAG; Part Number RC0402JR-0710KL; not fitted
R9: 147K; RC0402N_YAG; Part Number RC0402FR-07147KL
R11: 4K7; RC0402N_YAG; Part Number RC0402JR-074K7L
R14, R16: 0R; RESC2012X50N; Part Number CRCW08050000Z0EA; not fitted
R18, R106: 0R; RC0402N_YAG; Part Number RC0402JR-070RL
R27: 270K; RC0402N_YAG; Part Number RC0402FR-07270KL
R108: 44K2; RC0402N_YAG; Part Number RC0402FR-0744K2L
TP1, TP2, TP3, TP4, TP5, TP6, TP7, TP8, TP10, TP11, TP37, TP41: TestPoint; TestPoint_Pad_D1.0mm
TP9: 3.86V; TestPoint_Pad_D1.0mm
U1: SC206EEMDA-G51-UGNDA; SC200E_SC206E; Part Number SC200EEMNA-E53-UGNDA
U2: AP64502QSP-13; SOIC127P600X163-9N; Part Number AP64502QSP-13
U3: AP7335-WG-7; SOT95P285X145-5N; Part Number AP7335-WG-7
U6: AP61300Z6-7; SOT50P162X60-6N; Part Number AP61100Z6-7
U15: AP61100Z6-7; SOT50P162X60-6N; Part Number AP61100Z6-7

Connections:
3V8: C11.1, C14.1, C17.1, C18.1, C19.1, C20.1, C27.1, C43.1, J2.2, L1.2, R4.1, R7.1, R11.1, R105.1, R114.1, TP9.1, U3.1 (IN), U6.3 (VIN), U15.3 (VIN); also elsewhere on the board
/Power/FB: R4.2, R5.1, U2.5 (FB)
/Power/VRTC: R6.2, TP3.1, U1.126 (VRTC)
CAM0_3V3: C33.1, IC2.1 (OUT), TP10.1; also elsewhere on the board
CAM0_EN: R12.1; also elsewhere on the board
CAM1_3V3: C34.1, IC3.1 (OUT), TP11.1; also elsewhere on the board
CAM1_EN: R13.1; also elsewhere on the board
GND: C1.2, C2.2, C3.2, C4.2, C5.2, C7.2, C8.2, C9.2, C10.2, C11.2, C12.2, C13.2, C14.2, C15.2, C16.2 (-), C17.2, C18.2, C19.2, C20.2, C21.2, C22.2, C23.2, C24.2, C25.2, C26.2, C27.2, C28.2, C29.2, C30.2, C33.2, C34.2, C36.2 (-), C37.2, C43.2, C44.1, C45.2, C46.2, D2.2 (A), D3.2 (A), D6.2 (A), D7.2, IC2.4 (GND_1), IC2.9 (GND_2), IC3.4 (GND_1), IC3.9 (GND_2), J1.2, J1.3, LED1.1 (K), R1.2, R2.2, R3.2, R5.2, R8.2, R10.2, R15.2, R17.2, R27.2, R108.2, U1.3 (GND), U1.7 (GND), U1.12 (GND), U1.15 (GND), U1.27 (GND), U1.51 (GND), U1.62 (GND), U1.69 (GND), U1.76 (GND), U1.78 (GND), U1.85 (GND), U1.86 (GND), U1.88 (GND), U1.89 (GND), U1.120 (GND), U1.122 (GND), U1.130 (GND), U1.132 (GND), U1.135 (GND), U1.140 (GND), U1.143 (GND), U1.144 (GND), U1.162 (GND), U1.171 (GND), U1.172 (GND), U1.176 (GND), U1.183 (BAT_M), U1.187 (GND), U1.188 (GND), U1.189 (GND), U1.190 (GND), U1.191 (GND), U1.202 (GND), U1.203 (GND), U1.204 (GND), U1.206 (GND), U1.207 (GND), U1.208 (GND), U1.209 (GND), U1.210 (GND), U1.211 (GND), U1.212 (GND), U1.213 (GND), U1.214 (GND), U1.215 (GND), U1.216 (GND), U1.217 (GND), U1.218 (GND), U1.219 (GND), U1.220 (GND), U1.221 (GND), U1.222 (GND), U1.223 (GND), U1.224 (GND), U1.226 (GND), U1.227 (GND), U1.228 (GND), U1.229 (GND), U1.230 (GND), U1.231 (GND), U1.233 (GND), U1.234 (GND), U1.235 (GND), U1.236 (GND), U1.237 (GND), U1.238 (GND), U1.240 (GND), U1.241 (GND), U1.243 (GND), U1.244 (GND), U1.245 (GND), U1.247 (GND), U1.248 (GND), U1.250 (GND), U1.251 (GND), U1.255 (GND), U1.256 (GND), U1.258 (GND), U1.259 (GND), U1.261 (GND), U1.266 (GND), U1.268 (GND), U1.269 (GND), U1.271 (GND), U1.272 (GND), U1.273 (GND), U1.274 (GND), U2.7 (GND), U2.9 (EP), U3.2 (GND), U6.2 (GND), U15.2 (GND); also elsewhere on the board
LDO15A_1V8: TP1.1, U1.111 (LDO15A_1V8); also elsewhere on the board
LDO17A_3V0: TP5.1, U1.156 (LDO17A_3V0)
LDO_IOVDD: TP2.1, U1.125 (LDO_IOVDD)
NVMe_1V05: C44.2, C45.1, C46.1, L10.2, R127.1, TP41.1, U15.6 (OUT); also elsewhere on the board
NVMe_3V3: C28.1, C29.1, C30.1, L2.2, R107.1, TP37.1, U6.6 (OUT); also elsewhere on the board
NVMe_USB_EN: R18.2, R106.2; also elsewhere on the board
unnamed: C12.1, D5.1, R6.1
unnamed: C1.1, C2.1, C3.1, C4.1, C36.1 (+), D4.1 (K), D8.1 (K), U2.2 (VIN), U2.3 (EN)
unnamed: D2.1 (K), D3.1 (K), D4.2 (A), J1.1
unnamed: IC2.5 (EN), R12.2, R14.2, R15.1
unnamed: IC3.5 (EN), R13.2, R16.2, R17.1
unnamed: LED1.2 (A), R11.2
unnamed: R2.1, U1.134 (BATH_THERM)
unnamed: R1.1, U1.186 (CBL_PWR_N)
unnamed: C6.1, U2.1 (BST)
unnamed: R3.1, U2.4 (RT/CLK)
unnamed: C9.1, U2.6 (SS)
unnamed: C6.2, L1.1, U2.8 (SW)
unnamed: R9.2, R10.1, U3.4 (ADJ)
unnamed: R7.2, R8.1, U3.3 (EN)
unnamed: R18.1, R105.2, U6.5 (EN)
unnamed: R107.2, R108.1, U6.1 (FB)
unnamed: L2.1, U6.4 (SW)
unnamed: R106.1, R114.2, U15.5 (EN)
unnamed: R27.1, R127.2, U15.1 (FB)
unnamed: L10.1, U15.4 (SW)
TypeC_VBUS: C23.1, C24.1, D8.2 (A); also elsewhere on the board
VBAT: C5.1, C7.1, C8.1, C10.1, C13.1, C15.1, C16.1 (+), C37.1, D6.1 (K), D7.1, J2.1, TP7.1, U1.1 (VBAT), U1.2 (VBAT), U1.133 (BAT_P), U1.145 (VBAT), U1.146 (VBAT); also elsewhere on the board
VDD_2V8: TP4.1, U1.129 (VDD_2V8)
VPH_PWR: C25.1, C26.1, IC2.8 (IN), IC3.8 (IN), R14.1, R16.1, TP6.1, U1.184 (VPH_PWR); also elsewhere on the board
VREG_3V3: C21.1, C22.1, D5.2, R9.1, TP8.1, U3.5 (OUT); also elsewhere on the board

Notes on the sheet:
3.3V for Cam0
VBAT
1.05V for NVMe
3V3 for NVMe
3V3 for MCU
RTC
3.8V
DC Input 5~12VDC
3.3V for Cam1
3.86V
VRTC

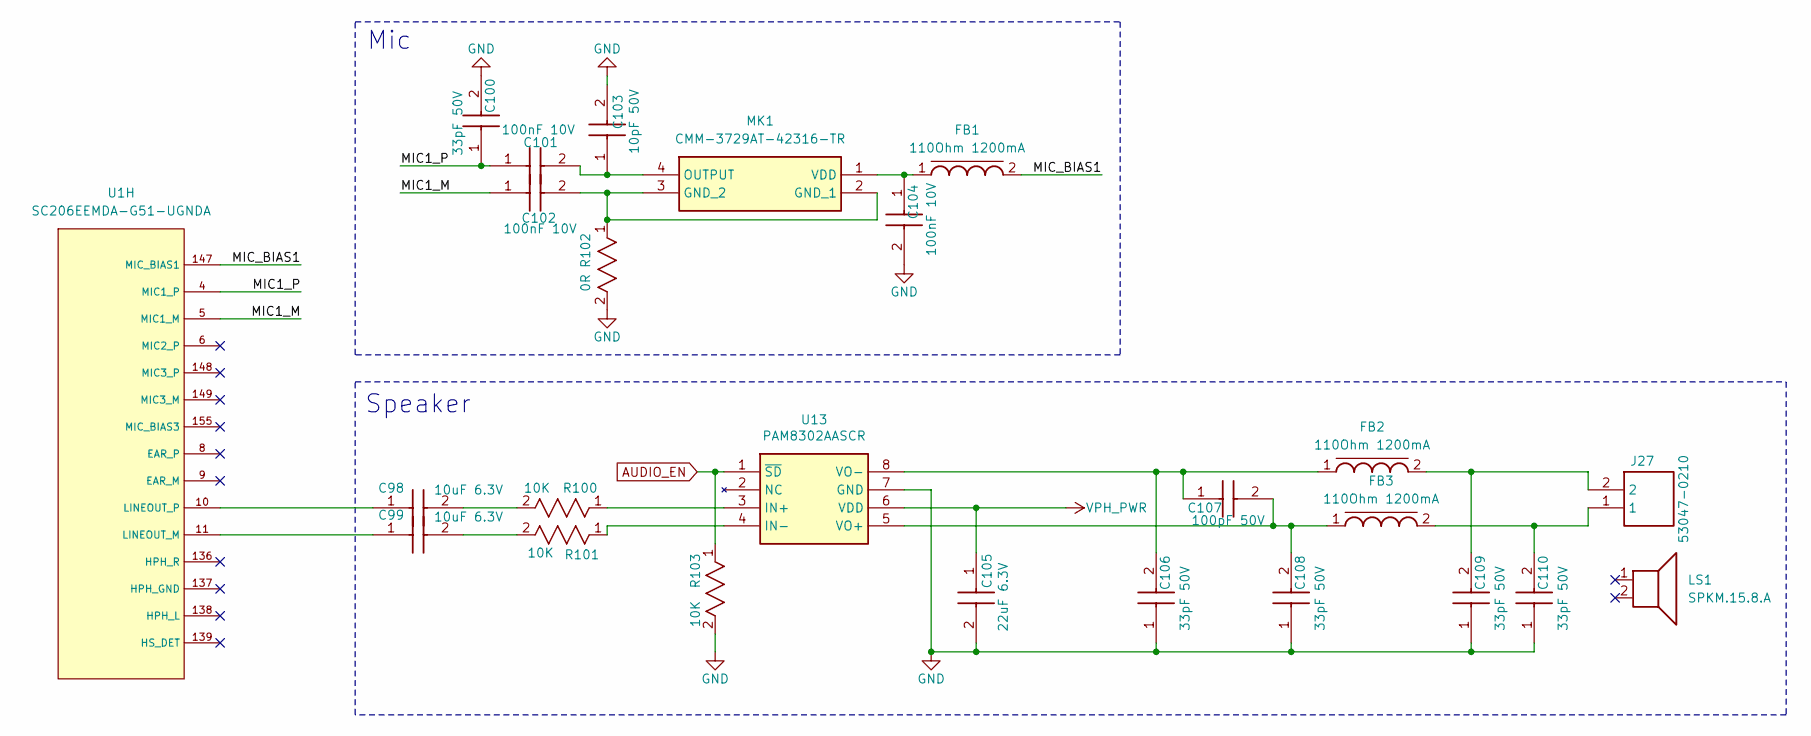
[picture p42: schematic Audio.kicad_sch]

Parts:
C98, C99: 10uF 6.3V; CAPC1005X55N; Part Number GRM155R60J106ME15D
C100, C106, C108, C109, C110: 33pF 50V; CAPC1005X55N; Part Number GRM1555C1H330JA01D
C101, C102, C104: 100nF 10V; CAPC1005X55N; Part Number GRM155R71A104KA01D
C103: 10pF 50V; CAPC1005X55N; Part Number GRM1555C1H100JA01D
C105: 22uF 6.3V; CAPC1005X55N; Part Number GRM158R60J226ME01D
C107: 100pF 50V; CAPC1005X55N; Part Number GRM1555C1H101JA01J
FB1, FB2, FB3: 110Ohm 1200mA; BEADC1005X55N; Part Number 74269242111
J27: 53047-0210; 530470210; Part Number 53047-0210
LS1: SPKM.15.8.A; Part Number SPKM.15.8.A
MK1: CMM-3729AT-42316-TR; CMM3729AT42316TR; Part Number CMM-3729AT-42316-TR
R100, R101, R103: 10K; RC0402N_YAG; Part Number RC0402JR-0710KL
R102: 0R; RC0402N_YAG; Part Number RC0402JR-070RL
U1: SC206EEMDA-G51-UGNDA; SC200E_SC206E; Part Number SC200EEMNA-E53-UGNDA
U13: PAM8302AASCR; SOP65P490X110-8N; Part Number PAM8302AASCR

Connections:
/Audio/MIC1_M: C102.1, U1.5 (MIC1_M)
/Audio/MIC1_P: C100.1, C101.1, U1.4 (MIC1_P)
/Audio/MIC_BIAS1: FB1.2, U1.147 (MIC_BIAS1)
AUDIO_EN: R103.1, U13.1 (~SD); also elsewhere on the board
GND: C100.2, C103.2, C104.2, C105.2, C106.1, C108.1, C109.1, C110.1, R102.2, R103.2, U13.7 (GND); also elsewhere on the board
unnamed: C98.2, R100.2
unnamed: C99.2, R101.2
unnamed: C109.2, FB2.2, J27.2
unnamed: C110.2, FB3.2, J27.1
unnamed: C102.2, MK1.2 (GND_1), MK1.3 (GND_2), R102.1
unnamed: C101.2, C103.1, MK1.4 (OUTPUT)
unnamed: C104.1, FB1.1, MK1.1 (VDD)
unnamed: C99.1, U1.11 (LINEOUT_M)
unnamed: C98.1, U1.10 (LINEOUT_P)
unnamed: R100.1, U13.3 (IN+)
unnamed: R101.1, U13.4 (IN-)
unnamed: C107.2, C108.2, FB3.1, U13.5 (VO+)
unnamed: C106.2, C107.1, FB2.1, U13.8 (VO-)
VPH_PWR: C105.1, U13.6 (VDD); also elsewhere on the board

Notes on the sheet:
Mic
Speaker

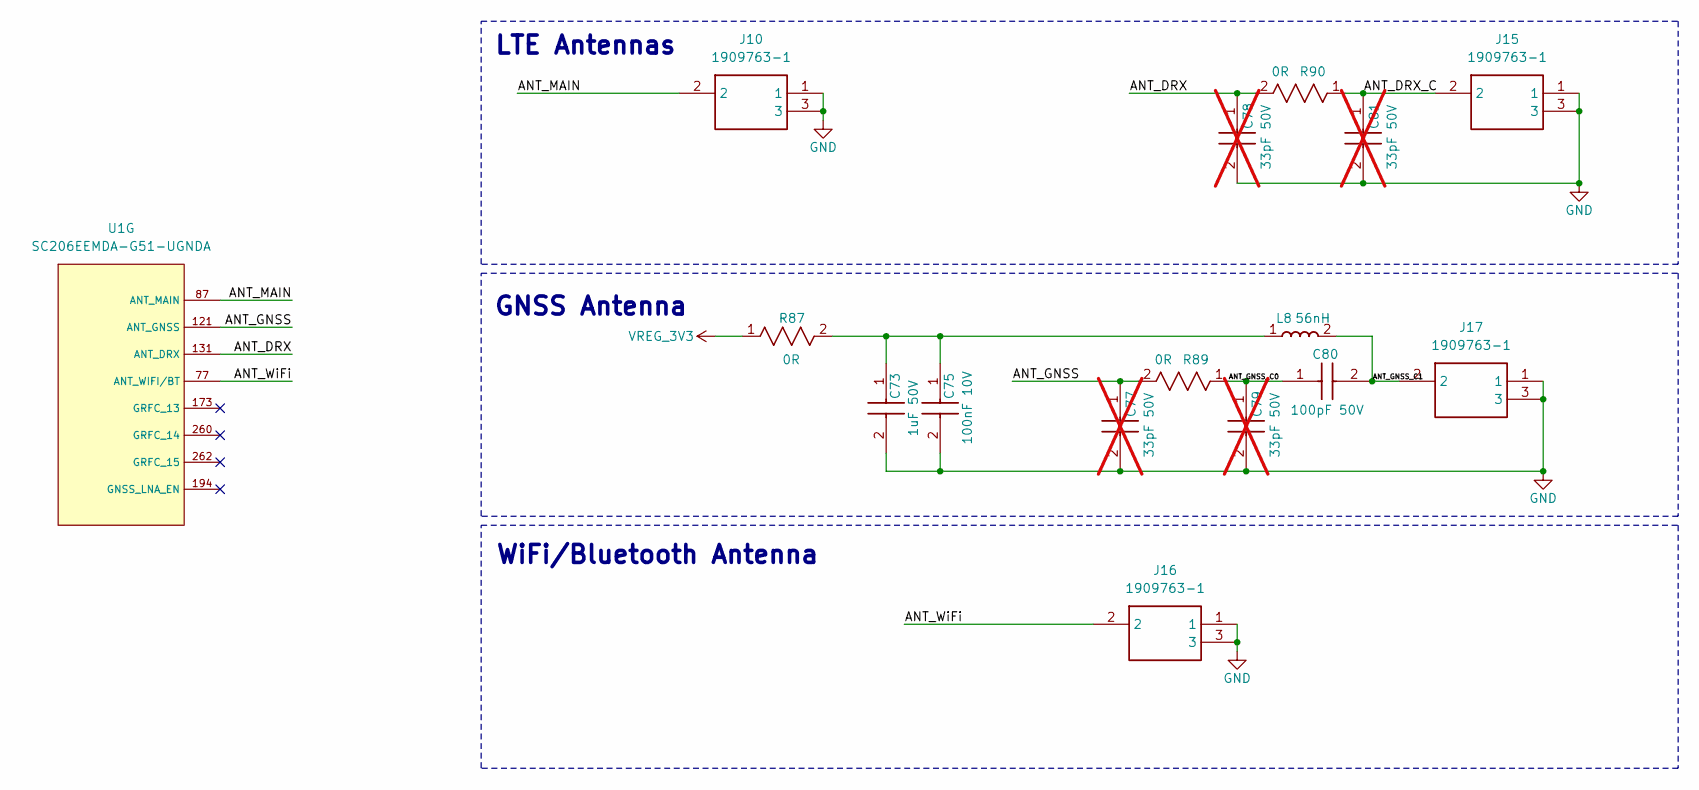
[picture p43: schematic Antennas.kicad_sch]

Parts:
C73: 1uF 50V; CAPC1005X55N; Part Number GRM155R61H105KE05D
C75: 100nF 10V; CAPC1005X55N; Part Number GRM155R71A104KA01D
C77, C78, C79, C81: 33pF 50V; CAPC1005X55N; Part Number GRM1555C1H330JA01D; not fitted
C80: 100pF 50V; CAPC1005X55N; Part Number GRM1555C1H101JA01J
J10, J15, J16, J17: 1909763-1; Part Number 1909763-1
L8: 56nH; INDC1005X60N; Part Number 744784156A
R87: 0R; RESC2012X50N; Part Number CRCW08050000Z0EA
R89, R90: 0R; RC0402N_YAG; Part Number RC0402JR-070RL
U1: SC206EEMDA-G51-UGNDA; SC200E_SC206E; Part Number SC200EEMNA-E53-UGNDA

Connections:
/Antennas/ANT_DRX: C78.1, R90.2, U1.131 (ANT_DRX)
/Antennas/ANT_DRX_C: C81.1, J15.2, R90.1
/Antennas/ANT_GNSS: C77.1, R89.2, U1.121 (ANT_GNSS)
/Antennas/ANT_GNSS_C0: C79.1, C80.1, R89.1
/Antennas/ANT_GNSS_C1: C80.2, J17.2, L8.2
/Antennas/ANT_MAIN: J10.2, U1.87 (ANT_MAIN)
/Antennas/ANT_WiFi: J16.2, U1.77 (ANT_WIFI/BT)
GND: C73.2, C75.2, C77.2, C78.2, C79.2, C81.2, J10.1, J10.3, J15.1, J15.3, J16.1, J16.3, J17.1, J17.3; also elsewhere on the board
unnamed: C73.1, C75.1, L8.1, R87.2
VREG_3V3: R87.1; also elsewhere on the board

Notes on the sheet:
WiFi/Bluetooth Antenna
LTE Antennas
GNSS Antenna

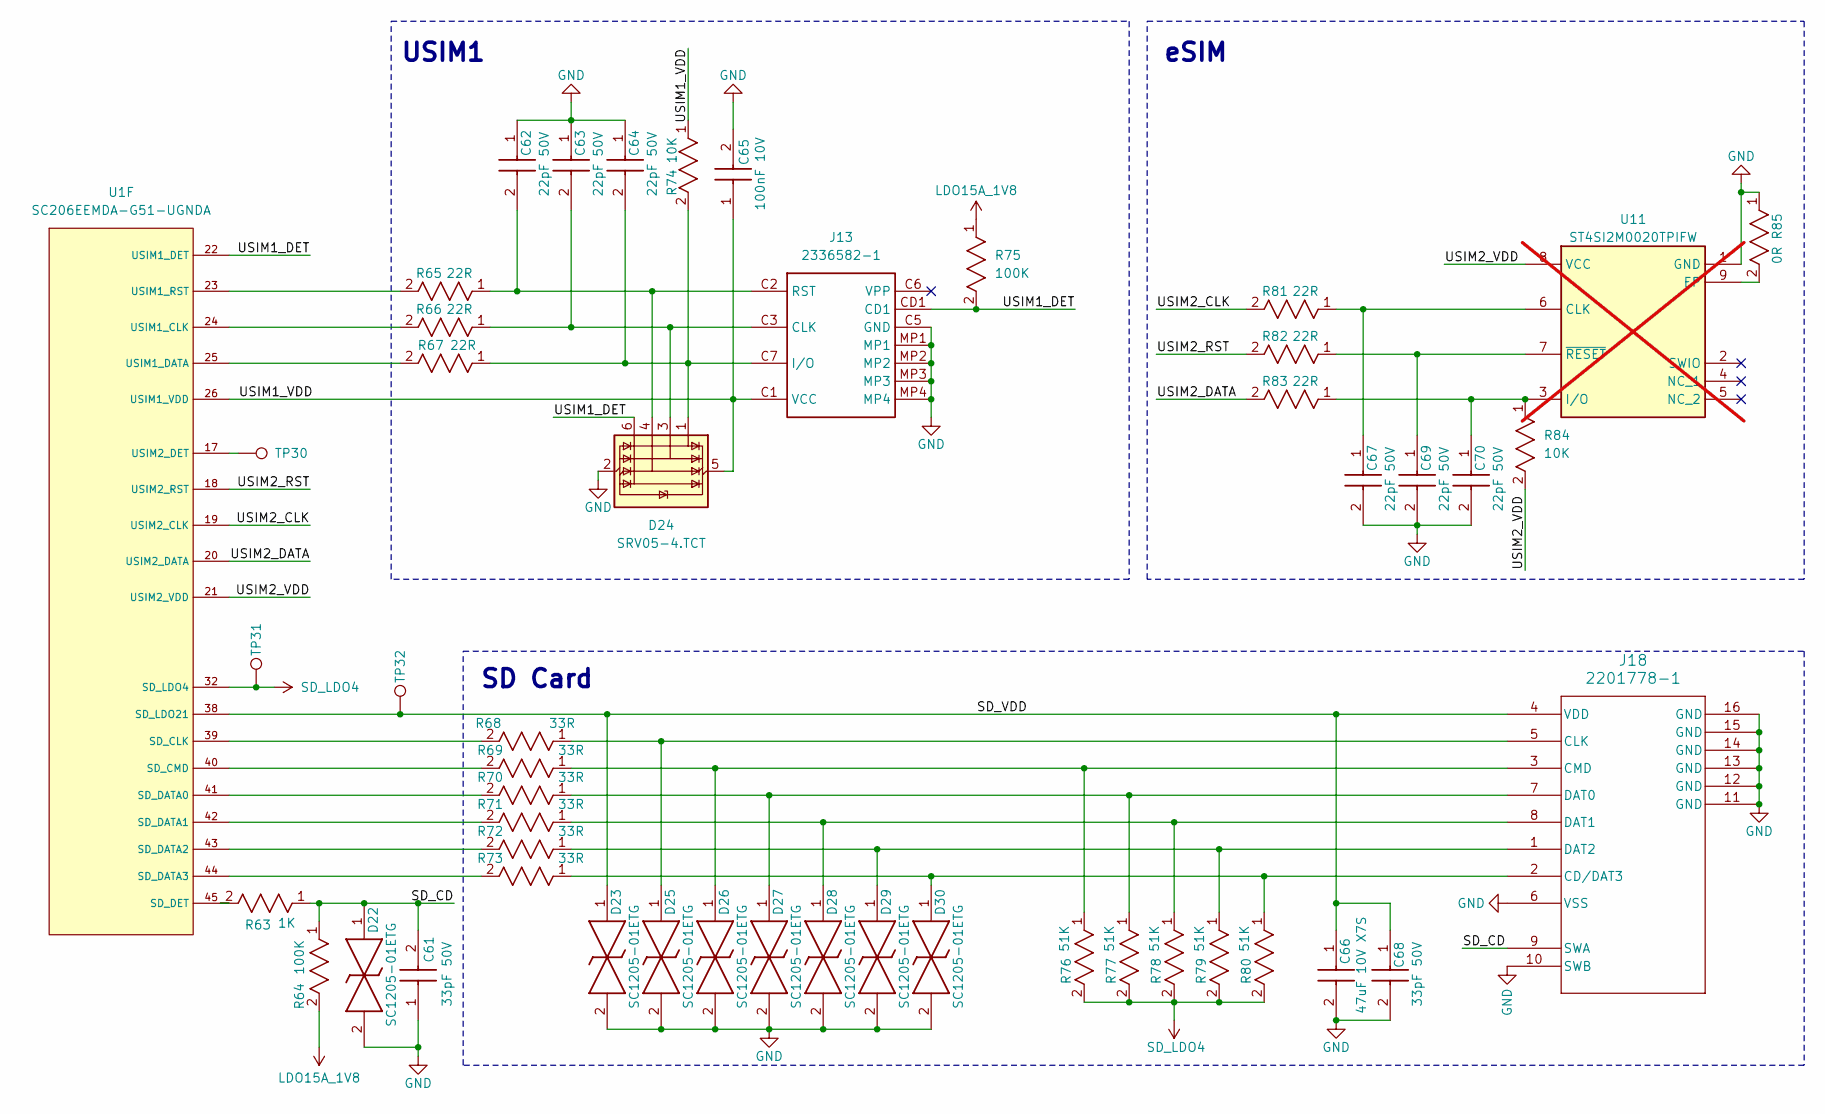
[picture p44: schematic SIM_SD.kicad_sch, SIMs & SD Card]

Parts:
C61, C68: 33pF 50V; CAPC1005X55N; Part Number GRM1555C1H330JA01D
C62, C63, C64, C67, C69, C70: 22pF 50V; CAPC1005X55N; Part Number GRM1555C1H220JA01D
C65: 100nF 10V; CAPC1005X55N; Part Number GRM155R71A104KA01D
C66: 47uF 10V X7S; CAPC3225X280N; Part Number CGA6P1X7S1A476M250AC
D22, D23, D25, D26, D27, D28, D29, D30: SC1205-01ETG; SC120501ETG; Part Number SC1205-01ETG
D24: SRV05-4.TCT; SOT95P280X145-6N; Part Number SRV05-4.TCT
J13: 2336582-1; 23365821; Part Number 2336582-1
J18: 2201778-1; 2201778-1_TEC; Part Number 2201778-1
R63: 1K; RC0402N_YAG; Part Number RC0402JR-071KL
R64, R75: 100K; RC0402N_YAG; Part Number RC0402JR-07100KL
R65, R66, R67, R81, R82, R83: 22R; RC0402N_YAG; Part Number RC0402JR-0722RL
R68, R69, R70, R71, R72, R73: 33R; RC0402N_YAG; Part Number RC0402JR-0733RL
R74, R84: 10K; RC0402N_YAG; Part Number RC0402JR-0710KL
R76, R77, R78, R79, R80: 51K; RC0402N_YAG; Part Number RC0402JR-0751KL
R85: 0R; RC0402N_YAG; Part Number RC0402JR-070RL
TP30, TP31, TP32: TestPoint; TestPoint_Pad_D1.0mm
U1: SC206EEMDA-G51-UGNDA; SC200E_SC206E; Part Number SC200EEMNA-E53-UGNDA
U11: ST4SI2M0020TPIFW; SON127P600X500X100-9N; Part Number ST4SI2M0020TPIFW; not fitted

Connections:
/SIM_SD/SD_CD: C61.2, D22.1, J18.9 (SWA), R63.1, R64.1
/SIM_SD/SD_VDD: C66.1, C68.1, D23.1, J18.4 (VDD), TP32.1, U1.38 (SD_LDO21)
/SIM_SD/USIM1_DET: D24.6 (I/O4), J13.CD1, R75.2, U1.22 (USIM1_DET)
/SIM_SD/USIM1_VDD: C65.1, D24.5 (VBUS), J13.C1 (VCC), R74.1, U1.26 (USIM1_VDD)
/SIM_SD/USIM2_CLK: R81.2, U1.19 (USIM2_CLK)
/SIM_SD/USIM2_DATA: R83.2, U1.20 (USIM2_DATA)
/SIM_SD/USIM2_RST: R82.2, U1.18 (USIM2_RST)
/SIM_SD/USIM2_VDD: R84.2, U1.21 (USIM2_VDD), U11.8 (VCC)
GND: C61.1, C62.1, C63.1, C64.1, C65.2, C66.2, C67.2, C68.2, C69.2, C70.2, D22.2, D23.2, D24.2 (GND), D25.2, D26.2, D27.2, D28.2, D29.2, D30.2, J13.C5 (GND), J13.MP1, J13.MP2, J13.MP3, J13.MP4, J18.6 (VSS), J18.10 (SWB), J18.11 (GND), J18.12 (GND), J18.13 (GND), J18.14 (GND), J18.15 (GND), J18.16 (GND), R85.1, U11.1 (GND); also elsewhere on the board
LDO15A_1V8: R64.2, R75.1; also elsewhere on the board
unnamed: C64.2, D24.1 (I/O1), J13.C7 (I/O), R67.1, R74.2
unnamed: C63.2, D24.3 (I/O2), J13.C3 (CLK), R66.1
unnamed: C62.2, D24.4 (I/O3), J13.C2 (RST), R65.1
unnamed: D30.1, J18.2 (CD/DAT3), R73.1, R80.1
unnamed: D25.1, J18.5 (CLK), R68.1
unnamed: D26.1, J18.3 (CMD), R69.1, R76.1
unnamed: D27.1, J18.7 (DAT0), R70.1, R77.1
unnamed: D28.1, J18.8 (DAT1), R71.1, R78.1
unnamed: D29.1, J18.1 (DAT2), R72.1, R79.1
unnamed: R68.2, U1.39 (SD_CLK)
unnamed: R69.2, U1.40 (SD_CMD)
unnamed: R70.2, U1.41 (SD_DATA0)
unnamed: R71.2, U1.42 (SD_DATA1)
unnamed: R72.2, U1.43 (SD_DATA2)
unnamed: R73.2, U1.44 (SD_DATA3)
unnamed: R63.2, U1.45 (SD_DET)
unnamed: R66.2, U1.24 (USIM1_CLK)
unnamed: R67.2, U1.25 (USIM1_DATA)
unnamed: R65.2, U1.23 (USIM1_RST)
unnamed: TP30.1, U1.17 (USIM2_DET)
unnamed: C67.1, R81.1, U11.6 (CLK)
unnamed: R85.2, U11.9 (EP)
unnamed: C70.1, R83.1, R84.1, U11.3 (I/O)
unnamed: C69.1, R82.1, U11.7 (~RESET)
SD_LDO4: R76.2, R77.2, R78.2, R79.2, R80.2, TP31.1, U1.32 (SD_LDO4)

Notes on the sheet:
eSIM
USIM1
SD Card

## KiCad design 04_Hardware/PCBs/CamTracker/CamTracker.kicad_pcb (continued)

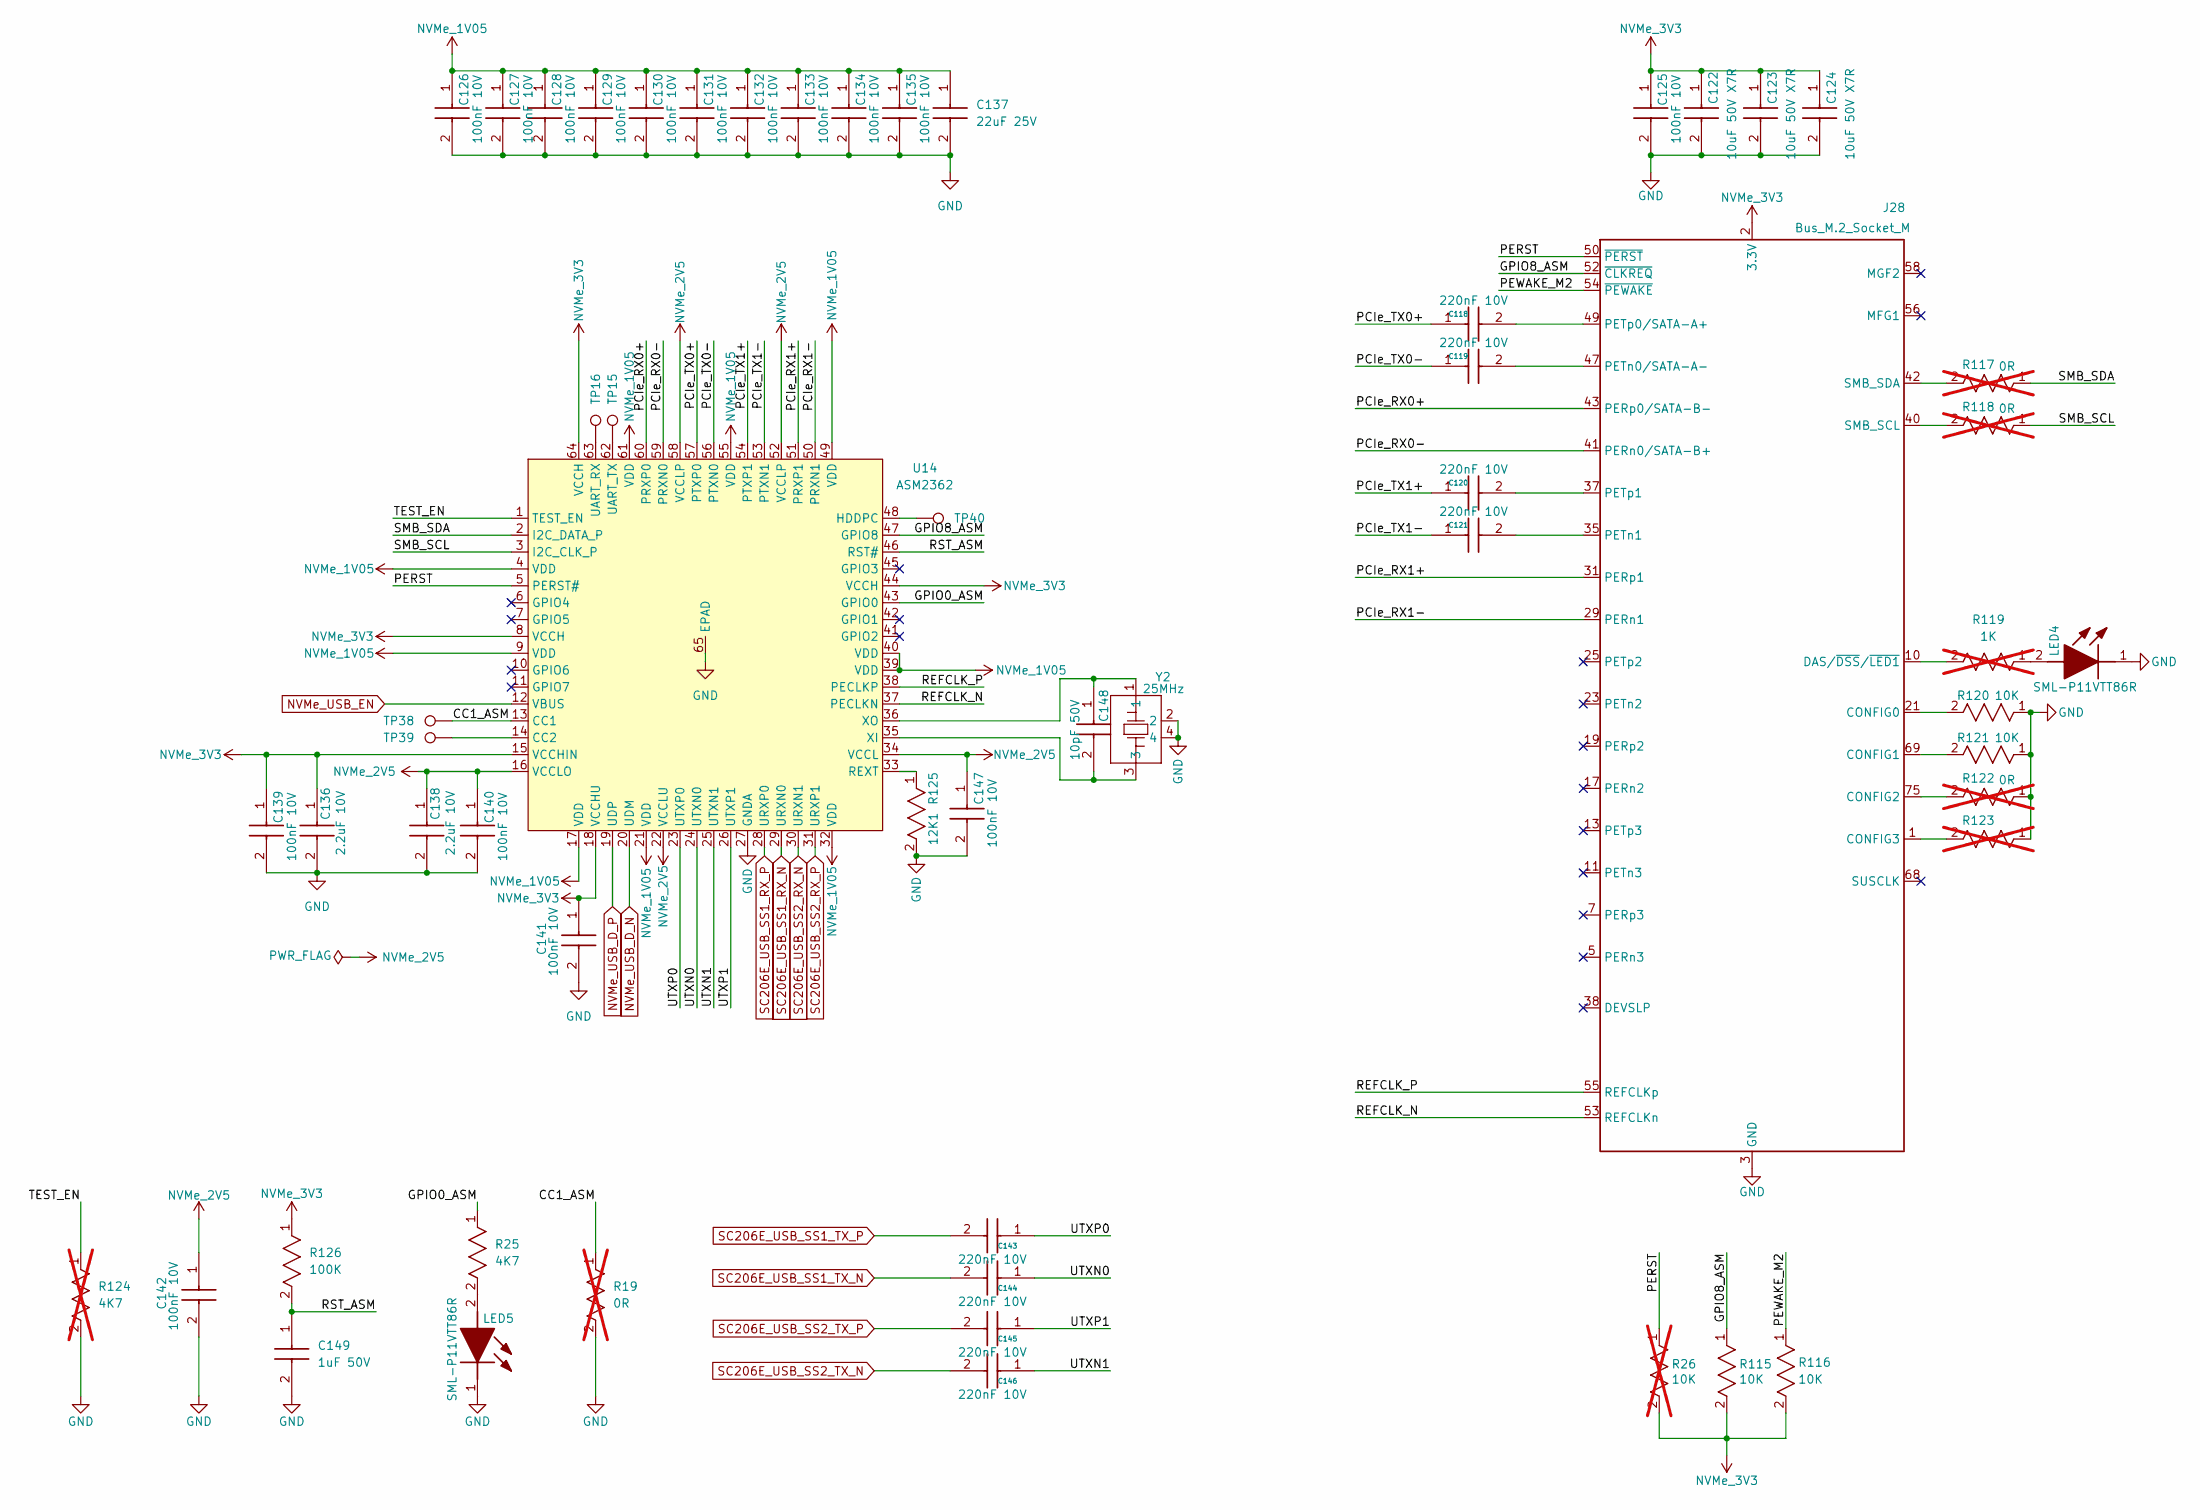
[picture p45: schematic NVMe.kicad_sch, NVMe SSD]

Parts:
C118, C119, C120, C121, C143, C144, C145, C146: 220nF 10V; CAPC1005X55N; Part Number GRM155R61A224JE19D
C122, C123, C124: 10uF 50V X7R; CAPC3216X190N; Part Number CL31B106KBK6PJE
C125, C126, C127, C128, C129, C130, C131, C132, C133, C134, C135, C139, C140, C141, C142, C147: 100nF 10V; CAPC1005X55N; Part Number GRM155R71A104KA01D
C136, C138: 2.2uF 10V; CAPC1608X90N; Part Number LMK107BJ225KA-T
C137: 22uF 25V; CAPC2012X145N; Part Number GRM21BR61E226ME44L
C148: 10pF 50V; CAPC1005X55N; Part Number GRM1555C1H100JA01D
C149: 1uF 50V; CAPC1005X55N; Part Number GRM155R61H105KE05D
J28: Bus_M.2_Socket_M; NVMEE; Part Number 1-2199230-4
LED4, LED5: SML-P11VTT86R; SMLP11VTT86R; Part Number SML-P11VTT86R
R19: 0R; RESC2012X50N; Part Number CRCW08050000Z0EA; not fitted
R25: 4K7; RC0402N_YAG; Part Number RC0402JR-074K7L
R26: 10K; RC0402N_YAG; Part Number RC0402JR-0710KL; not fitted
R115, R116, R120, R121: 10K; RC0402N_YAG; Part Number RC0402JR-0710KL
R117, R118, R122, R123: 0R; RC0402N_YAG; Part Number RC0402JR-070RL; not fitted
R119: 1K; RC0402N_YAG; Part Number RC0402JR-071KL; not fitted
R124: 4K7; RC0402N_YAG; Part Number RC0402JR-074K7L; not fitted
R125: 12K1; RC0402N_YAG; Part Number RC0402FR-0712K1P
R126: 100K; RC0402N_YAG; Part Number RC0402JR-07100KL
TP15, TP16, TP38, TP39, TP40: 3.86V; TestPoint_Pad_D1.0mm
U14: ASM2362; QFN50P905X905X75-65N; Part Number ASM2362
Y2: 25MHz; FL2500188; Part Number FL2500188

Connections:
/NVMe/CC1_ASM: R19.1, TP38.1, U14.13 (CC1)
/NVMe/GPIO0_ASM: R25.1, U14.43 (GPIO0)
/NVMe/GPIO8_ASM: J28.52 (~CLKREQ), R115.1, U14.47 (GPIO8)
/NVMe/PCIe_RX0+: J28.43 (PERp0/SATA-B-), U14.60 (PRXP0)
/NVMe/PCIe_RX0-: J28.41 (PERn0/SATA-B+), U14.59 (PRXN0)
/NVMe/PCIe_RX1+: J28.31 (PERp1), U14.51 (PRXP1)
/NVMe/PCIe_RX1-: J28.29 (PERn1), U14.50 (PRXN1)
/NVMe/PCIe_TX0+: C118.1, U14.57 (PTXP0)
/NVMe/PCIe_TX0-: C119.1, U14.56 (PTXN0)
/NVMe/PCIe_TX1+: C120.1, U14.54 (PTXP1)
/NVMe/PCIe_TX1-: C121.1, U14.53 (PTXN1)
/NVMe/PERST: J28.50 (~PERST), R26.1, U14.5 (PERST#)
/NVMe/PEWAKE_M2: J28.54 (~PEWAKE), R116.1
/NVMe/REFCLK_N: J28.53 (REFCLKn), U14.37 (PECLKN)
/NVMe/REFCLK_P: J28.55 (REFCLKp), U14.38 (PECLKP)
/NVMe/RST_ASM: C149.1, R126.2, U14.46 (RST#)
/NVMe/SMB_SCL: R118.1, U14.3 (I2C_CLK_P)
/NVMe/SMB_SDA: R117.1, U14.2 (I2C_DATA_P)
/NVMe/TEST_EN: R124.1, U14.1 (TEST_EN)
/NVMe/UTXN0: C144.1, U14.24 (UTXN0)
/NVMe/UTXN1: C146.1, U14.25 (UTXN1)
/NVMe/UTXP0: C143.1, U14.23 (UTXP0)
/NVMe/UTXP1: C145.1, U14.26 (UTXP1)
GND: C122.2, C123.2, C124.2, C125.2, C126.2, C127.2, C128.2, C129.2, C130.2, C131.2, C132.2, C133.2, C134.2, C135.2, C136.2, C137.2, C138.2, C139.2, C140.2, C141.2, C142.2, C147.2, C149.2, J28.0 (GND), J28.3 (GND), J28.9 (GND), J28.15 (GND), J28.27 (GND), J28.33 (GND), J28.39 (GND), J28.45 (GND), J28.51 (GND), J28.57 (GND), J28.71 (GND), J28.73 (GND), J28.76 (GND), J28.77 (GND), LED4.1 (K), LED5.1 (K), R19.2, R120.1, R121.1, R122.1, R123.1, R124.2, R125.2, U14.27 (GNDA), U14.65 (EPAD), Y2.2, Y2.4; also elsewhere on the board
NVMe_1V05: C126.1, C127.1, C128.1, C129.1, C130.1, C131.1, C132.1, C133.1, C134.1, C135.1, C137.1, U14.4 (VDD), U14.9 (VDD), U14.17 (VDD), U14.21 (VDD), U14.32 (VDD), U14.39 (VDD), U14.40 (VDD), U14.49 (VDD), U14.55 (VDD), U14.61 (VDD); also elsewhere on the board
NVMe_2V5: C138.1, C140.1, C142.1, C147.1, U14.16 (VCCLO), U14.22 (VCCLU), U14.34 (VCCL), U14.52 (VCCLP), U14.58 (VCCLP)
NVMe_3V3: C122.1, C123.1, C124.1, C125.1, C136.1, C139.1, C141.1, J28.2 (3.3V), J28.4 (3.3V), J28.12 (3.3V), J28.14 (3.3V), J28.16 (3.3V), J28.18 (3.3V), J28.70 (3.3V), J28.72 (3.3V), J28.74 (3.3V), R26.2, R115.2, R116.2, R126.1, U14.8 (VCCH), U14.15 (VCCHIN), U14.18 (VCCHU), U14.44 (VCCH), U14.64 (VCCH); also elsewhere on the board
NVMe_USB_D_N: U14.20 (UDM); also elsewhere on the board
NVMe_USB_D_P: U14.19 (UDP); also elsewhere on the board
NVMe_USB_EN: U14.12 (VBUS); also elsewhere on the board
unnamed: J28.21 (CONFIG0), R120.2
unnamed: J28.69 (CONFIG1), R121.2
unnamed: J28.75 (CONFIG2), R122.2
unnamed: J28.1 (CONFIG3), R123.2
unnamed: J28.10 (DAS/~DSS/~LED1), R119.2
unnamed: C119.2, J28.47 (PETn0/SATA-A-)
unnamed: C121.2, J28.35 (PETn1)
unnamed: C118.2, J28.49 (PETp0/SATA-A+)
unnamed: C120.2, J28.37 (PETp1)
unnamed: J28.40 (SMB_SCL), R118.2
unnamed: J28.42 (SMB_SDA), R117.2
unnamed: LED4.2 (A), R119.1
unnamed: LED5.2 (A), R25.2
unnamed: TP39.1, U14.14 (CC2)
unnamed: TP40.1, U14.48 (HDDPC)
unnamed: R125.1, U14.33 (REXT)
unnamed: TP16.1, U14.63 (UART_RX)
unnamed: TP15.1, U14.62 (UART_TX)
unnamed: C148.2, U14.35 (XI), Y2.3
unnamed: C148.1, U14.36 (XO), Y2.1
SC206E_USB_SS1_RX_N: U14.29 (URXN0); also elsewhere on the board
SC206E_USB_SS1_RX_P: U14.28 (URXP0); also elsewhere on the board
SC206E_USB_SS1_TX_N: C144.2; also elsewhere on the board
SC206E_USB_SS1_TX_P: C143.2; also elsewhere on the board
SC206E_USB_SS2_RX_N: U14.30 (URXN1); also elsewhere on the board
SC206E_USB_SS2_RX_P: U14.31 (URXP1); also elsewhere on the board
SC206E_USB_SS2_TX_N: C146.2; also elsewhere on the board
SC206E_USB_SS2_TX_P: C145.2; also elsewhere on the board

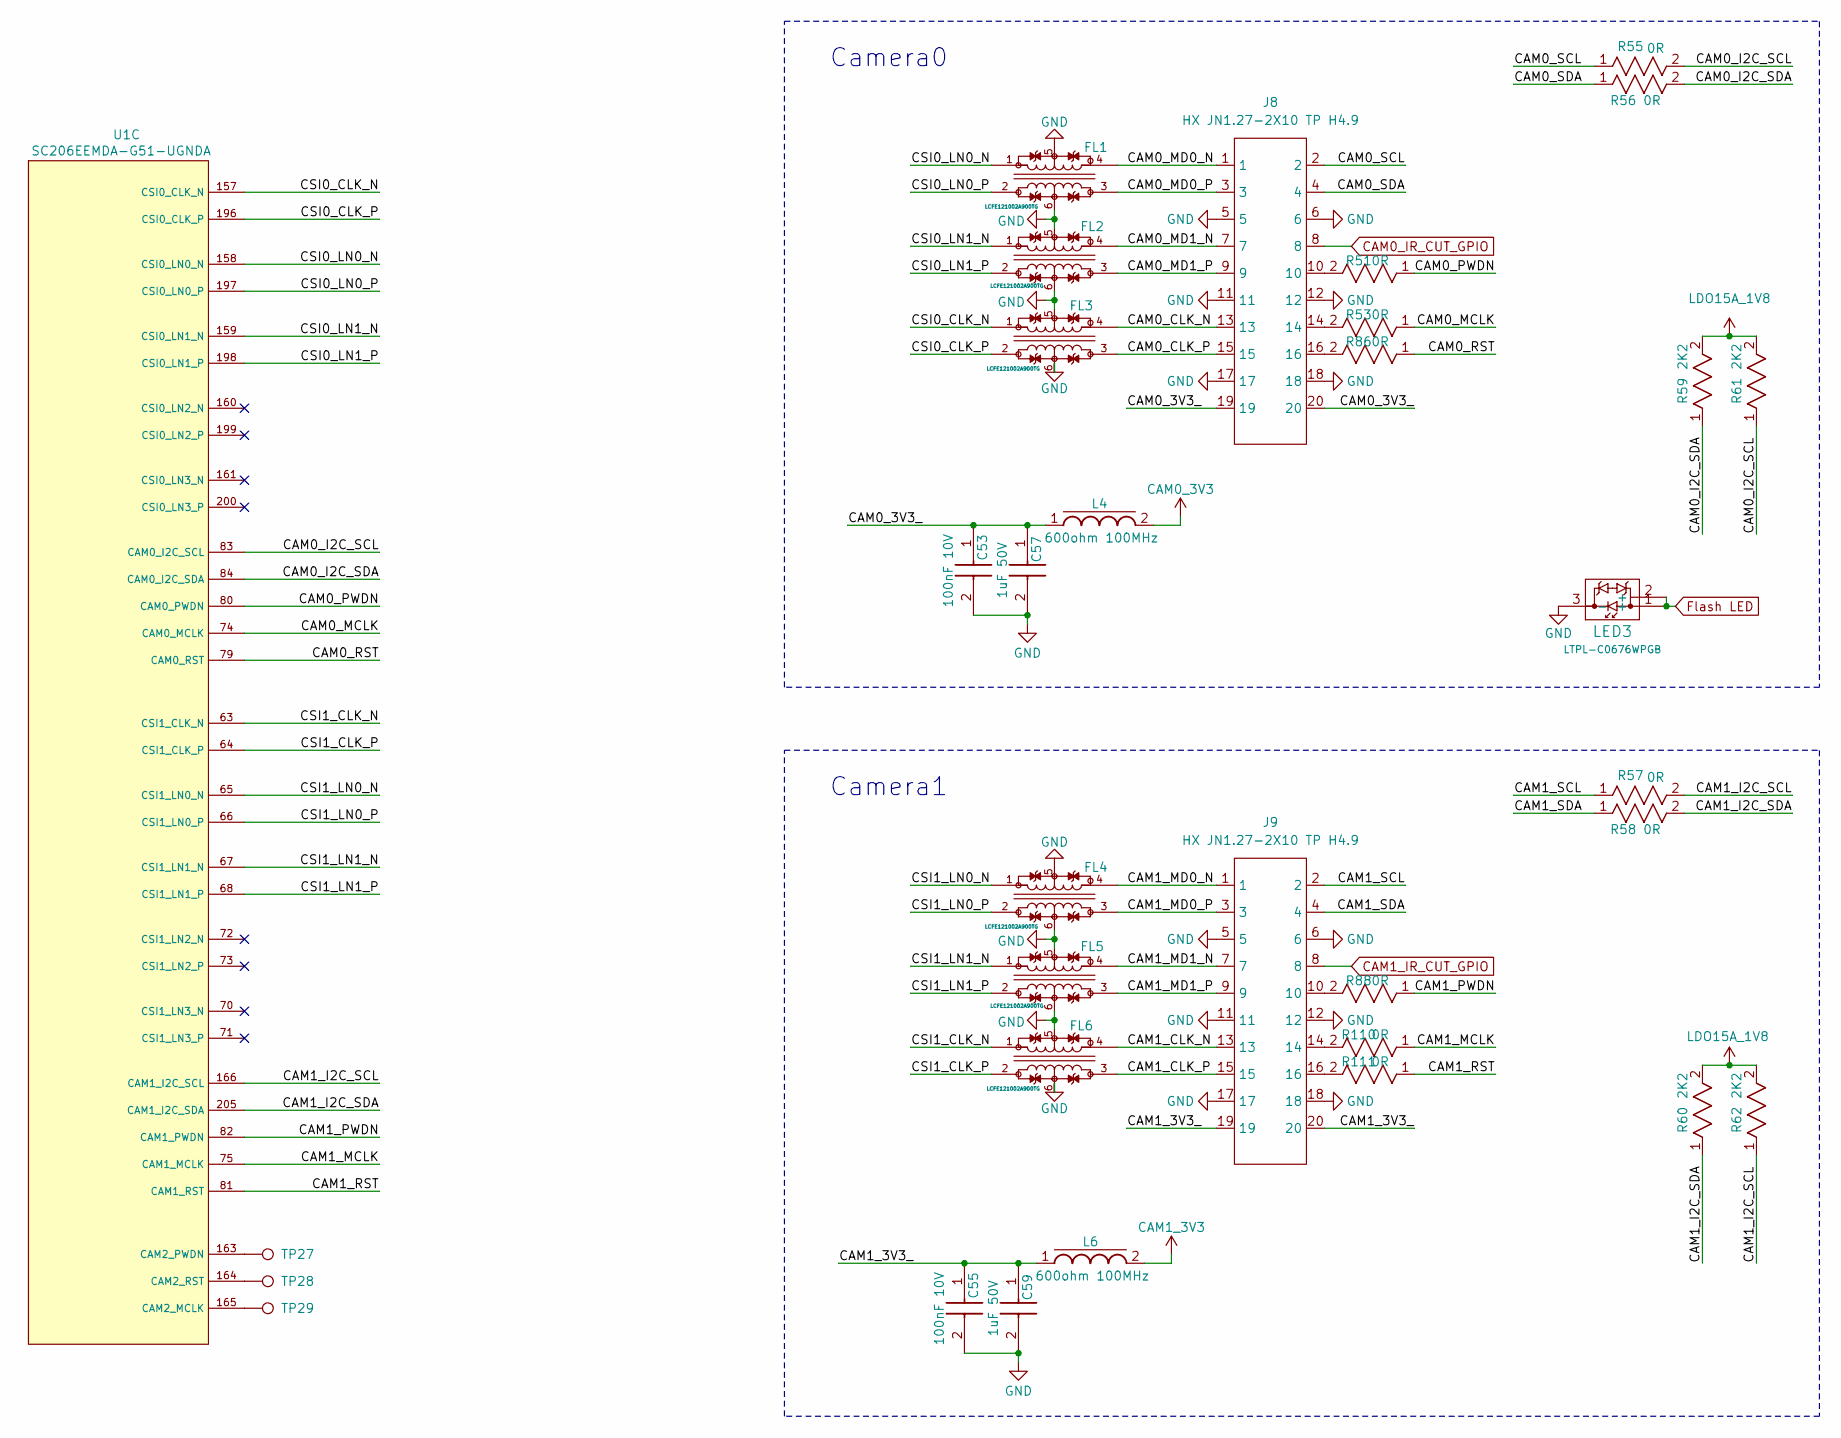
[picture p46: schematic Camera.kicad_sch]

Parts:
C53, C55: 100nF 10V; CAPC1005X55N; Part Number GRM155R71A104KA01D
C57, C59: 1uF 50V; CAPC1005X55N; Part Number GRM155R61H105KE05D
FL1, FL2, FL3, FL4, FL5, FL6: LCFE121002A900TG; Part Number LCFE121002A900TG
J8, J9: HX JN1.27-2X10 TP H4.9; CONN-SMD_HX-JN1.27-2X10-TP-H4.9; Part Number HX JN1.27-2x10 TP H4.9
L4, L6: 600ohm 100MHz; 0402; Part Number 7427927291
LED3: LTPL-C0676WPGB; Part Number LTPL-C0676WPGB
R51, R53, R86, R88, R110, R111: 0R; RC0402N_YAG; Part Number RC0402JR-070RL
R55, R56, R57, R58: 0R; RESC2012X50N; Part Number CRCW08050000Z0EA
R59, R60, R61, R62: 2K2; RC0402N_YAG; Part Number RC0402JR-072K2L
TP27, TP28, TP29: TestPoint; TestPoint_Pad_D1.0mm
U1: SC206EEMDA-G51-UGNDA; SC200E_SC206E; Part Number SC200EEMNA-E53-UGNDA

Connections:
/Cameras/CAM0_3V3_: C53.1, C57.1, J8.19, J8.20, L4.1
/Cameras/CAM0_CLK_N: FL3.4, J8.13
/Cameras/CAM0_CLK_P: FL3.3, J8.15
/Cameras/CAM0_I2C_SCL: R55.2, R61.1, U1.83 (CAM0_I2C_SCL)
/Cameras/CAM0_I2C_SDA: R56.2, R59.1, U1.84 (CAM0_I2C_SDA)
/Cameras/CAM0_MCLK: R53.1, U1.74 (CAM0_MCLK)
/Cameras/CAM0_MD0_N: FL1.4, J8.1
/Cameras/CAM0_MD0_P: FL1.3, J8.3
/Cameras/CAM0_MD1_N: FL2.4, J8.7
/Cameras/CAM0_MD1_P: FL2.3, J8.9
/Cameras/CAM0_PWDN: R51.1, U1.80 (CAM0_PWDN)
/Cameras/CAM0_RST: R86.1, U1.79 (CAM0_RST)
/Cameras/CAM0_SCL: J8.2, R55.1
/Cameras/CAM0_SDA: J8.4, R56.1
/Cameras/CAM1_3V3_: C55.1, C59.1, J9.19, J9.20, L6.1
/Cameras/CAM1_CLK_N: FL6.4, J9.13
/Cameras/CAM1_CLK_P: FL6.3, J9.15
/Cameras/CAM1_I2C_SCL: R57.2, R62.1, U1.166 (CAM1_I2C_SCL)
/Cameras/CAM1_I2C_SDA: R58.2, R60.1, U1.205 (CAM1_I2C_SDA)
/Cameras/CAM1_MCLK: R110.1, U1.75 (CAM1_MCLK)
/Cameras/CAM1_MD0_N: FL4.4, J9.1
/Cameras/CAM1_MD0_P: FL4.3, J9.3
/Cameras/CAM1_MD1_N: FL5.4, J9.7
/Cameras/CAM1_MD1_P: FL5.3, J9.9
/Cameras/CAM1_PWDN: R88.1, U1.82 (CAM1_PWDN)
/Cameras/CAM1_RST: R111.1, U1.81 (CAM1_RST)
/Cameras/CAM1_SCL: J9.2, R57.1
/Cameras/CAM1_SDA: J9.4, R58.1
/Cameras/CSI0_CLK_N: FL3.1, U1.157 (CSI0_CLK_N)
/Cameras/CSI0_CLK_P: FL3.2, U1.196 (CSI0_CLK_P)
/Cameras/CSI0_LN0_N: FL1.1, U1.158 (CSI0_LN0_N)
/Cameras/CSI0_LN0_P: FL1.2, U1.197 (CSI0_LN0_P)
/Cameras/CSI0_LN1_N: FL2.1, U1.159 (CSI0_LN1_N)
/Cameras/CSI0_LN1_P: FL2.2, U1.198 (CSI0_LN1_P)
/Cameras/CSI1_CLK_N: FL6.1, U1.63 (CSI1_CLK_N)
/Cameras/CSI1_CLK_P: FL6.2, U1.64 (CSI1_CLK_P)
/Cameras/CSI1_LN0_N: FL4.1, U1.65 (CSI1_LN0_N)
/Cameras/CSI1_LN0_P: FL4.2, U1.66 (CSI1_LN0_P)
/Cameras/CSI1_LN1_N: FL5.1, U1.67 (CSI1_LN1_N)
/Cameras/CSI1_LN1_P: FL5.2, U1.68 (CSI1_LN1_P)
CAM0_3V3: L4.2; also elsewhere on the board
CAM0_IR_CUT_GPIO: J8.8; also elsewhere on the board
CAM1_3V3: L6.2; also elsewhere on the board
CAM1_IR_CUT_GPIO: J9.8; also elsewhere on the board
Flash LED: LED3.1 (+), LED3.2 (+); also elsewhere on the board
GND: C53.2, C55.2, C57.2, C59.2, FL1.5, FL1.6, FL2.5, FL2.6, FL3.5, FL3.6, FL4.5, FL4.6, FL5.5, FL5.6, FL6.5, FL6.6, J8.5, J8.6, J8.11, J8.12, J8.17, J8.18, J9.5, J9.6, J9.11, J9.12, J9.17, J9.18, LED3.3 (-); also elsewhere on the board
LDO15A_1V8: R59.2, R60.2, R61.2, R62.2; also elsewhere on the board
unnamed: J8.10, R51.2
unnamed: J8.14, R53.2
unnamed: J8.16, R86.2
unnamed: J9.10, R88.2
unnamed: J9.14, R110.2
unnamed: J9.16, R111.2
unnamed: TP29.1, U1.165 (CAM2_MCLK)
unnamed: TP27.1, U1.163 (CAM2_PWDN)
unnamed: TP28.1, U1.164 (CAM2_RST)

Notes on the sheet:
Camera0
Camera1

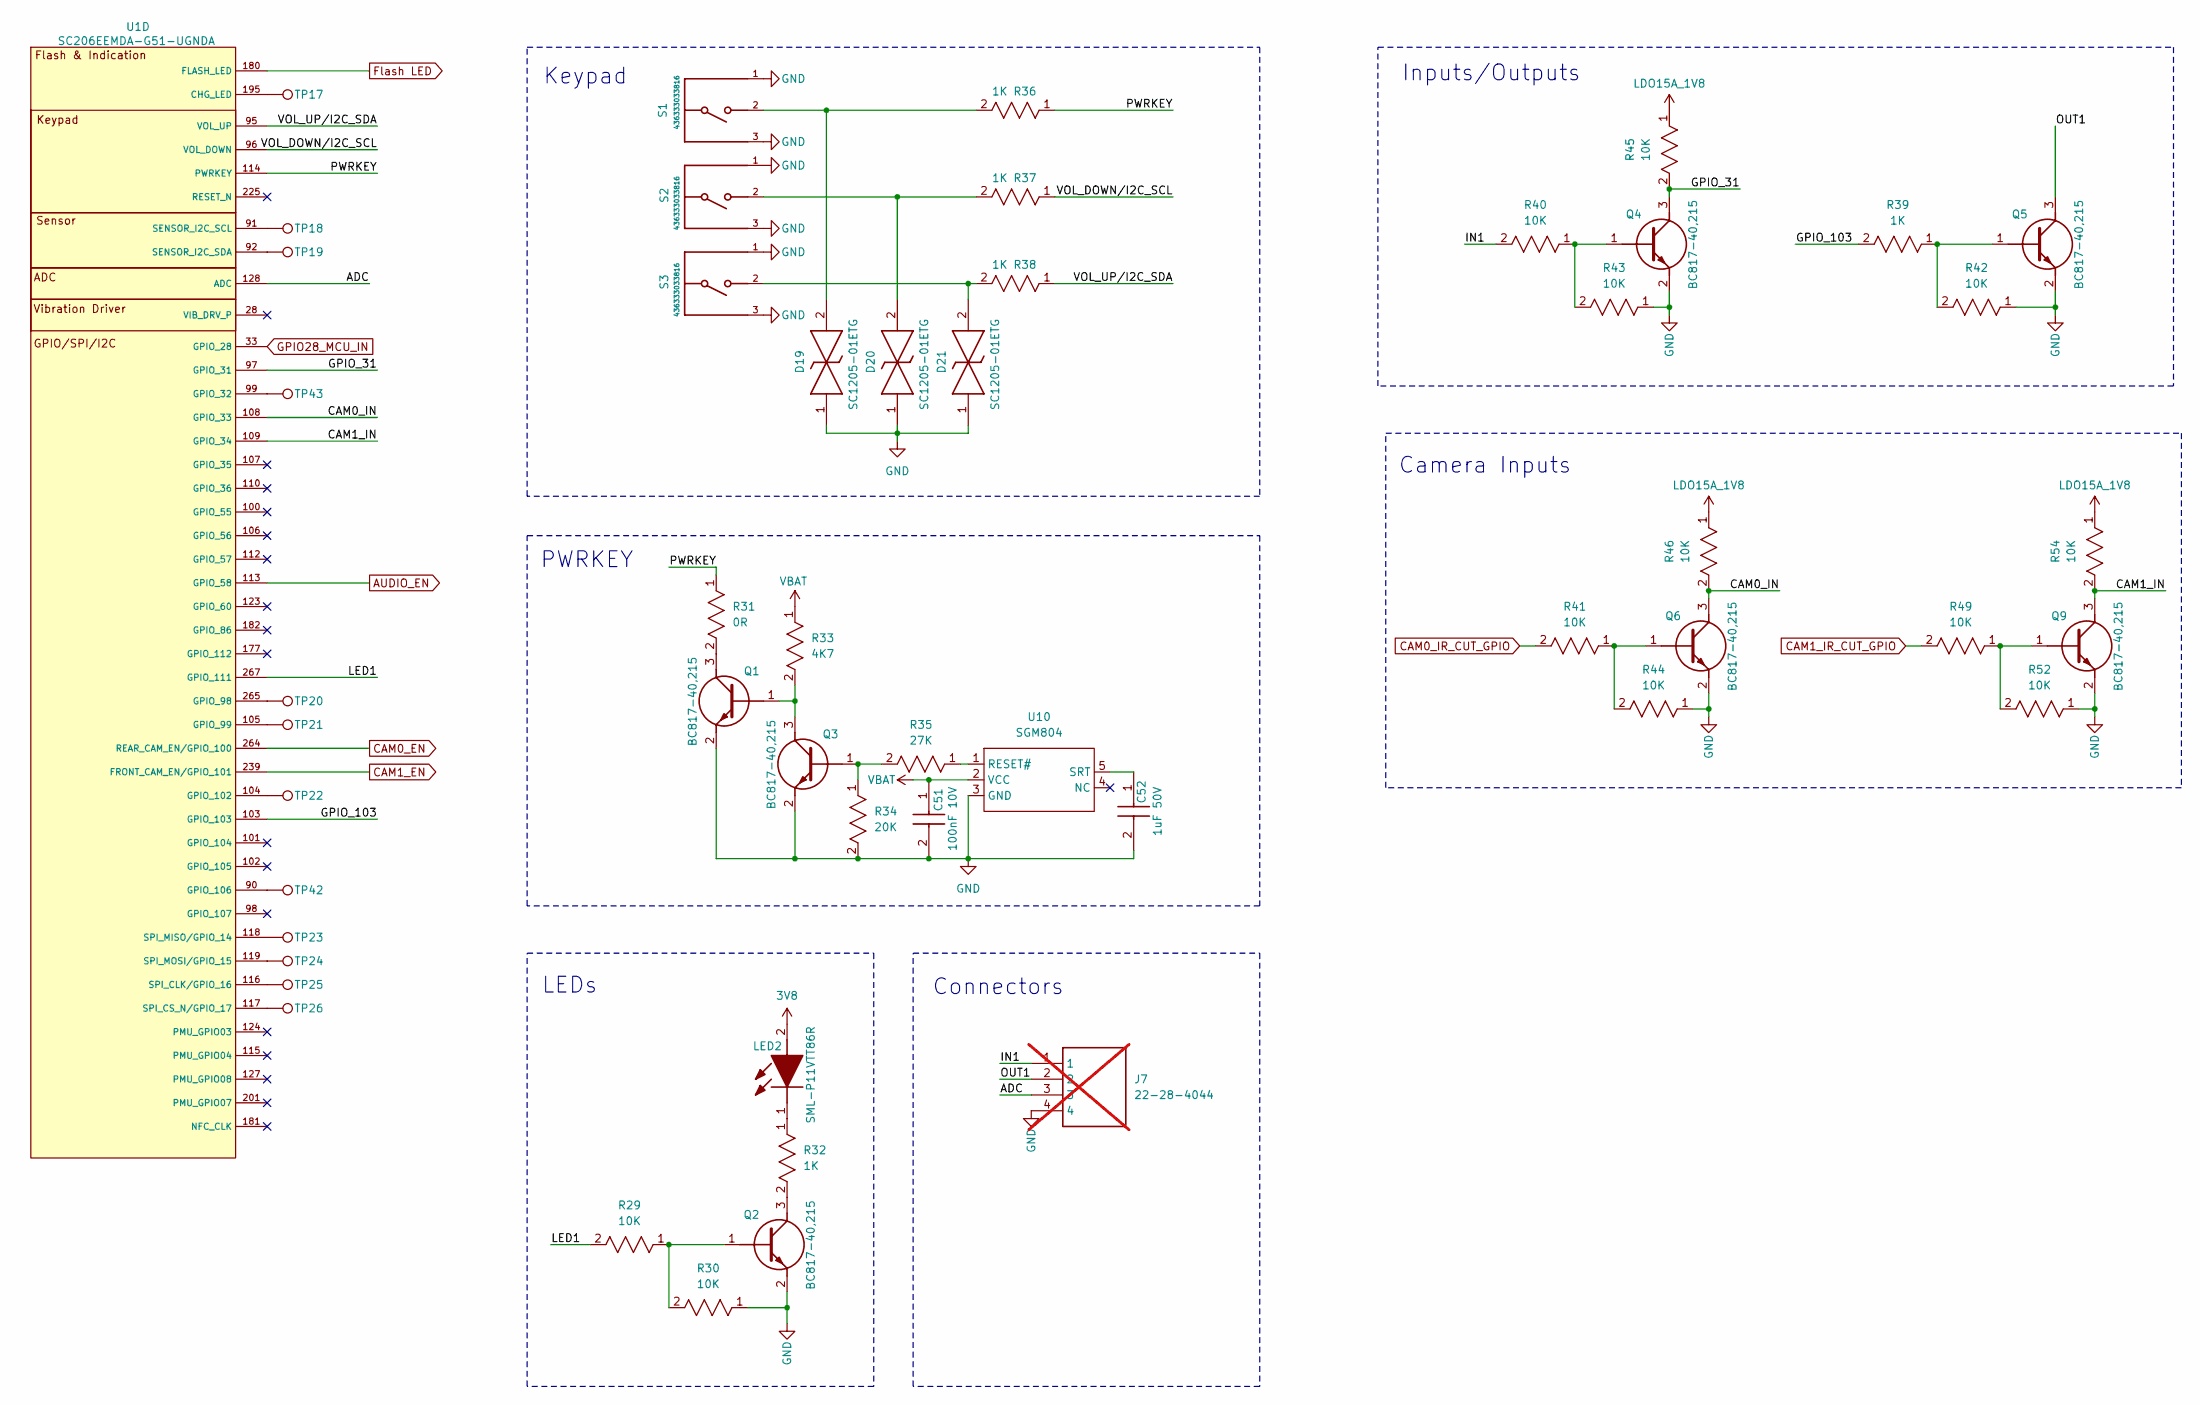
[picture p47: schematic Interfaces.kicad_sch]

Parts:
C51: 100nF 10V; CAPC1005X55N; Part Number GRM155R71A104KA01D
C52: 1uF 50V; CAPC1005X55N; Part Number GRM155R61H105KE05D
D19, D20, D21: SC1205-01ETG; SC120501ETG; Part Number SC1205-01ETG
J7: 22-28-4044; HDRV3W66P0X254_1X4_762X249X1042P; Part Number 22-28-4044; not fitted
LED2: SML-P11VTT86R; SMLP11VTT86R; Part Number SML-P11VTT86R
Q1, Q2, Q3, Q4, Q5, Q6, Q9: BC817-40,215; BC81740215; Part Number BC817-40,215
R29, R30, R40, R41, R42, R43, R44, R45, R46, R49, R52, R54: 10K; RC0402N_YAG; Part Number RC0402JR-0710KL
R31: 0R; RESC2012X50N; Part Number CRCW08050000Z0EA
R32, R36, R37, R38, R39: 1K; RC0402N_YAG; Part Number RC0402JR-071KL
R33: 4K7; RC0402N_YAG; Part Number RC0402JR-074K7L
R34: 20K; RC0402N_YAG; Part Number RC0402JR-0720KL
R35: 27K; RC0402N_YAG; Part Number RC0402JR-0727KL
S1, S2, S3: 436333033816; Part Number 436333033816
TP17, TP18, TP19, TP20, TP21, TP22, TP23, TP24, TP25, TP26, TP42, TP43: TestPoint; TestPoint_Pad_D1.0mm
U1: SC206EEMDA-G51-UGNDA; SC200E_SC206E; Part Number SC200EEMNA-E53-UGNDA
U10: SGM804; SOT-23-5_L2.9-W1.6-P0.95-LS2.8-BL; Part Number SGM804-2.93YN5G/TR

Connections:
3V8: LED2.2 (A); also elsewhere on the board
/Interfaces/ADC: J7.3, U1.128 (ADC)
/Interfaces/CAM0_IN: Q6.3 (C), R46.2, U1.108 (GPIO_33)
/Interfaces/CAM1_IN: Q9.3 (C), R54.2, U1.109 (GPIO_34)
/Interfaces/GPIO_31: Q4.3 (C), R45.2, U1.97 (GPIO_31)
/Interfaces/GPIO_103: R39.2, U1.103 (GPIO_103)
/Interfaces/IN1: J7.1, R40.2
/Interfaces/LED1: R29.2, U1.267 (GPIO_111)
/Interfaces/OUT1: J7.2, Q5.3 (C)
/Interfaces/PWRKEY: R31.1, R36.1, U1.114 (PWRKEY)
/Interfaces/VOL_DOWN/I2C_SCL: R37.1, U1.96 (VOL_DOWN)
/Interfaces/VOL_UP/I2C_SDA: R38.1, U1.95 (VOL_UP)
AUDIO_EN: U1.113 (GPIO_58); also elsewhere on the board
CAM0_EN: U1.264 (REAR_CAM_EN/GPIO_100); also elsewhere on the board
CAM0_IR_CUT_GPIO: R41.2; also elsewhere on the board
CAM1_EN: U1.239 (FRONT_CAM_EN/GPIO_101); also elsewhere on the board
CAM1_IR_CUT_GPIO: R49.2; also elsewhere on the board
Flash LED: U1.180 (FLASH_LED); also elsewhere on the board
GND: C51.2, C52.2, D19.1, D20.1, D21.1, J7.4, Q1.2 (E), Q2.2 (E), Q3.2 (E), Q4.2 (E), Q5.2 (E), Q6.2 (E), Q9.2 (E), R30.1, R34.2, R42.1, R43.1, R44.1, R52.1, S1.1, S1.3, S2.1, S2.3, S3.1, S3.3, U10.3 (GND); also elsewhere on the board
GPIO28_MCU_IN: U1.33 (GPIO_28); also elsewhere on the board
LDO15A_1V8: R45.1, R46.1, R54.1; also elsewhere on the board
unnamed: D19.2, R36.2, S1.2
unnamed: D20.2, R37.2, S2.2
unnamed: D21.2, R38.2, S3.2
unnamed: LED2.1 (K), R32.1
unnamed: Q1.1 (B), Q3.3 (C), R33.2
unnamed: Q1.3 (C), R31.2
unnamed: Q2.1 (B), R29.1, R30.2
unnamed: Q2.3 (C), R32.2
unnamed: Q3.1 (B), R34.1, R35.2
unnamed: Q4.1 (B), R40.1, R43.2
unnamed: Q5.1 (B), R39.1, R42.2
unnamed: Q6.1 (B), R41.1, R44.2
unnamed: Q9.1 (B), R49.1, R52.2
unnamed: TP17.1, U1.195 (CHG_LED)
unnamed: TP43.1, U1.99 (GPIO_32)
unnamed: TP20.1, U1.265 (GPIO_98)
unnamed: TP21.1, U1.105 (GPIO_99)
unnamed: TP22.1, U1.104 (GPIO_102)
unnamed: TP42.1, U1.90 (GPIO_106)
unnamed: TP18.1, U1.91 (SENSOR_I2C_SCL)
unnamed: TP19.1, U1.92 (SENSOR_I2C_SDA)
unnamed: TP25.1, U1.116 (SPI_CLK/GPIO_16)
unnamed: TP26.1, U1.117 (SPI_CS_N/GPIO_17)
unnamed: TP23.1, U1.118 (SPI_MISO/GPIO_14)
unnamed: TP24.1, U1.119 (SPI_MOSI/GPIO_15)
unnamed: R35.1, U10.1 (RESET#)
unnamed: C52.1, U10.5 (SRT)
VBAT: C51.1, R33.1, U10.2 (VCC); also elsewhere on the board

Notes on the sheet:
Inputs/Outputs
LEDs
PWRKEY
Keypad
Camera Inputs
Connectors

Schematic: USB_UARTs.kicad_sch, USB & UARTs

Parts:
C31, C35, C41, C112, C113: 1uF 50V; CAPC1005X55N; Part Number GRM155R61H105KE05D
C32, C40, C111: 100nF 10V; CAPC1005X55N; Part Number GRM155R71A104KA01D
C38: 10nF 50V; CAPC1005X55N; Part Number GRM155R71H103KA88D
C42: 4.7uF 10V; CAPC1608X90N; Part Number LMK107BJ475KA-T
D1: 1N4148WS; SODFL2512X90N; Part Number 1N4148WS
D9: SC1205-01ETG; SC120501ETG; Part Number SC1205-01ETG
D11, D18: SP0402U-ULC-02ETG; SESD0402Q2UG0020090; Part Number SP0402U-ULC-02ETG
D12: SC1105-01UTG; SC110501UTG; Part Number SC1105-01UTG
J3: 67996-100HLF; HDRV2W67P254_2X1_254X483X858P; Part Number 67996-100HLF
J5: 22-28-4034; HDRV3W66P0X254_1X3_762X249X1042P; Part Number 22-28-4034
J6: 2345986-1; TE_2345986-1; Part Number 2345986-1
Q7: BC817-40,215; BC81740215; Part Number BC817-40,215
R20: 0R; RESC2012X50N; Part Number CRCW08050000Z0EA; not fitted
R21, R24: 10K; RC0402N_YAG; Part Number RC0402JR-0710KL
R22: 100K; RC0402N_YAG; Part Number RC0402JR-07100KL
R23: 10K; RC0402N_YAG; Part Number RC0402JR-0710KL; not fitted
R104: 56K; RC0402N_YAG; Part Number RC0402JR-0756KL
R109: 5K1; RC0402N_YAG; Part Number RC0402JR-075K1L
R112: 0R; RESC2012X50N; Part Number CRCW08050000Z0EA
S4: JS102011JCQN; SW_JS102011JCQN; Part Number JS102011JCQN
TP12, TP13, TP14, TP44, TP45, TP50, TP51: TestPoint; TestPoint_Pad_D1.0mm
U1: SC206EEMDA-G51-UGNDA; SC200E_SC206E; Part Number SC200EEMNA-E53-UGNDA
U7, U9: PI3USB4000DZUAEX; Part Number PI3USB4000DZUAEX

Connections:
3V8: C31.1, C32.1, C111.1, C112.1, U7.10 (VDD), U9.10 (VDD); also elsewhere on the board
/USB_UARTs/SC206E_CC1: U1.249 (USB_CC1), U9.8 (C0+)
/USB_UARTs/SC206E_USB_D_N: U1.13 (USB_DM), U7.7 (C0-)
/USB_UARTs/SC206E_USB_D_P: U1.14 (USB_DP), U7.8 (C0+)
/USB_UARTs/TypeC_USB_D_N: D18.1 (K_1), J6.A7 (DN1), J6.B7 (DN2), U7.4 (L1-)
/USB_UARTs/TypeC_USB_D_P: D18.2 (K_2), J6.A6 (DP1), J6.B6 (DP2), U7.3 (L1+)
/USB_UARTs/USB_SW: C38.1, R22.1, R112.1, S4.3, TP51.1, U7.9 (SEL), U9.9 (SEL)
GND: C31.2, C32.2, C35.2, C38.2, C40.2, C41.2, C42.2, C111.2, C112.2, C113.2, D9.2, D11.3 (GND), D12.2 (A), D18.3 (GND), J5.3, J6.A1 (GND_A), J6.A12 (GND_A__1), J6.B1 (GND_B), J6.B12 (GND_B__1), J6.SH1 (SHIELD), J6.SH2 (SHIELD__1), J6.SH3 (SHIELD__2), J6.SH4 (SHIELD__3), Q7.2 (E), R22.2, R109.2, U7.5 (GND), U9.5 (GND); also elsewhere on the board
LDO15A_1V8: R23.1, R24.2; also elsewhere on the board
NVMe_USB_D_N: U7.2 (L0-); also elsewhere on the board
NVMe_USB_D_P: U7.1 (L0+); also elsewhere on the board
NVMe_USB_EN: Q7.3 (C), TP50.1; also elsewhere on the board
unnamed: D11.1 (K_1), J5.2, R23.2, U1.93 (DBG_UART4_RXD)
unnamed: D11.2 (K_2), J5.1, U1.94 (DBG_UART4_TXD)
unnamed: J3.2, R24.1
unnamed: Q7.1 (B), R112.2
unnamed: R21.2, S4.2
unnamed: TP12.1, U1.36 (UART0_CTS/I2C_SDA)
unnamed: TP13.1, U1.37 (UART0_RTS/I2C_SCL)
unnamed: TP45.1, U1.153 (UART1_RXD)
unnamed: TP44.1, U1.154 (UART1_TXD)
unnamed: D9.1, J3.1, U1.46 (USB_BOOT)
unnamed: R20.1, U1.246 (USB_CC2)
unnamed: C35.1, U7.6 (REF)
unnamed: R109.1, U9.1 (L0+)
unnamed: R104.1, U9.3 (L1+)
unnamed: C113.1, U9.6 (REF)
SC206E_USB_SS1_RX_N: U1.270 (USB_SS1_RX_M); also elsewhere on the board
SC206E_USB_SS1_RX_P: U1.252 (USB_SS1_RX_P); also elsewhere on the board
SC206E_USB_SS1_TX_N: U1.253 (USB_SS1_TX_M); also elsewhere on the board
SC206E_USB_SS1_TX_P: U1.254 (USB_SS1_TX_P); also elsewhere on the board
SC206E_USB_SS2_RX_N: U1.192 (USB_SS2_RX_M); also elsewhere on the board
SC206E_USB_SS2_RX_P: U1.152 (USB_SS2_RX_P); also elsewhere on the board
SC206E_USB_SS2_TX_N: U1.151 (USB_SS2_TX_M); also elsewhere on the board
SC206E_USB_SS2_TX_P: U1.150 (USB_SS2_TX_P); also elsewhere on the board
TypeC_VBUS: D1.2 (A), J6.A4 (VBUS_A), J6.A9 (VBUS_A__1), J6.B4 (VBUS_B), J6.B9 (VBUS_B__1), R21.1, R104.2; also elsewhere on the board
UART0_RXD: U1.35 (UART0_RXD/GPIO_3); also elsewhere on the board
UART0_TXD: U1.34 (UART0_TXD/GPIO_2); also elsewhere on the board
VUSB_BUS: C40.1, C41.1, C42.1, D1.1 (K), D12.1 (K), TP14.1, U1.141 (USB_VBUS), U1.142 (USB_VBUS)

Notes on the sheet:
CC1=5K1 Pull-down ==> SC206 Host CC1=56K Pull-up ==> SC206 Device
USB Switches
Operation mode Select (when SEL=0: C0→L0, when SEL=1: C0→L1)
Type-C
Debug UART

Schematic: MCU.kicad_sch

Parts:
C82, C83: 15pF 50V; CAPC1005X55N; Part Number GRM1555C1H150JA01D
C84, C85, C88, C89, C90, C91, C92, C93, C94, C95: 100nF 10V; CAPC1005X55N; Part Number GRM155R71A104KA01D
C86, C87: 1uF 50V; CAPC1005X55N; Part Number GRM155R61H105KE05D
C96, C97: 1nF 50V; CAPC1005X55N; Part Number GRM1555C1H102JA01D
IC1: W25Q128JVSIM; SOIC127P790X216-8N; Part Number W25Q128JVSIM
J4: CONN-SMD_1.25-4PLT; Part Number 1.25-4P LT
J19: 2174507-2; 21745072; Part Number 2174507-2
J21: 67996-100HLF; HDRV2W67P254_2X1_254X483X858P; Part Number 67996-100HLF
J23, J26: CONN-SMD_1.25-4PLT; Part Number 1.25-4P LT; not fitted
Q8, Q10, Q11: BC817-40,215; BC81740215; Part Number BC817-40,215
R28, R47, R48, R97, R98: 10K; RC0402N_YAG; Part Number RC0402JR-0710KL
R50: 0R; RESC2012X50N; Part Number CRCW08050000Z0EA
R91, R95: 1K; RC0402N_YAG; Part Number RC0402JR-071KL
R92: 10K; RC0402N_YAG; Part Number RC0402JR-0710KL; not fitted
R93, R94: 27.4R; RC0402N_YAG; Part Number RC0402FR-0727R4P
R96, R99: 4K7; RC0402N_YAG; Part Number RC0402JR-074K7L
TP33, TP34, TP35, TP36, TP46, TP47, TP48, TP49: TestPoint; TestPoint_Pad_D1.0mm
U12: RP2040; QFN40P700X700X90-57N-D; Part Number SC0914(7)
Y1: ABM8-272-T3; ABM8272T3; Part Number ABM8-272-T3

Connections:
/MCU/ADC0: J26.1, U12.38 (GPIO26_ADC0)
/MCU/ADC1: J26.2, U12.39 (GPIO27_ADC1)
/MCU/ADC2: J26.3, U12.40 (GPIO28_ADC2)
/MCU/ADC3: J26.4, U12.41 (GPIO29_ADC3)
/MCU/GPIO4: J23.1, U12.6 (GPIO4)
/MCU/GPIO5: J23.2, U12.7 (GPIO5)
/MCU/GPIO6: J23.3, U12.8 (GPIO6)
/MCU/GPIO7: J23.4, U12.9 (GPIO7)
/MCU/MCU_OUT: R28.2, U12.37 (GPIO25)
/MCU/MCU_UART_RX: Q11.3 (C), R98.2, U12.3 (GPIO1)
/MCU/MCU_UART_TX: Q10.2 (E), U12.2 (GPIO0)
/MCU/MCU_USB_N: R94.1, U12.46 (USB_DM)
/MCU/MCU_USB_P: R93.1, U12.47 (USB_DP)
/MCU/QSPI_SCLK: IC1.6 (CLK), U12.52 (QSPI_SCLK)
/MCU/QSPI_SD0: IC1.5 (DI_(IO0)), U12.53 (QSPI_SD0)
/MCU/QSPI_SD1: IC1.2 (DO_(IO1)), U12.55 (QSPI_SD1)
/MCU/QSPI_SD2: IC1.3 (~WP_(IO2)), U12.54 (QSPI_SD2)
/MCU/QSPI_SD3: IC1.7 (~HOLD_OR_/RESET_(IO3)), U12.51 (QSPI_SD3)
/MCU/QSPI_SS: IC1.1 (~CS), R91.1, R92.2, U12.56 (QSPI_SS)
/MCU/RUN: J4.4, U12.26 (RUN)
/MCU/SWCLK: J4.1, U12.24 (SWCLK)
/MCU/SWD: J4.2, U12.25 (SWD)
/MCU/USB_BOOT: J21.2, R91.2
GND: C82.2, C83.2, C84.2, C85.2, C86.2, C87.2, C88.2, C89.2, C90.2, C91.2, C92.2, C93.2, C94.2, C95.2, IC1.4 (GND), J4.3, J4.5, J4.6, J19.5, J19.MP1, J19.MP2, J19.MP3, J19.MP4, J19.MP5, J19.MP6, J21.1, J23.5, J23.6, J26.5, J26.6, Q8.2 (E), R47.1, U12.19 (TESTEN), U12.57 (GND), Y1.2, Y1.4; also elsewhere on the board
GPIO28_MCU_IN: R50.2; also elsewhere on the board
LDO15A_1V8: C96.2, C97.2, R48.1, R96.1, R97.1, R99.1; also elsewhere on the board
unnamed: C83.1, R95.2, Y1.3
unnamed: J19.1, TP34.1
unnamed: J19.2, R94.2
unnamed: J19.3, R93.2
unnamed: J19.4, TP33.1
unnamed: Q8.1 (B), R28.1, R47.2
unnamed: Q8.3 (C), R48.2, R50.1
unnamed: C96.1, Q10.1 (B), R96.2
unnamed: C97.1, Q11.1 (B), R99.2
unnamed: TP35.1, U12.4 (GPIO2)
unnamed: TP36.1, U12.5 (GPIO3)
unnamed: TP46.1, U12.15 (GPIO12)
unnamed: TP47.1, U12.16 (GPIO13)
unnamed: TP48.1, U12.17 (GPIO14)
unnamed: TP49.1, U12.18 (GPIO15)
unnamed: C84.1, C85.1, C86.1, U12.23 (DVDD), U12.45 (VREG_VOUT), U12.50 (DVDD)
unnamed: C82.1, U12.20 (XIN), Y1.1
unnamed: R95.1, U12.21 (XOUT)
UART0_RXD: Q10.3 (C), R97.2; also elsewhere on the board
UART0_TXD: Q11.2 (E); also elsewhere on the board
VREG_3V3: C87.1, C88.1, C89.1, C90.1, C91.1, C92.1, C93.1, C94.1, C95.1, IC1.8 (VCC), R92.1, R98.1, U12.1 (IOVDD), U12.10 (IOVDD), U12.22 (IOVDD), U12.33 (IOVDD), U12.42 (IOVDD), U12.43 (ADC_AVDD), U12.44 (VREG_IN), U12.48 (USB_VDD), U12.49 (IOVDD); also elsewhere on the board

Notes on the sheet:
micro-B USB

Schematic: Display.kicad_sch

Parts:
U1: SC206EEMDA-G51-UGNDA; SC200E_SC206E; Part Number SC200EEMNA-E53-UGNDA

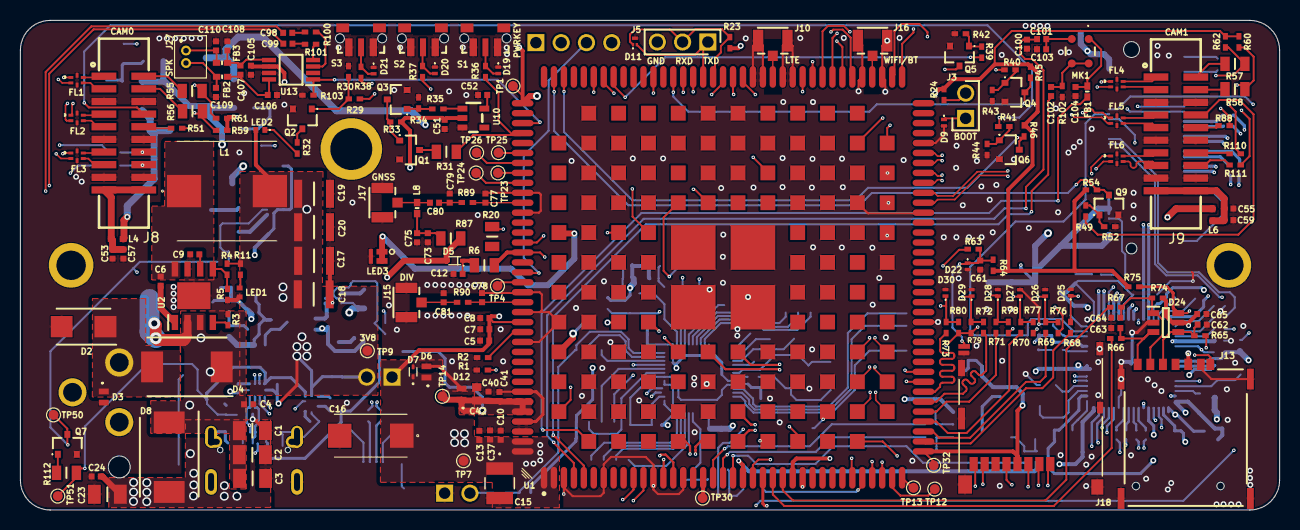
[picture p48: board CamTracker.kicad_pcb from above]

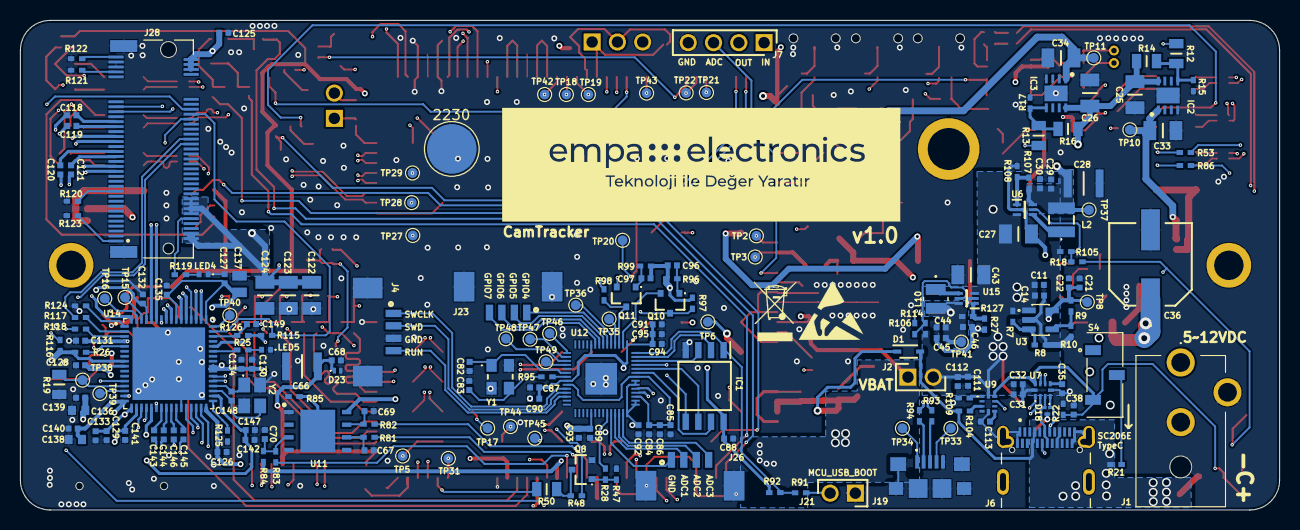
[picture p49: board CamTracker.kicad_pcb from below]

Board: 6 copper layers, 126.6 x 49.2 mm, 411 parts (206 on the bottom side), 307 nets.

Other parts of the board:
2230: TestPoint_Pad_D3.0mm
M701, M701#2: M.2 Solder Nut; MountingHole_3mm_Pad
v1.0: LOGO; Logo_EMPA_Official

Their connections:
GND: 2230.1, M701.1, M701#2.1; also elsewhere on the board

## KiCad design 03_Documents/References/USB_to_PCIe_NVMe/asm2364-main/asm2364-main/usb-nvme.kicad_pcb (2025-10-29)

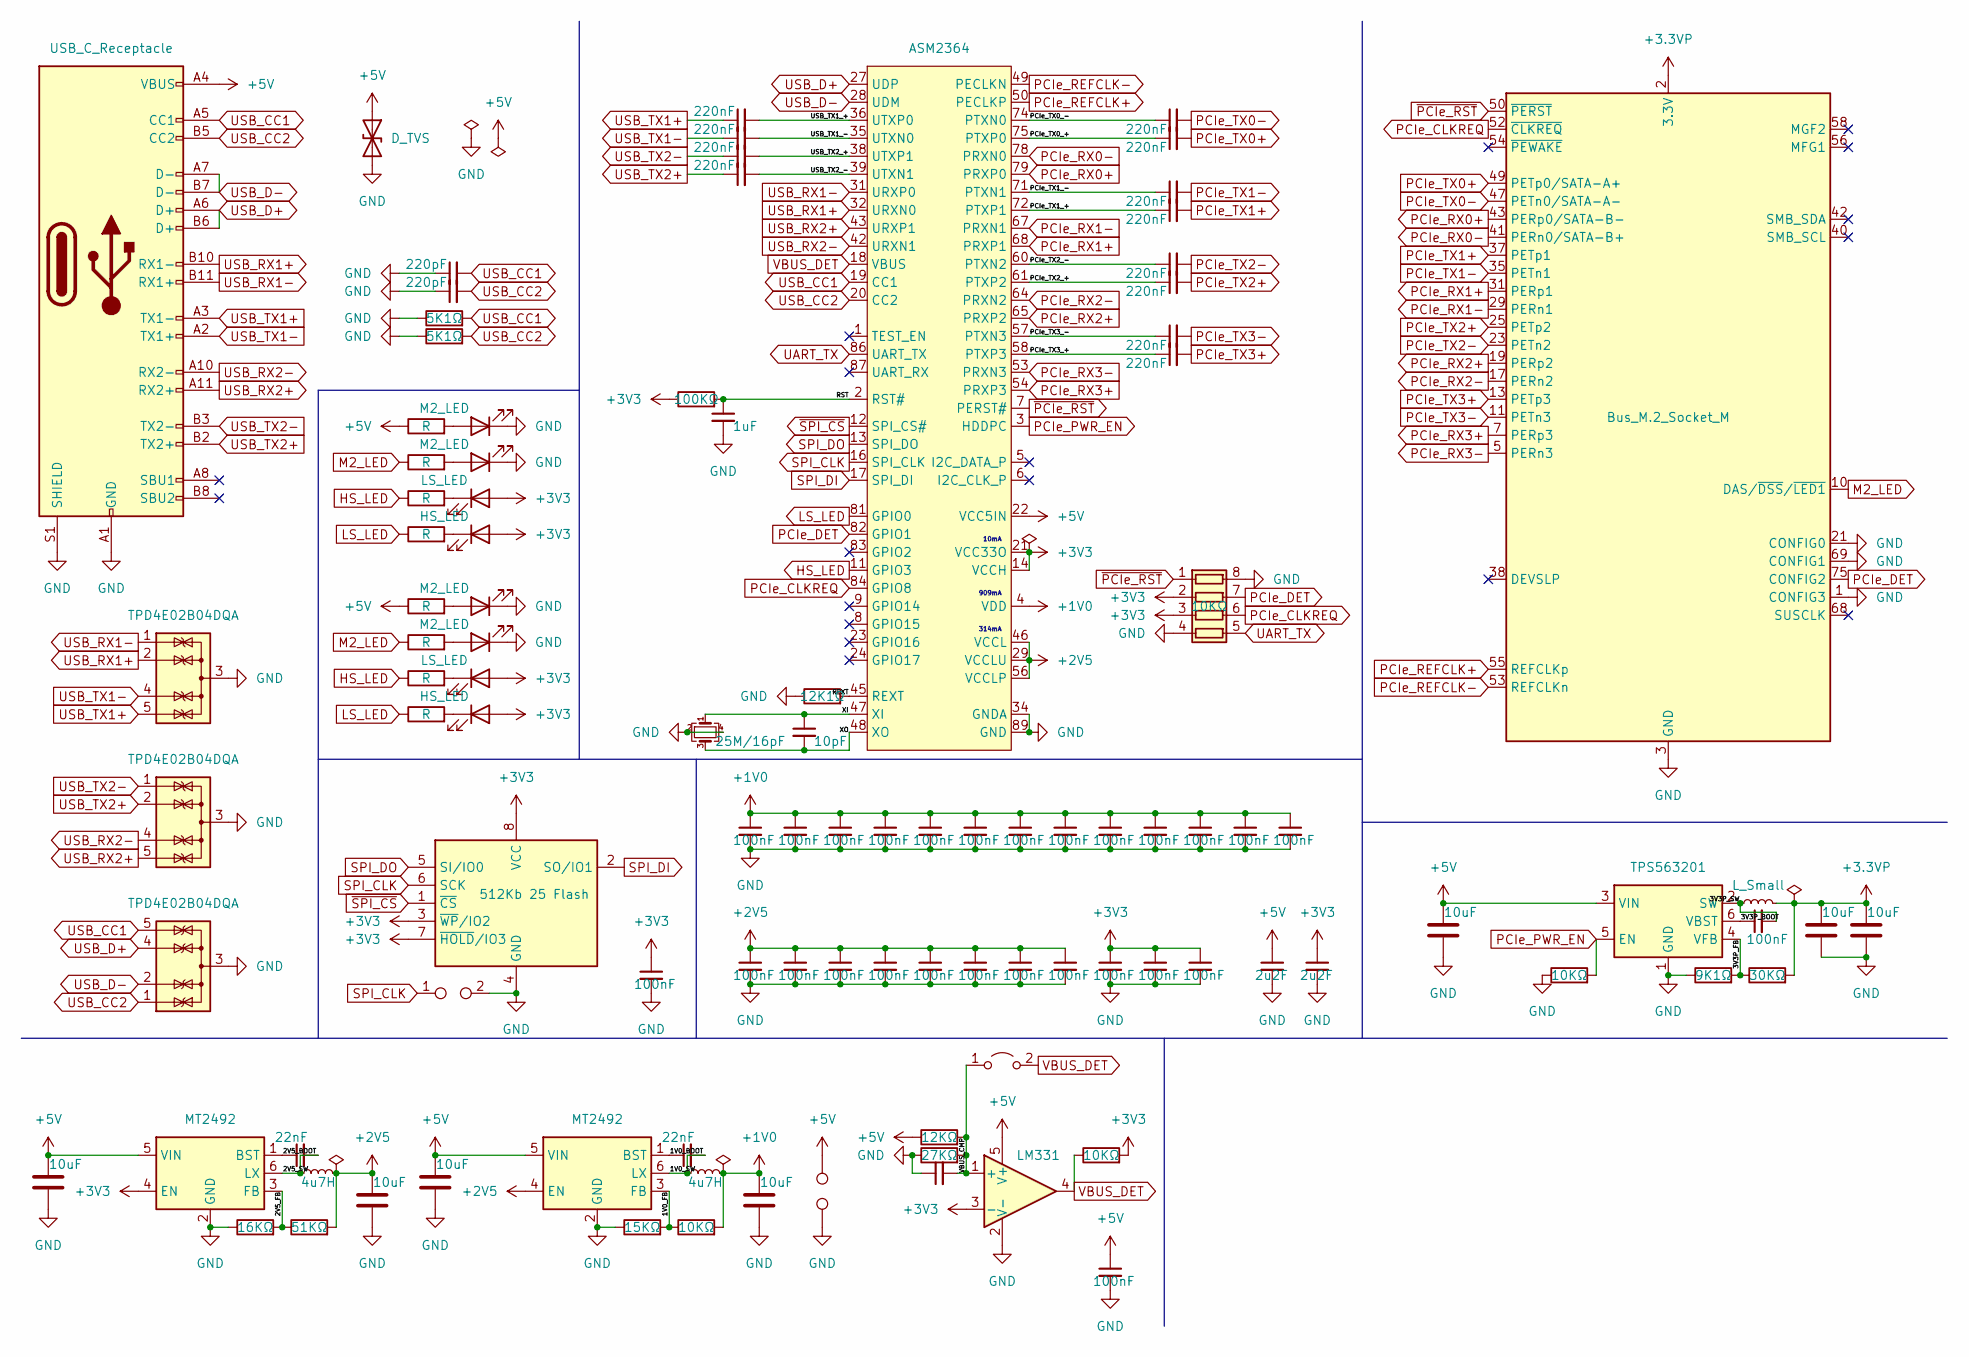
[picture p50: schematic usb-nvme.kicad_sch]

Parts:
C1, C2, C3, C4, C5, C6, C7, C8, C9, C11, C13, C14: 220nF; C_0201_0603Metric
C10, C12: 220pF; C_0201_0603Metric
C15: 1uF; C_0402_1005Metric
C16: 10pF; C_0201_0603Metric
C17, C18, C19, C20, C21, C22, C23, C24, C25, C26, C27, C28, C29, C30, C34, C35, C36, C37, C38, C39, C40, C41, C42, C43, C44, C47, C50, C55: 100nF; C_0201_0603Metric
C31, C32, C33, C51, C52, C53, C54: 10uF; C_0603_1608Metric
C45, C46: 2u2F; C_0402_1005Metric
C48, C49: 22nF; C_0201_0603Metric
D1: D_TVS; D_SOD-323
D2, D3, D6, D7: M2_LED; LED_0402_1005Metric
D4, D8: LS_LED; LED_0402_1005Metric
D5, D9: HS_LED; LED_0402_1005Metric
J1: USB_C_Receptacle; USB_C_Receptacle_GCT_USB4080-03-A
J2: Bus_M.2_Socket_M; M.2-M
JP1: Jumper; SolderJumper-2_1.2x0.6mm
L1: L_Small; L_Vishay_IHLP-1616
L2, L3: 4u7H; L_1008_2520Metric
R1, R2: 5K1Ω; R_0201_0603Metric
R3: 100KΩ; R_0201_0603Metric
R4, R5, R6, R7, R8, R9, R10, R12: R; R_0201_0603Metric
R11: 12K1Ω; R_0201_0603Metric
R13, R18, R22: 10KΩ; R_0201_0603Metric
R14: 9K1Ω; R_0201_0603Metric
R15: 30KΩ; R_0201_0603Metric
R16: 12KΩ; R_0201_0603Metric
R17: 27KΩ; R_0201_0603Metric
R19: 16KΩ; R_0201_0603Metric
R20: 51KΩ; R_0201_0603Metric
R21: 15KΩ; R_0201_0603Metric
RN1: 10KΩ; R_Array_Convex_4x0402
TP1: TestPoint_2Pole; R_0201_0603Metric
TP2, TP3: TestPoint; TestPoint_THTPad_2.0x2.0mm_Drill1.0mm
U1: ASM2364; QFN-88_EP_9.75x9.75_Pitch0.4mm_ThermalVias
U2, U3, U6: TPD4E02B04DQA; USON-10_2.5x1.0mm_P0.5mm
U4: 512Kb 25 Flash; DFN-8-1EP_3x2mm_P0.5mm_EP1.3x1.5mm
U5: TPS563201; SOT-23-6
U7, U8: MT2492; SOT-23-6
U9: LM331; SOT-353_SC-70-5
Y1: 25M/16pF; Crystal_SMD_2016-4Pin_2.0x1.6mm

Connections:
+1V0: C17.1, C18.1, C19.1, C20.1, C21.1, C22.1, C23.1, C24.1, C25.1, C26.1, C27.1, C28.1, C29.1, C54.1, L3.2, R22.2, U1.4 (VDD), U1.10 (VDD), U1.15 (VDD), U1.25 (VDD), U1.30 (VDD), U1.37 (VDD), U1.44 (VDD), U1.51 (VDD), U1.52 (VDD), U1.59 (VDD), U1.66 (VDD), U1.73 (VDD), U1.80 (VDD), U1.85 (VDD)
+2V5: C34.1, C35.1, C36.1, C37.1, C38.1, C39.1, C40.1, C41.1, C53.1, L2.2, R20.2, U1.29 (VCCLU), U1.33 (VCCLU), U1.41 (VCCLU), U1.46 (VCCL), U1.56 (VCCLP), U1.62 (VCCLP), U1.70 (VCCLP), U1.76 (VCCLP), U8.4 (EN)
+3.3VP: C32.1, C33.1, J2.0, J2.2 (3.3V), J2.4 (3.3V), J2.12 (3.3V), J2.14 (3.3V), J2.16 (3.3V), J2.18 (3.3V), J2.70 (3.3V), J2.72 (3.3V), J2.74 (3.3V), L1.2, R15.2
+3V3: C42.1, C43.1, C44.1, C46.1, C47.1, D4.2 (A), D5.2 (A), D8.2 (A), D9.2 (A), R3.1, R18.2, RN1.2 (R2.1), RN1.3 (R3.1), U1.14 (VCCH), U1.21 (VCC33O), U1.26 (VCCH), U1.88 (VCCH), U4.3 (~WP/IO2), U4.7 (~HOLD/IO3), U4.8 (VCC), U7.4 (EN), U9.3 (-)
+5V: C31.1, C45.1, C51.1, C52.1, C55.1, D1.1 (A1), J1.A4 (VBUS), J1.A9 (VBUS), J1.B4 (VBUS), J1.B9 (VBUS), J2.0, R4.1, R8.1, R16.1, TP2.1, U1.22 (VCC5IN), U5.3 (VIN), U7.5 (VIN), U8.5 (VIN), U9.5 (V+)
/1V0_BOOT: C49.1, U8.1 (BST)
/1V0_FB: R21.2, R22.1, U8.3 (FB)
/1V0_SW: C49.2, L3.1, U8.6 (LX)
/2V5_BOOT: C48.1, U7.1 (BST)
/2V5_FB: R19.2, R20.1, U7.3 (FB)
/2V5_SW: C48.2, L2.1, U7.6 (LX)
/3V3P_BOOT: C30.1, U5.6 (VBST)
/3V3P_FB: R14.2, R15.1, U5.4 (VFB)
/3V3P_SW: C30.2, L1.1, U5.2 (SW)
/PCIe_TX0_+: C4.1, U1.75 (PTXP0)
/PCIe_TX0_-: C2.1, U1.74 (PTXN0)
/PCIe_TX1_+: C8.1, U1.72 (PTXP1)
/PCIe_TX1_-: C7.1, U1.71 (PTXN1)
/PCIe_TX2_+: C11.1, U1.61 (PTXP2)
/PCIe_TX2_-: C9.1, U1.60 (PTXN2)
/PCIe_TX3_+: C14.1, U1.58 (PTXP3)
/PCIe_TX3_-: C13.1, U1.57 (PTXN3)
/REXT: R11.2, U1.45 (REXT)
/RST: C15.1, R3.2, U1.2 (RST#)
/USB_TX1_+: C1.2, U1.36 (UTXP0)
/USB_TX1_-: C3.2, U1.35 (UTXN0)
/USB_TX2_+: C5.2, U1.38 (UTXP1)
/USB_TX2_-: C6.2, U1.39 (UTXN1)
/VBUS_CMP: C50.2, JP1.1 (A), R16.2, R17.2, U9.1 (+)
/XI: C16.1, U1.47 (XI), Y1.1
/XO: C16.2, U1.48 (XO), Y1.3
GND: C10.1, C12.1, C15.2, C17.2, C18.2, C19.2, C20.2, C21.2, C22.2, C23.2, C24.2, C25.2, C26.2, C27.2, C28.2, C29.2, C31.2, C32.2, C33.2, C34.2, C35.2, C36.2, C37.2, C38.2, C39.2, C40.2, C41.2, C42.2, C43.2, C44.2, C45.2, C46.2, C47.2, C50.1, C51.2, C52.2, C53.2, C54.2, C55.2, D1.2 (A2), D2.1 (K), D3.1 (K), D6.1 (K), D7.1 (K), J1.A1 (GND), J1.A12 (GND), J1.B1 (GND), J1.B12 (GND), J1.S1 (SHIELD), J2.1 (CONFIG3), J2.3 (GND), J2.9 (GND), J2.15 (GND), J2.21 (CONFIG0), J2.27 (GND), J2.33 (GND), J2.39 (GND), J2.45 (GND), J2.51 (GND), J2.57 (GND), J2.69 (CONFIG1), J2.71 (GND), J2.73 (GND), R1.1, R2.1, R11.1, R13.1, R14.1, R17.1, R19.1, R21.1, RN1.4 (R4.1), RN1.8 (R1.2), TP1.2, TP3.1, U1.34 (GNDA), U1.40 (GNDA), U1.55 (GNDA), U1.63 (GNDA), U1.69 (GNDA), U1.77 (GNDA), U1.89 (GND), U2.3 (G), U2.8 (G), U3.3 (G), U3.8 (G), U4.4 (GND), U5.1 (GND), U6.3 (G), U6.8 (G), U7.2 (GND), U8.2 (GND), U9.2 (V-), Y1.2, Y1.4
HS_LED: R6.1, R10.1, U1.11 (GPIO3)
LS_LED: R7.1, R12.1, U1.81 (GPIO0)
M2_LED: J2.10 (DAS/~DSS/~LED1), R5.1, R9.1
unnamed: D2.2 (A), R4.2
unnamed: D3.2 (A), R5.2
unnamed: D4.1 (K), R6.2
unnamed: D5.1 (K), R7.2
unnamed: D6.2 (A), R8.2
unnamed: D7.2 (A), R9.2
unnamed: D8.1 (K), R10.2
unnamed: D9.1 (K), R12.2
PCIe_CLKREQ: J2.52 (~CLKREQ), RN1.6 (R3.2), U1.84 (GPIO8)
PCIe_DET: J2.75 (CONFIG2), RN1.7 (R2.2), U1.82 (GPIO1)
PCIe_PWR_EN: R13.2, U1.3 (HDDPC), U5.5 (EN)
PCIe_REFCLK+: J2.55 (REFCLKp), U1.50 (PECLKP)
PCIe_REFCLK-: J2.53 (REFCLKn), U1.49 (PECLKN)
PCIe_RX0+: J2.43 (PERp0/SATA-B-), U1.79 (PRXP0)
PCIe_RX0-: J2.41 (PERn0/SATA-B+), U1.78 (PRXN0)
PCIe_RX1+: J2.31 (PERp1), U1.68 (PRXP1)
PCIe_RX1-: J2.29 (PERn1), U1.67 (PRXN1)
PCIe_RX2+: J2.19 (PERp2), U1.65 (PRXP2)
PCIe_RX2-: J2.17 (PERn2), U1.64 (PRXN2)
PCIe_RX3+: J2.7 (PERp3), U1.54 (PRXP3)
PCIe_RX3-: J2.5 (PERn3), U1.53 (PRXN3)
PCIe_TX0+: C4.2, J2.49 (PETp0/SATA-A+)
PCIe_TX0-: C2.2, J2.47 (PETn0/SATA-A-)
PCIe_TX1+: C8.2, J2.37 (PETp1)
PCIe_TX1-: C7.2, J2.35 (PETn1)
PCIe_TX2+: C11.2, J2.25 (PETp2)
PCIe_TX2-: C9.2, J2.23 (PETn2)
PCIe_TX3+: C14.2, J2.13 (PETp3)
PCIe_TX3-: C13.2, J2.11 (PETn3)
SPI_CLK: TP1.1, U1.16 (SPI_CLK), U4.6 (SCK)
SPI_DI: U1.17 (SPI_DI), U4.2 (SO/IO1)
SPI_DO: U1.13 (SPI_DO), U4.5 (SI/IO0)
UART_TX: RN1.5 (R4.2), U1.86 (UART_TX)
USB_CC1: C10.2, J1.A5 (CC1), R1.2, U1.19 (CC1), U6.5 (IO4), U6.6 (IO4)
USB_CC2: C12.2, J1.B5 (CC2), R2.2, U1.20 (CC2), U6.1 (IO1), U6.10 (IO1)
USB_D+: J1.A6 (D+), J1.B6 (D+), U1.27 (UDP), U6.4 (IO3), U6.7 (IO3)
USB_D-: J1.A7 (D-), J1.B7 (D-), U1.28 (UDM), U6.2 (IO2), U6.9 (IO2)
USB_RX1+: J1.B10 (RX1-), U1.32 (URXN0), U2.2 (IO2), U2.9 (IO2)
USB_RX1-: J1.B11 (RX1+), U1.31 (URXP0), U2.1 (IO1), U2.10 (IO1)
USB_RX2+: J1.A11 (RX2+), U1.43 (URXP1), U3.5 (IO4), U3.6 (IO4)
USB_RX2-: J1.A10 (RX2-), U1.42 (URXN1), U3.4 (IO3), U3.7 (IO3)
USB_TX1+: C1.1, J1.A3 (TX1-), U2.5 (IO4), U2.6 (IO4)
USB_TX1-: C3.1, J1.A2 (TX1+), U2.4 (IO3), U2.7 (IO3)
USB_TX2+: C6.1, J1.B2 (TX2+), U3.2 (IO2), U3.9 (IO2)
USB_TX2-: C5.1, J1.B3 (TX2-), U3.1 (IO1), U3.10 (IO1)
VBUS_DET: JP1.2 (B), R18.1, U1.18 (VBUS), U9.4
~PCIe_RST: J2.50 (~PERST), RN1.1 (R1.1), U1.7 (PERST#)
~SPI_CS: U1.12 (SPI_CS#), U4.1 (~CS)

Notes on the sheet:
314mA
10mA
909mA

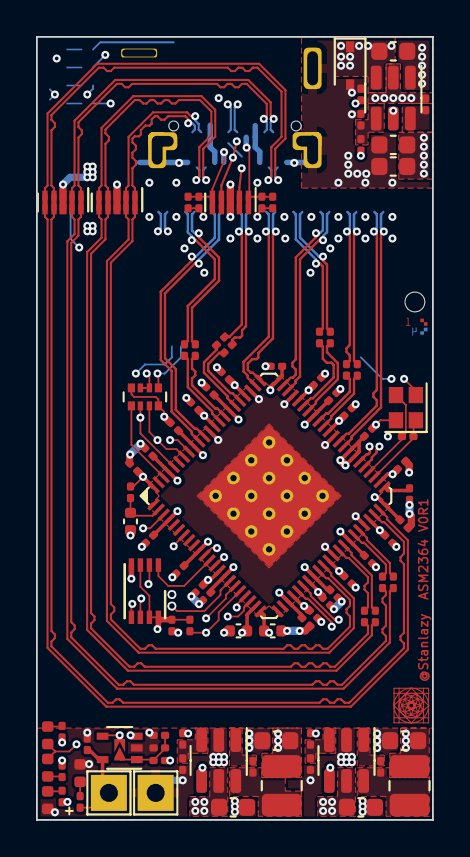
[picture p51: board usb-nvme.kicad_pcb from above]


Board: 4 copper layers, 22.0 x 43.5 mm, 106 parts (11 on the bottom side), 83 nets.

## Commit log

2025-10-18 feat: first commit with 5V DCDC
    [006841027000.STEP, 046841027100846+.stp, 0781710002.step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]
2025-10-29 feat: Completed Placement v1 in Layout
    [006841027000.STEP, 046841027100846+.stp, 0781710002.step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]
2025-10-30 feat(layout): Completed Placement v2
    Includes:
    - 3V8 DC-DC converter moved to the top layer
    - SIM and SD card positions rearranged
    [CamTracker.kicad_pcb, MCU.kicad_sch]
2025-10-30 feat(layout): Routed DP traces
    - Routed DP Camera/USB/PCIe
    - Routed SIM/SD
    - Routed ASM
    - Routed RP
    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
    [CamTracker.kicad_pcb, NVMe.kicad_sch]
2025-11-01 feat(layout): Routed almost all traces
2025-11-02 feat(layout): Completed routing of all traces but with Errors DRCs
    [CamTracker.kicad_pcb]
2025-11-03 feat(layout): Resolved all DRC Errors
    [CamTracker.kicad_pcb]
2025-11-05 feat(layout): Placed all references
    [CamTracker.kicad_pcb]
2025-11-09 feat(layout): matched DP trace lengths for signal integrity
    [CamTracker.kicad_pcb]
2025-11-10 feat(layout): Adjusted mounting holes and board edge copper
    [CamTracker.kicad_pcb]
2025-11-14 feat(layout): Completed v1.0 with old Camera Connector
    [CamTracker_v1.xls, EDI2CAP.CFG, SHF-108-01-L-D-SM-TR.stp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]
2025-11-16 feat(layout): Completed Layout Design with new Camera Connectors
    [1-2199230-4.stp, 20021521-00016T1LF.stp, CamTracker.kicad_pcb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]
2025-11-17 feat(PCB): Finalized design and generated Gerber files and BOM
    [2N7002.SchLib, 2N7002.stp, Antennas.kicad_sch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]
2025-12-01 feat(PCB): Added TE Connectivity connectors except the SD connector
    [1909763-1.psm, 1909763-1.stp, 1932788-1.STEP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]
2025-12-15 feat(PCB): Cam Connectors have been changed with 2x10P
    [CamTracker.kicad_pcb, Camera.kicad_sch, EDI2CAP.CFG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]
2025-12-18 feat(PCB): DC input Capacitor has been changed
    [16svpt560m.psm, 25SVPG270M.stp, CamTracker.kicad_pcb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]
2025-12-19 feat(PCB): Added GPIO IN to SC206E from the MCU
    [CamTracker.kicad_pcb, Interfaces.kicad_sch, MCU.kicad_sch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]
2025-12-22 feat(PCB): finalize PCB design and generate BOM/Gerbers
    [Antennas.kicad_sch, Audio.kicad_sch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]
2025-12-24 feat(PCB): Generated Pick and Placement file and pilot the Schematic
2025-12-26 feat(PCB): Updated NVME USB EN logic, turn-off the NVME 3V3 and 1V05 by EN pin
    [CamTracker-B_Cu.gbr, CamTracker-B_Mask.gbr, CamTracker-B_Paste.gbr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]
2026-04-01 Added To Be Fixed and Bring up Test Document
    [s6i46560a.drl, s6i46560a.gbl, s6i46560a.gbo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]
